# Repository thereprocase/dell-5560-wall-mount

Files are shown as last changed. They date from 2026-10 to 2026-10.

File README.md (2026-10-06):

# Laptop wall mount — Minimalist M1 and ducted Rev H

**9 September 2026 — Rev H D4 socket hotpatch:** [download and repair guide](https://thereprocase.github.io/dell-5560-wall-mount/revh-duct-d4.html). Corrects plastic crossing the four fan-cover pin sockets. Includes two Orca duct projects and the current editable CAD. Physical pin seating and removal still need confirmation. [Source and evidence](revh_duct_r4/README.md).

Two independent prototypes: **Minimalist M1** uses lighter open arms and fan
cradles with an optional indexed airflow dam; **Rev H** preserves the ducted
prototype and its already-printed arms. Future ducted revisions can change the
arms, size range and airflow adjustment too.

[Explore both designs](https://thereprocase.github.io/dell-5560-wall-mount/) ·
[Print and assembly guide](https://thereprocase.github.io/dell-5560-wall-mount/minimalist-guide.html)

## Rev H airflow videos - recorded continuation

**Moving particles and trails · about 1/200th speed · 60 fps:**
[Startup](https://thereprocase.github.io/dell-5560-wall-mount/simulation/revh-transient/sequence/latest-tracers.mp4) ·
[Already flowing](https://thereprocase.github.io/dell-5560-wall-mount/simulation/revh-transient/sequence/flowing/latest-tracers.mp4).

The startup continuation has stopped. Its native checkpoint and previous-step history are preserved for a later resume.
The startup video covers **96.2647 ms** of simulated flow.
The separate flowing-air video remains at 68.0934 ms.

| Simulation | Particle-flow video | Duration / download | Record |
|:--|:--|:--|:--|
| Startup | [MP4](https://thereprocase.github.io/dell-5560-wall-mount/simulation/revh-transient/sequence/latest-tracers.mp4) | 19.92 s / 4.31 MB | [Startup page](https://thereprocase.github.io/dell-5560-wall-mount/simulation/revh-transient/sequence/) |
| Already flowing | [MP4](https://thereprocase.github.io/dell-5560-wall-mount/simulation/revh-transient/sequence/flowing/latest-tracers.mp4) | 15.15 s / 3.46 MB | [Flowing page](https://thereprocase.github.io/dell-5560-wall-mount/simulation/revh-transient/sequence/flowing/) |

The videos use H.264 with fast-start metadata and one-second keyframes for
quick loading and seeking. The rounded speed label describes slow motion relative
to physical time; exact timing is recorded in each provenance file.

These stable links serve the latest published cumulative videos. The slower downloads have been retired. All recorded
samples and original videos remain preserved locally. Particle views interpolate saved
in-plane velocity at 60 fps; they show projected 2D motion with fading trails.
The visual continuation begins at the old 38.3188 ms video endpoint and uses
fixed 80.93 microsecond steps, one step per 60 fps video frame, with 12 workers.
CFD and video rendering are stopped. The run used idle priority and a shared
28 GiB RAM cap. Full native fields were saved at the final stop. Earlier native
branches and checkpoint provenance remain preserved. Timestep accuracy is deferred for this visual run;
the separate flowing-air sequence starts from an unconverged steady field.

## MakerWorld preparation package

[Agent handoff](MAKERWORLD_HANDOFF.md) · [Dated package, gallery, and downloads](makerworld/2026-09-08/)

Three listing drafts and sixty native Bambu Studio projects are archived while
physical prints and lab photographs are completed. The new profiles use 20%
gyroid infill and have virtual review only. All remain physically untested.

## Minimalist M1.1

[5560 native + print package](docs/downloads/Minimalist_M1_5560.zip) ·
[Fit coupon package](docs/downloads/Minimalist_M1_Fit_Coupons.zip) ·
[Editable nominal FreeCAD](minimalist/Laptop_Wall_Mount_Minimalist.FCStd) ·
[Six native size presets](minimalist/presets/) ·
[Construction and validation](minimalist/README.md)

The nominal complete set is **400.55 g / 15 h 42 m 30 s** in OrcaSlicer 2.4.2,
using P1S / ASA / 0.4 mm / 0.20 mm / 6 walls / 100% fill / 8 mm brim. That is
66.2% less estimated filament than the full Rev H set under the same process.
Times include each layout's plate overhead. These are slicer estimates, not
measured printing or cooling results.

Print one each of **01–08 plus 21_all_hardware**: nine plates. The twelve
individual files 09–20 are alternatives for replacement hardware, already
included on plate 21. STEP, STL and geometry-only 3MF are alternative formats.
The assembled STEP is for inspection. Keep the supplied print orientations.

All six dimensioned width/depth/thickness examples were recomputed at all nine
dam indices. Native geometry, intended 0.30 mm gaps, saved/reopened models,
STEP roundtrips, closed meshes and bed/brim/cutter clearance passed. Nominal
Orca paths have no disconnected floating components. The expanded screen
finds up to 8.99 mm of overhang-wall path without prior-layer support; the
bridge-tagged maximum is 3.02 mm. The coupon includes the fan-hanger and dam
slot interfaces in their full-part build directions. Physical fit, printed
retention, long-term ASA creep, anchors and cooling remain to be qualified.

### M1.1: carry the wall pad into the arm

Printing an arm on its side puts much of its load path within the layers, but
its wall pads extend beyond the arm’s 12 mm thickness. The original transition
left a small section just above that layer. The reinforcement grows each pad
from 24 to 32 mm tall and adds a pair of 6 mm webs, tapering 16 mm forward from
the pad face. Their roots run through the full arm thickness, including the
nearby window, so they begin at the bed instead of bridging onto a late layer.

| Original junction | Reinforced junction |
|---|---|
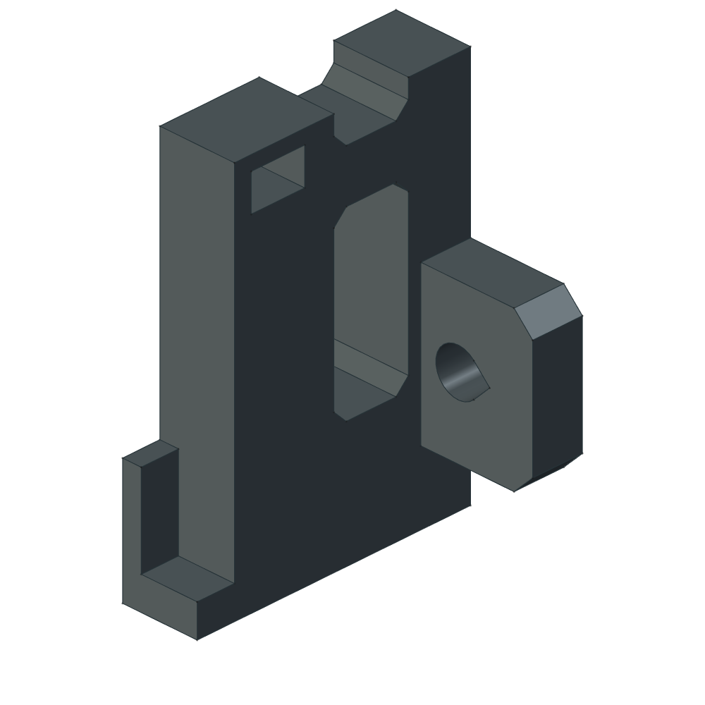
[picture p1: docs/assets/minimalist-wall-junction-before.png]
Original Minimalist wall pad and arm junction
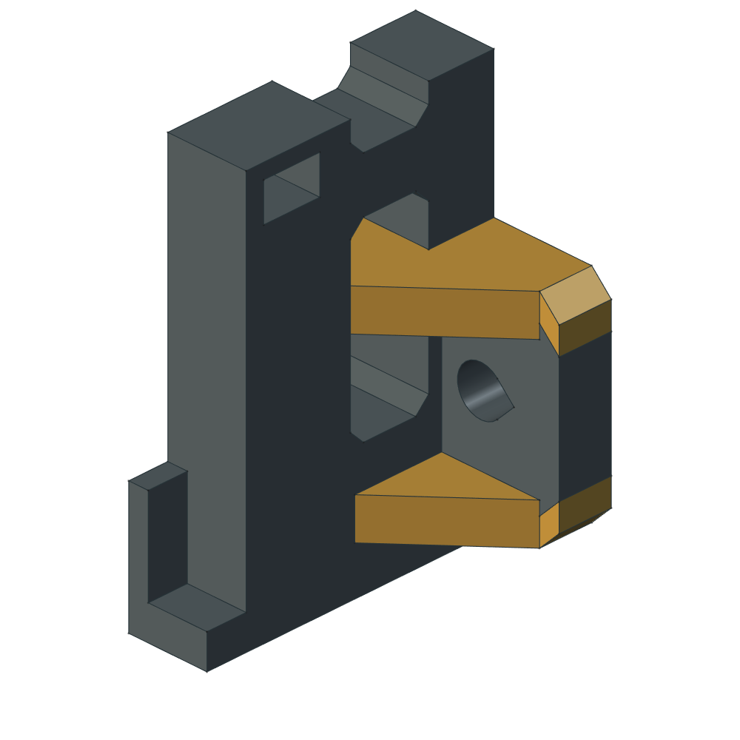
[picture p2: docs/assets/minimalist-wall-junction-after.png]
Reinforced junction with added material highlighted in gold
|  |  |

Gold shows added material in the native CAD comparison; the arm prints as one
fused part. Bolt centers and bores stay at their existing locations. The upper
dam has a matching tapered clearance notch so it can still traverse all nine
ladder positions. **Upgrade arms 01 and 02, plus dams 07 and 08 if using the dam**; the other sixteen
parts retain their geometry.

At a section just beyond the original 12 mm arm thickness, the material area
in each wall junction increases from **192 to approximately 416 mm²**. The
nominal arm pair adds **13.54 g of solid CAD** at 1.05 g/cm³. This is an area
comparison, not a claim of doubled tested strength: warm ASA, layer bonding,
fasteners and wall anchors still need physical qualification.

The revised complete set adds **12.50 g and 17 m 36 s** in Orca compared with
M1.0; the dam relief offsets a little of the extra arm material.

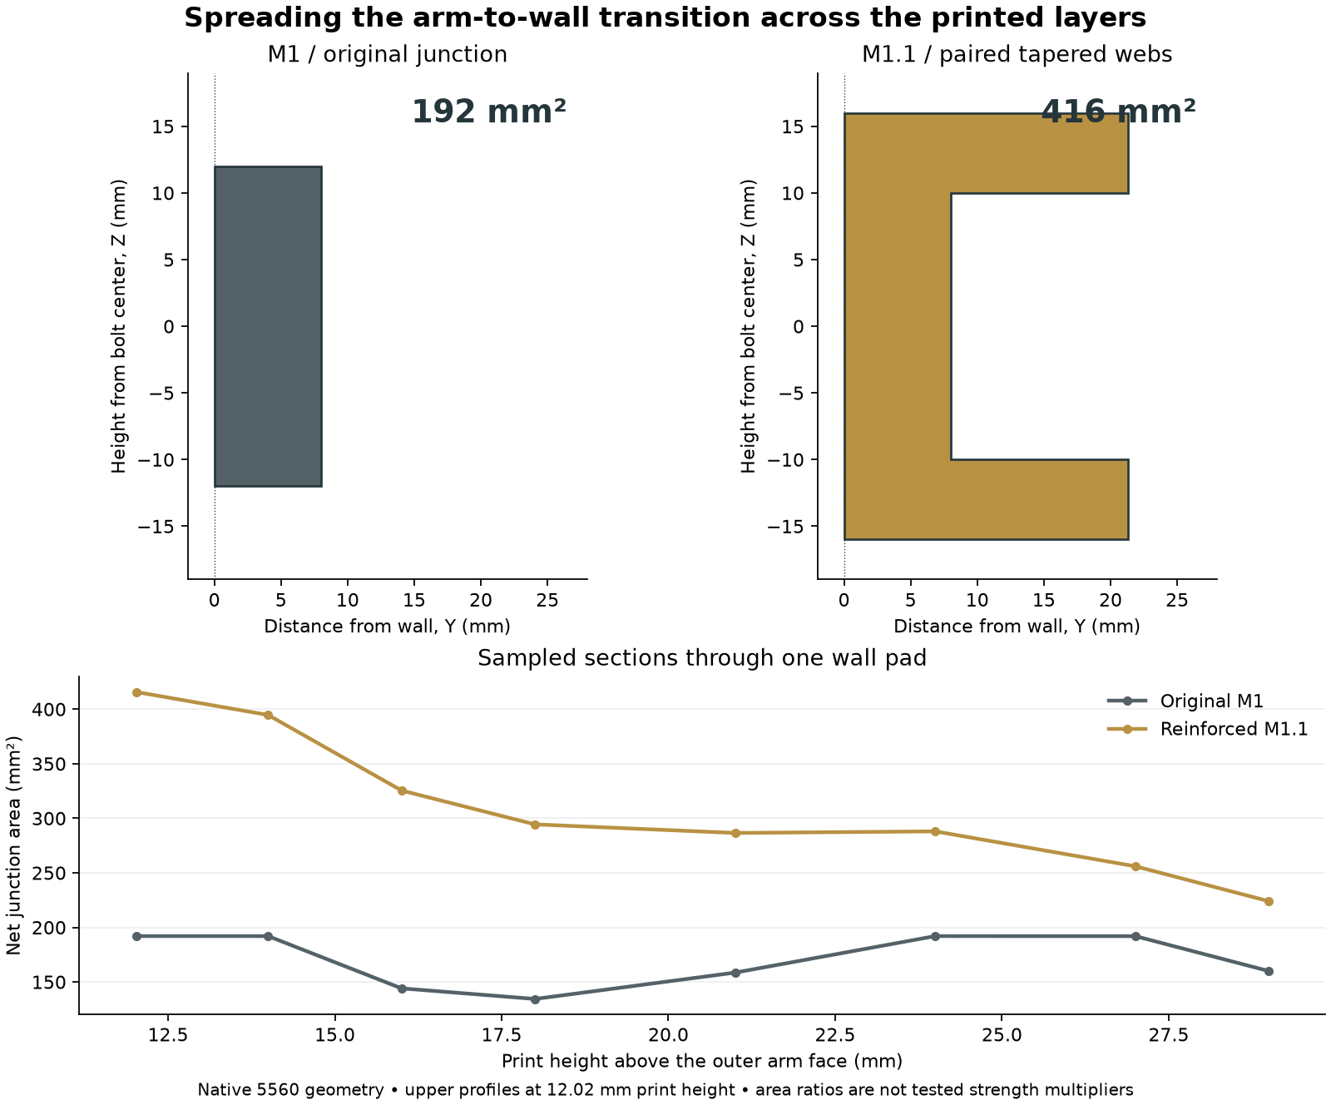
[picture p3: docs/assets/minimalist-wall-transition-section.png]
Actual print-layer sections before and after reinforcement


[Section data and assumptions](minimalist/reports/wall-transition-review.json) ·
[Native section calculation](minimalist/wall_transition_review.py)

## Ducted Rev H prototype

[All 14 print-oriented STEP files + corrected Orca previews](docs/downloads/Precision_5560_RevH_Prototype_STEP.zip) ·
[Orca bridge instructions](print_release_step/ORCA_BRIDGE_REVIEW.txt) ·
[STL/3MF print set](print_release/) ·
[Native FreeCAD](freecad/Precision_5560_Native.FCStd) ·
[Assembled STEP](freecad/Precision_5560_Native.step)

For ducts 03 and 04, keep the baked inlet-down orientation and set both
**Bridge direction and Internal bridge direction to 180°**, with Relative
bridge angle and Align infill direction to model off. Automatic direction
runs lengthwise along the slots. The corrected paths cross them, with a
maximum unsupported span of 5.19 mm and no disconnected floating components.
This is a toolpath screen, not an ASA bridge test. Re-slice for your spool.

The original `print_ready/`, root STEP, CadQuery source and Fusion/Onshape
ports remain **Revision F history/baselines**. Rev H's arm geometry is preserved
as prototype history; it is not a permanent constraint on later designs.

### H-R1: removable retention for your printed arms

[Interactive model and installation guide](https://thereprocase.github.io/dell-5560-wall-mount/revh-retainers.html) ·
[Four-part add-on and fit coupon](docs/downloads/Precision_5560_RevH_Removable_Retainers_R1.zip) ·
[Editable native model and engineering notes](revh_retention/)

Two external side bars and two keyed keepers retain the ducts and upper rails
without changing any of the fourteen Rev H parts. They engage existing arm
windows, so the already printed arms need no drilling or reprinting. Removing
one side bar releases both its duct and rail; support both while servicing.

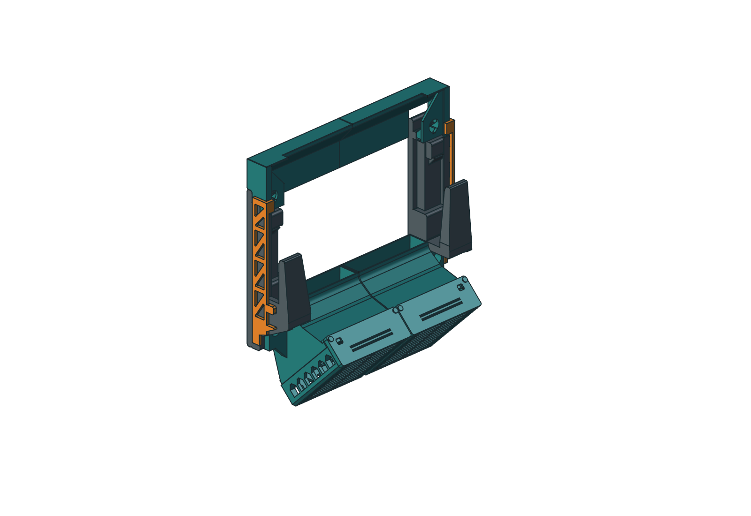
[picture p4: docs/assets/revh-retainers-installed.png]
Rev H with orange removable side bars and green keepers


Start with the short right-arm fit coupon. This is a CAD-checked prototype;
physical retention, bar stiffness and warm ASA creep still need testing.

### H-C1: edge-open fan cable grooves and zip-tie anchors

[Interactive cable-routing and print guide](https://thereprocase.github.io/dell-5560-wall-mount/revh-cables.html) ·
[Four replacement prints and corner coupon](docs/downloads/Precision_5560_RevH_Cable_Management_C1.zip) ·
[Editable native model and checks](revh_cables/)

Lay the wire into a rounded groove at the cover's mating edge, then fit the
cover. The tray closes the passage, so the connector stays outside. Two
external tie anchors on each tray route the wire along the outside rail and
remain in place when the cover is removed.

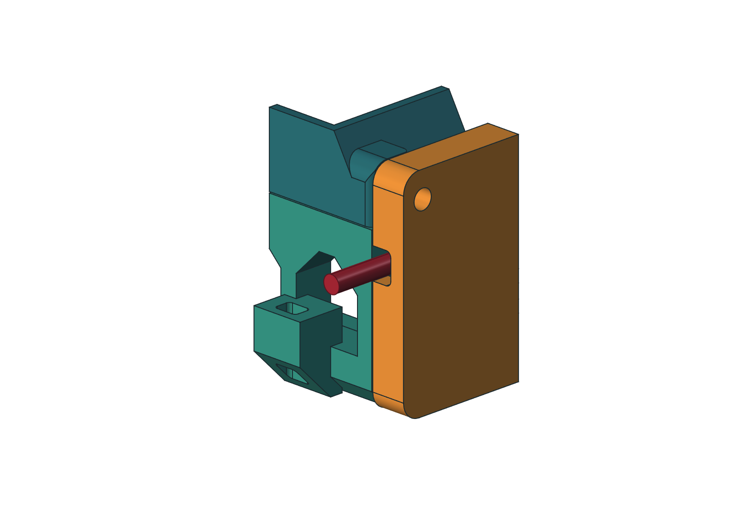
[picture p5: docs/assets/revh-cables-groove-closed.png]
Native cutaway of the new cover and tray enclosing a reference cable


Replace covers **05/06** and trays **09/10**. The printed arms, ducts, rails,
pins and optional H-R1 retainers are unchanged. Start with the corner coupon;
the 4 mm wire envelope and tie-tail access pass geometric checks, while actual
cable fit, abrasion and tie-lug strength remain untested. M1.1 is unchanged.

## How the shape was developed

The design story and its working images belong here alongside the finished
files. These stages describe the **original Revision F ducted prototype**:
its dimensions, fixed joints and historical simulation results are recorded
as they were developed. Minimalist M1 uses its own arms, shorter front tines
and removable ladder keys; use the current guide above for printing it.

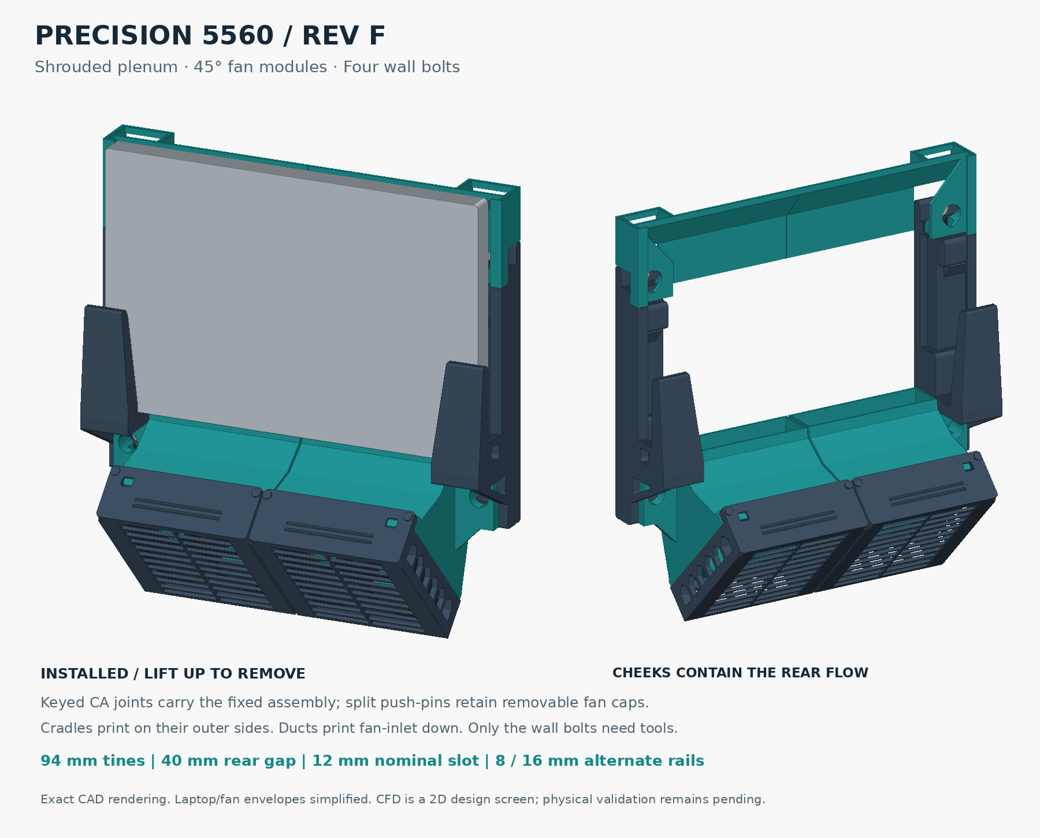
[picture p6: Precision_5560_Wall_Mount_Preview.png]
Original Revision F installed and empty assembly, rendered from CAD


### 1. Define fit and access

> “The hinge will go up so that the hot air escapes up and the fans can go on the bottom…”

The laptop sits vertically, underside toward the wall, with a 40 mm rear gap. A 344.4 × 230.3 × 20 mm envelope controls fit. The 26 mm bare slot allows for contact pads.

> “…make the tines on the front a little bit taller…”

The front tines are 94 mm tall. Four Ø7 mm wall holes face the room through clear Ø16 mm tool paths. We checked bolt access and laptop removal with the assembly in place. The laptop needs a 105 mm lift before moving forward; allow 110 mm overhead.

### 2. Support the laptop's intake

> “…doesn't have to seal, just has to be high pressure at vent high velocity beyond.”

The airflow goal became a plenum with a controlled outlet. Side cheeks limit leakage. A separate upper rail contracts the gap above the intake band, keeping the laptop vertical and the outlet width interchangeable.

Restricting the outlet can raise upstream pressure while reducing flow. The useful question was how much pressure each slot retained at the intake, and what exit velocity remained.

### 3. Locate the active vents

> “…download and scale images and cross sections of the machine to estimate its profile geometry?”

We scaled Dell side views and an inside-base-cover image against the published width and depth. The inside view revealed a covered center behind the broad exterior grille, leaving two estimated 70 × 40 mm intake regions near X = ±111 mm.

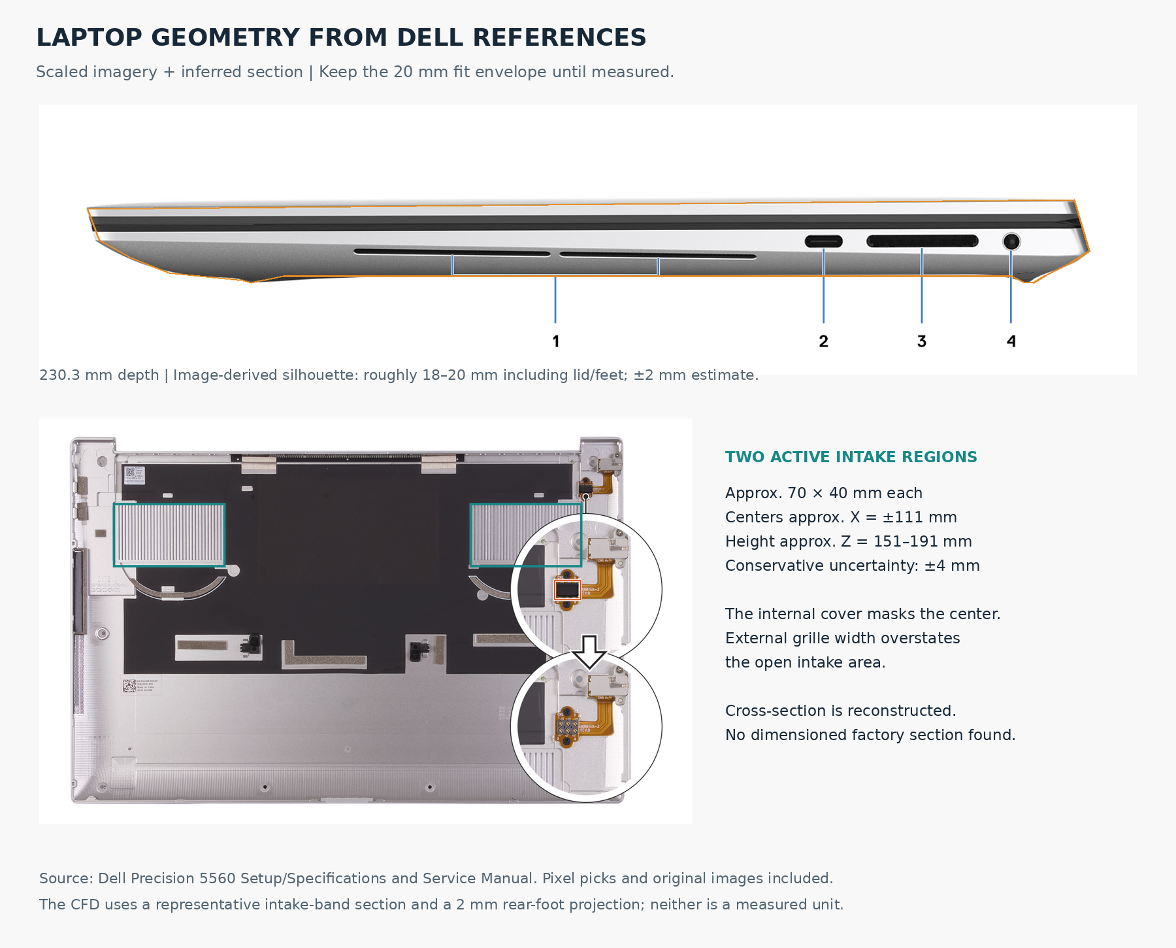
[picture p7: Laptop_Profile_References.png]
Scaled Dell references and estimated profile


The estimated intake band ends near Z = 191 mm, with ±4 mm location uncertainty. The contraction starts at 198 mm, reaches its throat at 226 mm and exits at 232 mm, near the hinge. No dimensioned factory section was found; the reconstructed profile has an estimated ±2 mm uncertainty. Check the actual machine before assembly.

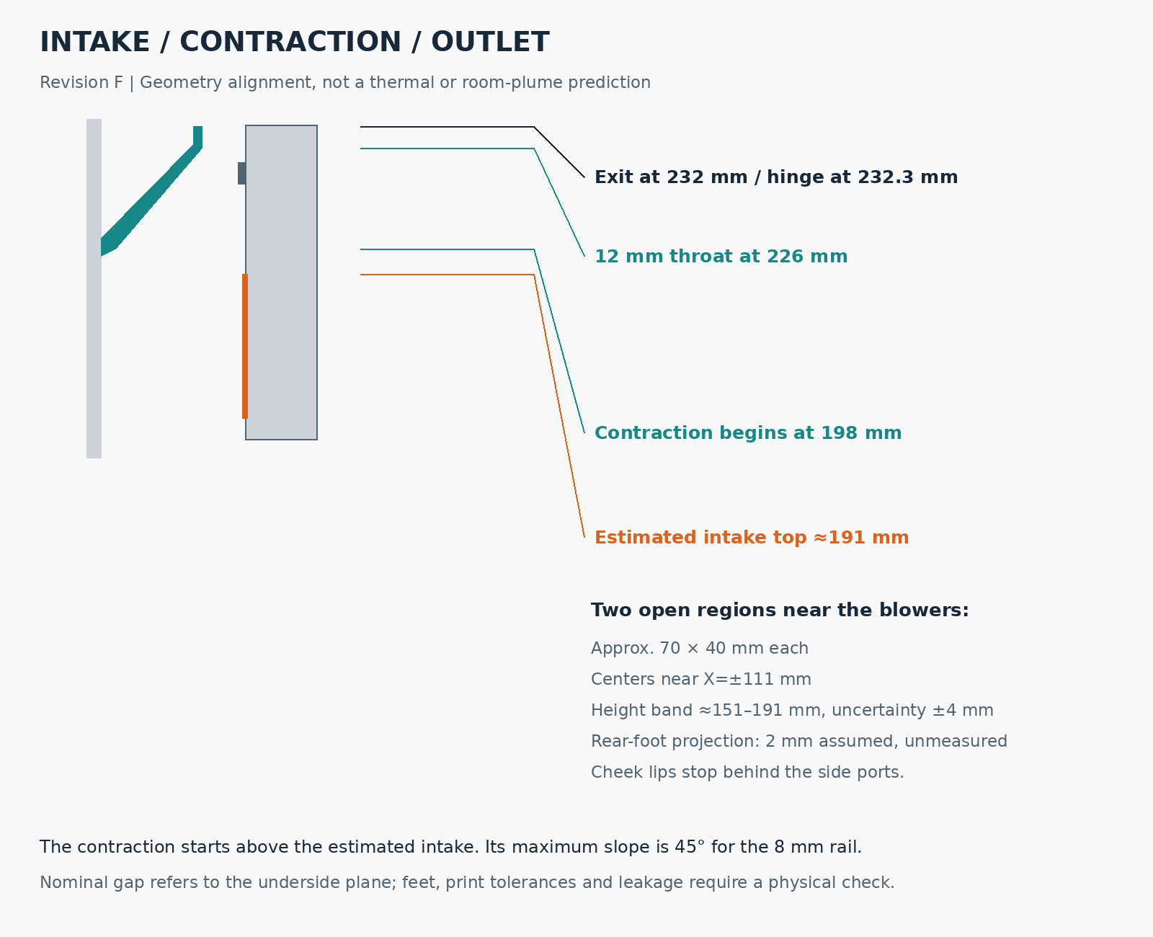
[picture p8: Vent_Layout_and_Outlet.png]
Image-derived intake band and original contraction/outlet stations


The [profile reconstruction data](profile_reconstruction.json) retain the pixel picks, scale factors, source hashes and uncertainty. The [estimated-profile STEP](REFERENCE_Estimated_Laptop_Profile.step) is the resulting reference shape, not manufacturer CAD.

### 4. Design for the print orientation

> “I would like to print the brackets on their side for strength, and not on their back.”

> “Also bridges are just fine, they're usually printable. Unsupported overhangs are bad.”

The brackets print on their outer sides. Ducts print inlet down; outlet rails print lip down. Sloped roofs support the next layer, while short bridges close box sections and dovetail grooves.

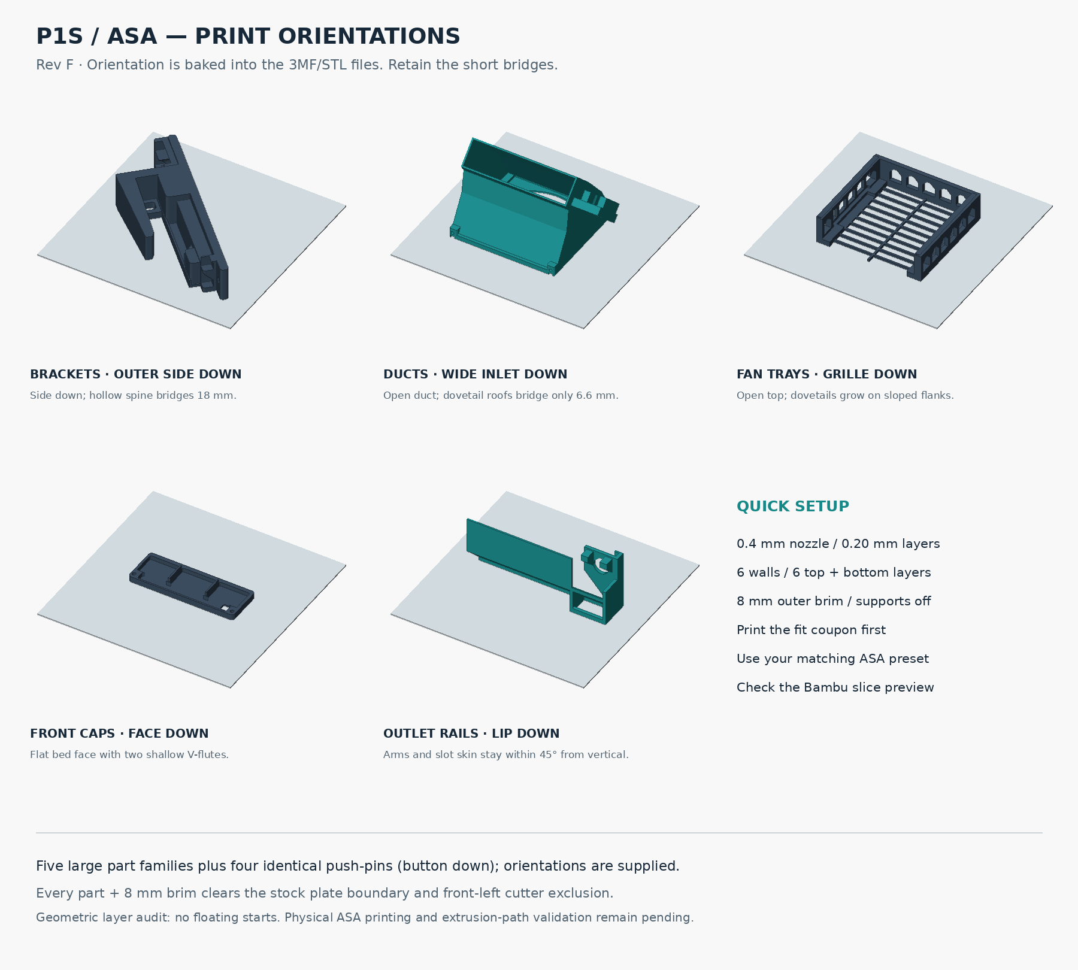
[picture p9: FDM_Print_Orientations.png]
Supplied print orientations


At the Revision F checkpoint, the 0.20 mm geometric layer audit found no floating starts and an 18 mm longest intentional bridge. Each part and its 8 mm brim fit the P1S bed and avoided the cutter exclusion. That was a geometry screen, before an actual slicer review. The later Rev H Orca review above caught a lengthwise bridge across a long slot and corrected its direction; physical ASA bridge quality still needs a print check.

### 5. Reduce material along the load path

> “I feel like we could get really creative and save a ton of plastic here.”

We hollowed the brackets, thinned the duct skins and pocketed the trays and caps. Material remains at bearing shoulders, bracket roots and wall holes. This used explicit geometry and section calculations; no topology or generative solver was run.

We extracted net section properties every 0.5 mm, including voids and unsymmetric bending. The structural screen uses a 2.5 kg laptop, 6 kg installation, 3g acceleration and a 50 N outward hinge pull. The minimum ratio of assumed stress limit to calculated stress is 1.19. This is a screening result; bonds, anchors and warm ASA creep remain unqualified.

Revision F uses **1,177.3 cm³ of solid CAD, 35.0% less than Revision D** at equal fill policy. The latest containment and assembly changes add 13.1 cm³ to the lightweight Revision E.

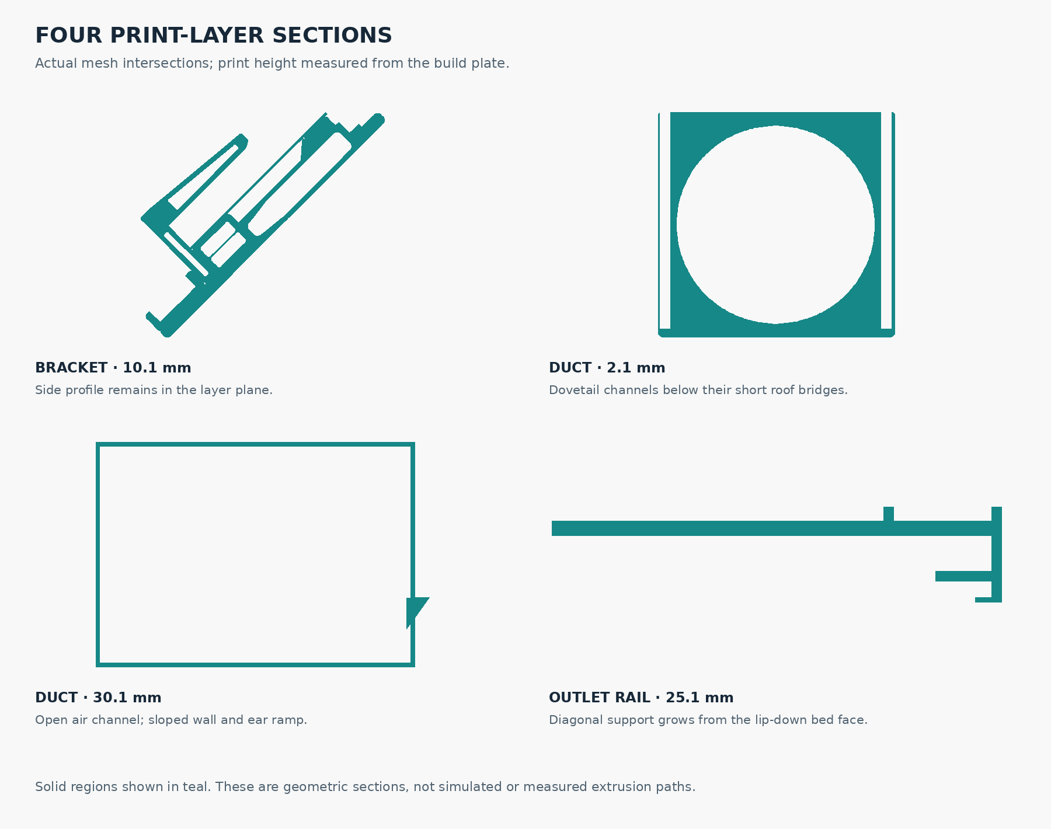
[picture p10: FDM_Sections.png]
Sections through the actual Revision F print geometry


### 6. Keep service parts removable

> “Can we also make it tool free / ca glue assembly, except for the four wall bolts?”

Keyed lap joints connect the fixed ducts and outlet rails. Their shoulders carry vertical load; CA resists withdrawal. Fan trays slide in dry, and two split pins retain each cap.

> “…have the fans angle down so they're blowing at a 45 to the gap instead of straight in?”

The fan intakes face down and outward. Air flows upward and wallward at 45°. Cheeks contain the rear flow while leaving side ports accessible.

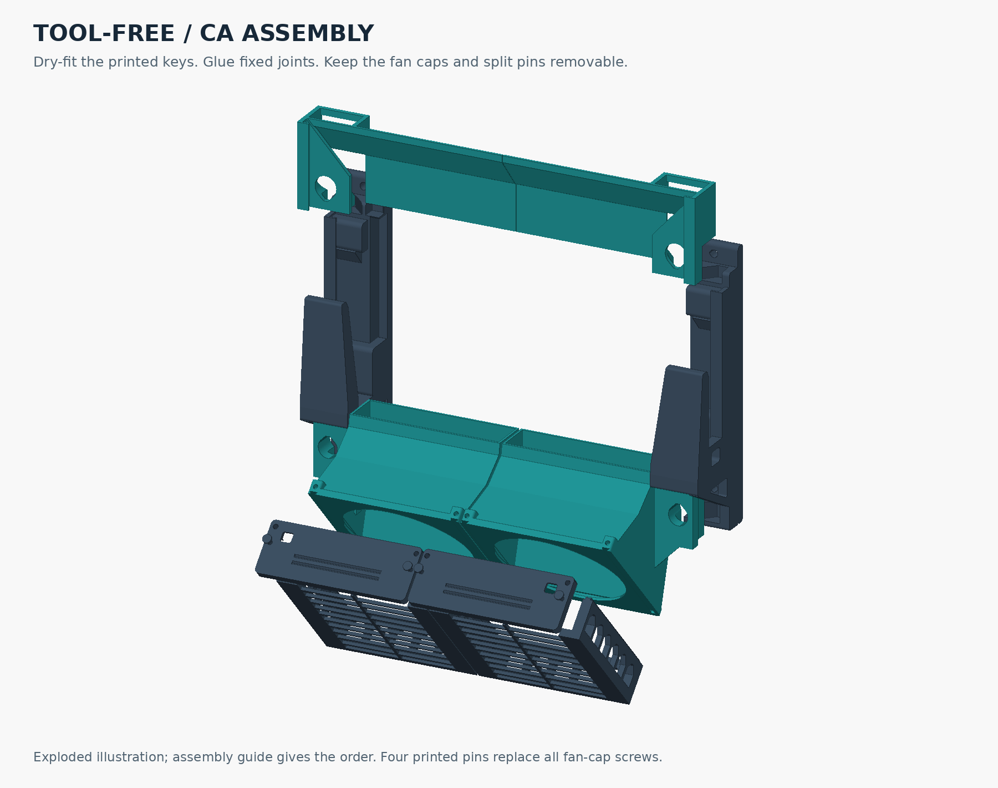
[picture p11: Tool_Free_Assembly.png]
Fixed joints and removable fan assemblies


The screened loads require 47.8 N of outward retention per duct and 7.4 N per pin. Adhesive and pin tests must establish that retention before service.

### 7. Compare the outlet slots

> “And do some cfd to design the plenum and slot?”

Eight OpenFOAM v1912 cases compare slot width, lower-turn geometry, mesh size, supply pressure and intake demand. The model uses steady incompressible RANS with k–omega SST in a sealed 2D section.

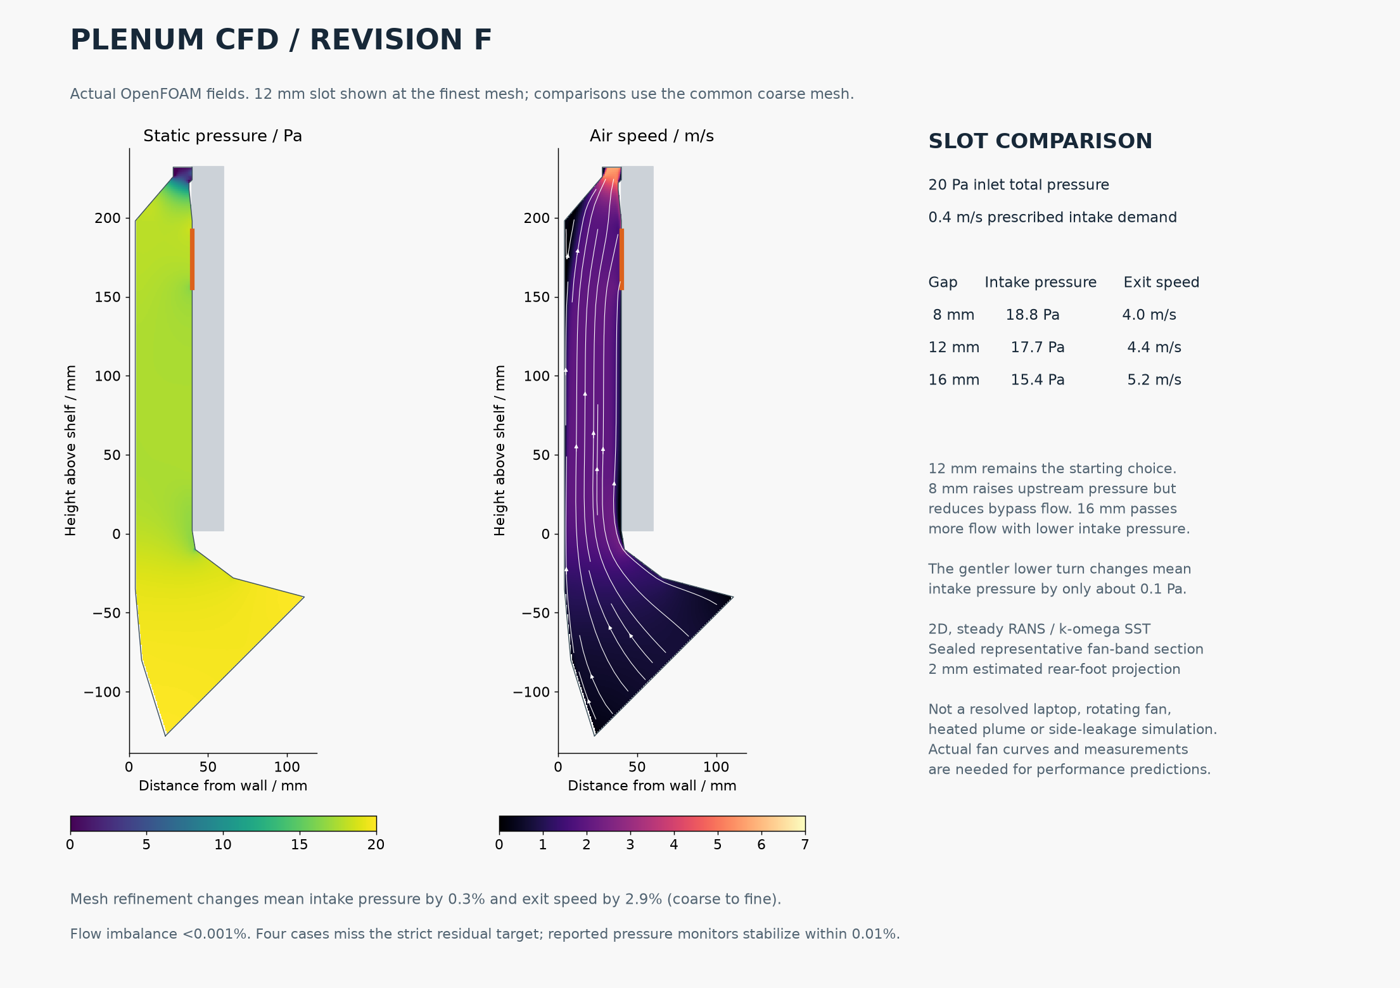
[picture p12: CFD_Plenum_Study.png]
Calculated pressure and velocity fields


At an assumed 20 Pa inlet total pressure and prescribed 0.4 m/s intake demand:

| Outlet | Mean intake pressure | Mean exit speed |
|---|---:|---:|
| 8 mm | 18.80 Pa | 4.01 m/s |
| **12 mm** | **17.67 Pa** | **4.42 m/s** |
| 16 mm | 15.43 Pa | 5.16 m/s |

The narrow slot retained more pressure; the wide slot produced a faster exit. We kept **12 mm** as the starting compromise. The curved lower turn improved intake pressure by only 0.11 Pa on the common mesh, giving little reason to refine the bend further before testing.

All meshes passed `checkMesh`. Flow imbalance stayed below 0.001%; mesh refinement changed mean intake pressure by about 0.3% and exit speed by 2.9%. Four cases missed the strict residual target despite stable mean-pressure monitors.

The model prescribes laptop intake flow and assumes fan pressure. It omits real fan curves, internal laptop resistance, side leakage, heat transfer and the room plume. The results compare slot behavior; actual cooling, total CFM and exhaust carry distance require measurements.

### 8. Specify the fits

> “what tolerances did you assume for slide to fit parts?”

The dovetail has 0.30 mm horizontal allowance per side, 0.30 mm crown clearance and 0.20 mm root clearance. Clearance normal to the sloping flank is smaller. Fixed-key pockets use 0.30 mm nominal offsets plus roof relief. Pins use a Ø4.0 mm shaft, Ø4.1 mm socket and Ø4.2 mm split crown.

No global ASA shrink correction is applied. Print the coupons, inspect elephant foot and adjust individual interfaces as needed. Full-length tray engagement also needs a warping check. See [TOLERANCES.md](TOLERANCES.md).

### 9. Reproduce and test

The workflow followed the interfaces: establish fit, reconstruct the vents, build the solids, check loads and service motions, audit print support, then compare airflow variants. [DIALOGUE.md](DIALOGUE.md) preserves the available prompts in order.

| Software | Use |
|---|---|
| Python 3.12; CadQuery 2.8.0 / Open CASCADE | Parametric solids, sections, STEP export and interference checks |
| NumPy; trimesh 5.1.0; Shapely 2.1.2; rtree; NetworkX | Mesh, layer support and connectivity checks |
| Pillow | CAD renders and reference-image annotations |
| Matplotlib; SciPy; VTK | CFD postprocessing and field plots |
| OpenFOAM v1912 | Meshing, mesh checks, flow solution and field export |
| Bambu Studio 2.8.2.61 profile sources | Historical Revision F starting settings; current preparation uses OrcaSlicer |
| Git / GitHub | Source, design files and analysis records |

[PROCESS.md](PROCESS.md) gives the commands; [requirements.txt](requirements.txt) records the Python dependencies. The [engineering report](ENGINEERING_REPORT.md) covers dimensions, assumptions, loads and verification.

Next: measure the laptop, print the coupons, test joint retention and warm structural behavior, then measure intake pressure and workload temperatures with the selected fans and outlet rails. Use those results to decide whether a coupled 3D or thermal model would change the design.

**Printing:** follow the [P1S ASA guide](P1S_ASA_Print_Guide.md), retain the supplied orientations and inspect the slice. Files are standard 3MF/STL models. Print the individual parts; reference STEP assemblies are for fit inspection.

## Rev H engineering history

Revision H adds three R12 internal tangent blends per duct and two R14 exterior
support blends. Inlet/outlet profiles, printed arms, and 0.30 mm interfaces
remain unchanged. The other twelve parts retain the prior release geometry.
See [flow validation](freecad/flow_validation.json) for sampled wall thickness
and inlet-down overhang checks. Cooling performance has not been measured.

- Closed rail roofs and end windows while retaining the exhaust slot and open back.
- Contoured the rail shoulder with 0.30 mm clearance to the frozen printed arm.
- Rounded exposed tips, matched cover outlines, and used print-aware corner bevels.
- Set the cap/duct/tray interfaces to measured 0.30 mm gaps on both sides.
- Corrected dovetail clearance normal to the sloping flank.
- Added separate editable native loft-skin patches to close the unintended duct-wall notches.
- Preserved pin retention, fixed mounting shoulders, screw access and service motions.

Final CAD checks: **14 valid solids, 176 fully constrained sketches**, zero
additional wall loss, unchanged frozen arms, and passing sampled service paths.
All 14 print meshes are closed and their oriented bounds plus brims fit the P1S.
Physical fit, retention and ASA bridging remain to be checked. Both duct
toolpaths have now been screened with the corrected Orca bridge direction.

[Fit-and-finish review](freecad/ADJACENT_FIT_REVIEW.md) ·
[Native model guide](freecad/README.md) ·
[Final acceptance JSON](freecad/complete_fit_review.json) ·
[Print manifest](print_release/manifest.json)

## Airflow research and technical drawings

Two 120 mm fans feed the rear plenum; the upper contraction directs bypass flow
past the hinge exhaust. The project includes the original 2D slot study and a
later exploratory 3D installed-flow case with traced laptop intake assumptions.

[Seven-sheet A3 technical review](docs/simulation/installed-airflow-2026-09-07/Precision_5560_CFD_Technical_Review.pdf) ·
[Drawing package](docs/simulation/installed-airflow-2026-09-07/) ·
[3D CFD run notes](fusion/cfd/TRACED_RUN_NOTES.md) ·
[2D CFD report](CFD_Design_Report.md)

The gallery is Revision F exploratory evidence. The [Revision H transient commissioning report](https://thereprocase.github.io/dell-5560-wall-mount/simulation/revh-transient/) includes an 18.2 million-cell mesh with 0.25 mm edge targets, raw samples, plots and a four-frame startup animation. Expanded mesh checks fail; the diagnostic restart completed only 0.0203084 ms of the planned 2 ms. Shedding, Bernoulli suction and validation are not established. The 3D
case uses uncalibrated constant-force fan assumptions, no thermal solution,
and did not meet its strict convergence target. It is not a measured hardware
performance claim.

## Project history

- [Minimalist workflow and reproduction](minimalist/README.md)
- [Original design narrative](docs/REVISION_F_DESIGN_STORY.md)
- [FreeCAD workflow notebook](freecad/RESEARCH_NOTES.md)
- [Fusion native port and CFD work](fusion/README.md)
- [Onshape pilot and API research](onshape/README.md)
- [Engineering report](ENGINEERING_REPORT.md) and [source attribution](SOURCES.md)

MIT licensed project. Dell reference images are attributed separately in
[SOURCES.md](SOURCES.md). Third-party viewer code retains its own MIT notice.
This project is independent of Dell, Bambu Lab and Autodesk.

## Final CFD results

[Final arrow maps, full probe histories and lip-flow data](https://thereprocase.github.io/dell-5560-wall-mount/simulation/revh-transient/sequence/final/) use preserved output through 96.26 ms startup and 69.44 ms flowing initialization. No further simulation was run. [Watch the final particle videos](https://thereprocase.github.io/dell-5560-wall-mount/simulation/revh-transient/sequence/).

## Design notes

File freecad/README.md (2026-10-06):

# Native FreeCAD wall mount

Open `Precision_5560_Native.FCStd` in FreeCAD 1.1.3. The source recipes and Revision F STEP files in the repository remain unchanged.

## Editing

- Double-click **Design parameters (mm)** to open the shared spreadsheet. Sections cover layout, structure, wall mounting, fan module, duct, outlet, fits, push pin and service.
- Edit blue input values in column B. Gray values derive from other inputs; overriding a formula deliberately breaks that relationship. Column D describes the actual dependency; column E records tests, not guaranteed continuous design ranges.
- **Installed assembly** contains fourteen links, grounded cradles, fixed joints and tray sliders. Part families have their own native construction groups. Expand the feature dependencies to edit constrained sketches, extrusions, lofts, rounded profiles, cuts and mirrors.
- SourceLocation on generated features identifies the preserved source recipe. PartKey and InstanceKey are stable identifiers; display labels are not identifiers.
- Geometry is in millimeters: X across laptop, Y outward from wall, Z up. Mirroring uses X=0. The native push pin uses Part Design; larger parts use standard Sketcher and Part features to preserve fillet-before-boolean construction.

## Evidence

- `final_native_validation.json`: original migration acceptance before the later user-requested finishing revisions.
- `FINISH_AUDIT.md`: current print freeze, six refined components, edit points, and validation evidence.
- `rail_refinement_validation.json`, `fan_finish_build.json`, `finish_cut_validation.json`: current finishing acceptance.
- `parameter_scenarios.json`: layout and fit cases pass; its fan-width failure predates the interface correction.
- `interface_scenarios.json`: corrected combined fan case passes regeneration and the four checked cradle interfaces.
- `fan_scenarios.json`: diagnostic isolation of the original fan-width binding failure.
- `parametric_validation.json`: historical individual sweep before rounded-profile repairs; not current acceptance. A successful nominal rebuild does not establish arbitrary parameter ranges.
- `clearance_validation.json`: independent exported STEP checks, including the original service-path samples.
- `reopen_validation.json`: independent FCStd reopen/recompute evidence, when present.
- `assembly_preview.png`, `parameter_sheet.png`: visual checks.
- `RESEARCH_NOTES.md`: working methods, failures, corrections and future-skill notes.

Earlier `native_validation.json` and `assembly_native_validation.json` are build-stage measurements. Queue receipts and recovery models retain the session's failures; they are not final acceptance evidence.

## Automation

`live_runner.FCMacro` runs a local queue on the GUI thread. A `.ready` file in `queue/` contains an absolute project-local Python path; completion produces a `.json` receipt and `.done` or `.failed`. No server or remote listener is installed. The runner and report-log timer can be stopped from the Python console with `App._mount_runner.stop()` and `App._mount_log_timer.stop()`.

Use `build_pin.py`, `build_families.py`, and `build_assembly.py` for construction. `native_ops.py` creates persistent stock FreeCAD features, and `design_bindings.py` adds dimensional dependencies to selected source recipes. The FCStd does not require these project modules to recompute its native geometry. Stock Assembly workbench Python modules are required for assembly joints, and ship with this FreeCAD installation.

Preserve a checkpoint before destructive rebuilds. Do not rerun the recovery scripts on a document with manual edits. All automated recovery in this session targets only this build's generated objects.

Do not send global keystrokes to control the GUI. Launch FreeCAD with the macro path or use its in-process GUI API. Do not read the live FCStd from another process while it is saving; use a completed snapshot for independent validation.

## Engineering boundary

This is a reconstruction and parametric CAD handoff. Existing structural, print and CFD evidence applies to the checked nominal Revision F geometry and assumptions. Edits require revalidation. Discrete geometric clearance checks do not prove uninterrupted collision-free motion, physical pin retention, adhesive strength, thermal performance or load capacity.

## Current checkpoint (2026-09-07)

The saved native document contains 40 shared aliases, 158 fully constrained sketches and 14 valid installed solids (11 modeled sources). Thirty fragile edge fillets were replaced with equivalent constrained rounded profiles and native extrusions. The assembly contains two grounded components, ten fixed joints and two tray sliders.

The tested layout case changes laptop dimensions to 346.4 x 231.3 x 20.5 mm, wall gap to 40.5 mm, tine height to 95 mm and wall-hole dimensions/positions. The fit case increases key/tray clearances and changes pin socket, cap passage and split width. Both regenerate without invalid features and preserve the four checked keyed interfaces. Exact inputs are in the reports.

The corrected fan case changes frame width to 120.5 mm, thickness to 25.5 mm, angle to 46 degrees, pivot to Y=67.5/Z=-83.5 mm, duct skin to 2.2 mm and grille bars to 2.6 mm. Fan width now changes the inlet while downstream sections retain the fixed cradle-interface width. The original binding widened all sections and caused about 180.819 mm3 interference per side. `fix_duct_interface.py` records the correction; `design_bindings.py` constructs it correctly for future builds.

Changed-case acceptance covers regeneration and the reported interfaces only. Full nominal clearance and sampled service checks are separate. These examples do not establish continuous safe parameter ranges or full clearance for every altered configuration.

The recovered Build_Recovery document is an older checkpoint. Continue editing `Precision_5560_Native.FCStd`. Automation must resolve the document by its absolute filename because the active document can change when the user selects another tab.

## Personal workspace and latest finish

The live GUI uses `fusion_ribbon.py`: Solid/Surface/Mesh/Sketch/Tools tabs, with Fusion-style Create, Modify, Assemble, Construct, Inspect, Insert and Select group order. Every mapped core command was checked against this installation. FreeCAD operation distinctions remain explicit in the menus: Part extrusion, Part Design Pad and Pocket are separate tools. Sheet Metal is disabled because its add-on is absent. This is a mapped native-command ribbon, not an exact reproduction of all Fusion workspaces or its timeline.

Navigation is Revit: middle-drag pans, Shift+middle-drag orbits, wheel zooms. `workspace_ui.py` supplies the coordinated UI styling and dock layout. `FUSION_GUIDE.html` is available in the ribbon. A small personal bootstrap is installed at `%APPDATA%/FreeCAD/v1-1/Mod/StudioWorkspace/InitGui.py`; rename that file to disable startup customization. Settings/layout backups are retained alongside the model. Latest solid background: #9EA6AD.

The local runner now holds an OS file lock so two FreeCAD processes cannot claim this project's queue. The user closed the duplicate session; the remaining session was verified to hold the latest saved rail refinement. The arms remain frozen. Revised component STEP/STL exports are in `print_refinements/`; these use installed assembly coordinates, so orient them for printing according to the source and finish-audit notes.

Latest adjacent-part review: [ADJACENT_FIT_REVIEW.md](ADJACENT_FIT_REVIEW.md). Revised, oriented P1S STLs: [print_refinements_oriented](print_refinements_oriented/). Original print_ready files are older geometry. Arms remain frozen.

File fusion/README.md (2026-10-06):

# Fusion native mount and CFD preparation

**Manufacturing release:** the selected Revision G print model is the FreeCAD
release in [print_release](../print_release/). This Fusion port and its CFD
helpers retain the Revision F baseline geometry.

## Revision F native port

The complete manufacturing port is in one Fusion document:
**Precision 5560 | Rev F | Native Engineering**. It contains 14 printed
occurrences, 13 native rigid assembly joints, 113 fully constrained manufacturing
sketches and 45 manufacturing parameters. The timeline is grouped by component
and construction stage, with component-family colors and associative mirrors.
The live checks reported no unhealthy features.

The six authored part families and all 14 placed parts passed source-geometry
comparisons. Every directional Boolean difference was empty; the assembly
introduced no new part intersections. Live parameter edit/restore checks passed,
including checks through the assembled mirrors. Evidence is under
`output/native/geometry_validation.json`, `assembly_geometry_validation.json`,
`parameter_checks.json`, and `assembly_parameter_checks.json`.

- Manufacturing archive: `output/native/Precision_5560_RevF_native.f3d`.
- Manufacturing-only exchange geometry: `output/native/assembly.step`.
- Extended archive: `output/native/Precision_5560_RevF_native_with_CFD_helpers.f3d`.
- Current traced-profile archive: `output/native/Precision_5560_RevF_traced_CFD_helpers.f3d`.
- Native helper recipe and roles: `native/cfd_helpers.py` and
  `output/native/cfd_helpers.json`.

The CFD helper component adds a vented laptop surrogate, wall, two Dell blower
actuator markers, and an intake porous-interface marker. Its sketches are fully
constrained and features healthy. These are editable analysis assumptions, not
measured Dell internal geometry. Hidden markers are omitted from the current
helper STEP export; their explicit recipe and role metadata remain authoritative.
Do not treat actuator/porous markers as solid flow obstructions.

Local archive export is verified; reopening those archives is not yet verified.
No cloud-save success is claimed. `native/finalize.py` predates the helper
component: do not rerun it blindly and overwrite the manufacturing-only exchange
export with analysis bodies included.

The latest helper replaces the generic envelope with the 14-point Dell side
trace from `profile_reconstruction.json`. Two traced active intake openings
replace the former full-width opening. Two assumed internal duct passages connect
these intakes to hinge discharge slots, each with a separate blower actuator
zone. `native/cfd_helpers_traced.py` builds this in the existing production
document; its sketches are fully constrained and features healthy. The traced
helper STEP includes all six bodies, including the two fan and two porous marker
bodies. See `output/native/cfd_helpers_traced.json` for roles and provenance.

The side-profile estimate retains its +/-2 mm uncertainty and the intake trace
its +/-4 mm uncertainty. Internal duct shape, fan curves and grille resistance
remain assumptions. The simulation records numerical fan forcing separately
from the visible native actuator markers.

## CFD software and trust evidence

See [vendor audit index](cfd/vendor/README.md) for download provenance, SHA256
manifests, installation status and repeatable integrity checks. BARAM 26.3.0's
per-user MSI installation completed; Microsoft MPI subsequently installed after
renewed approval. Both BARAM GUIs open and its bundled Windows solver passed a
400-cell cavity smoke test. `cfd/Launch-BARAM.ps1` supplies missing child-process
profile/MPI environment variables when launching from this automation host.
OpenCFD v2412 is installed in WSL Ubuntu and
passed an isolated official cavity smoke test. Fusion's Simulation workspace
showed an upgrade requirement; no upgraded subscription or simulation study was
created.

See [CFD preparation](cfd/README.md) for benchmark scope and current geometry
checks. No mount/laptop flow or thermal result has been established. Dell blower
curves, vent measurements, internal resistance and heat loads remain unknown.

## Historical pilot evidence

The following records the initial pin experiment, before the full native port.
Its remaining-work statements describe that earlier checkpoint.

User authorized launching Fusion, creating a new model, and experimenting within it on 2026-09-07. No additional Onshape requests are authorized by this work.

`FusionPinPilot/` contains a one-shot Python add-in. It creates a NEW document with a native pin component, sketch constraints and dimensions, revolve and split cut; exercises the head radius; restores nominal dimensions; then creates four positioned occurrences. It exports local STEP, PNG and F3D artifacts to `output/` and records either `result.json` or `error.json`.

## Verified result

The add-in ran automatically after the user launched Fusion. Fusion version `2704.1.36`; `output/result.json` reports success. Created a new model with four positioned pin occurrences and eight timeline entries (component/feature/occurrence history). Both solid features report healthy state 0.

- Axial profile fully constrained; split sketch NOT fully constrained. Split anchor/centering parameter behavior still needs refinement.
- Native nominal volume 204.56030211132358 mm3, bounds (-4,-4,0) to (4,4,14) mm.
- Head radius 4 -> 4.5 mm changed X/Y bounds to +/-4.5 mm and volume to 230.6983529891896 mm3. Radius restored to 4 mm; nominal volume recovered.
- Exported `output/Fusion_native_pin_assembly.f3d`, `output/Fusion_native_pin.step`, and `output/Fusion_native_pin.png`. PNG visually inspected.
- Existing FreeCAD/OCCT imported Fusion STEP as one valid solid. Volume 204.5603021147502 mm3 vs source 204.56030211045663 mm3; both directional Boolean differences empty after transforming original pin into local coordinates. See `output/geometry_comparison.json`.
- No Onshape calls. No existing Fusion model modified. Positioned occurrences are not assembly joints. The full mount and a human-edit preservation test remain future work.

The pilot is live verified, not just syntactically valid. Native archive is a local saved artifact; no cloud-save success is claimed.

Installed add-in location: `%APPDATA%/Autodesk/Autodesk Fusion 360/API/AddIns/FusionPinPilot`.

Installed Fusion executable found at `C:/Users/USER/AppData/Local/Autodesk/webdeploy/production/9c5312dfff2e4569cd1d269973ddf11cb999f782/Fusion360.exe`. Initial direct launch did not remain running; user offered to launch Fusion interactively. Do not repeatedly restart Fusion or disturb other documents.

If automatic loading does not occur, run **Utilities -> Add-Ins -> Scripts and Add-Ins**, find `FusionPinPilot` under Add-Ins and Run. `started.json` confirms add-in entry, not successful CAD construction. A custom event executes the work on the Fusion main thread after a short startup delay.

The script uses the installed Autodesk `adsk` Python API; it cannot run in ordinary system Python. `python -m py_compile` checks syntax only. Native Fusion regeneration, dimensions, exports and rendering must be verified inside Fusion.

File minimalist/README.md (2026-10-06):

# Minimalist M1.1 native fork

M1 is an independent open-frame prototype derived through a FreeCAD Save As of
the preserved Rev H document. Its arms, fan cradles, caps, dam and hardware are
new. No prototype arm freeze applies to this fork or to future ducted designs.

[Illustrated print and assembly guide](https://thereprocase.github.io/dell-5560-wall-mount/minimalist-guide.html) ·
[Interactive dimensioned examples](https://thereprocase.github.io/dell-5560-wall-mount/#m1-model) ·
[Nominal package](../docs/downloads/Minimalist_M1_5560.zip) ·
[Fit coupon package](../docs/downloads/Minimalist_M1_Fit_Coupons.zip)

## Reinforced wall transition (M1.1)

Each wall pad is now 32 mm tall with two 6 mm webs tapering 16 mm forward.
The webs reach the flat print face through the arm’s full thickness, filling
the adjacent window roots. Existing arm material, bolt centers, bores and
print orientation are preserved. The dam has a matching tapered clearance
notch; all six sizes pass all nine indexed positions.

When upgrading, replace arms 01/02 and optional dams 07/08 together. The other
sixteen parts are geometrically unchanged. The nominal full set is 400.55 g /
15 h 42 m 30 s in Orca, adding 12.50 g / 17 m 36 s compared with M1.0.
See the [illustrated comparison](../README.md#m11-carry-the-wall-pad-into-the-arm)
and `reports/wall-transition-review.json` for native layer sections and limits.
The 192 to 416 mm² section increase is not a tested strength multiplier.
To reproduce that comparison, extract `minimalist/presets/` from commit
`64fc1aa` to a separate directory, then run `wall_transition_review.py` with
`--baseline-dir` pointing to its six original preset directories. The current
native files stay untouched. `plot_wall_transition.py` renders the report.

## Open and edit

Open `Laptop_Wall_Mount_Minimalist.FCStd` in FreeCAD 1.1. The model contains
55 fully constrained sketches, stock Part construction features, a shared
Spreadsheet and 20 installed App::Links. It has no custom feature proxy that
must be installed to reopen or recompute it. Construction history is grouped by
part family; the installed assembly is separate from the hidden source features.

Open **M1 / Design parameters**, edit the blue measured case inputs, recompute,
and Save As a new file. Gray cells are derived. The parameter sheet documents
the 0.30 mm printed fit clearance and intentional split-crown interference.
The reference uses a 344.4 × 230.3 × 20 mm closed case, a 40 mm wall gap and
separate 2 mm compliant pads. The two cradles accept the modeled 120 × 120 ×
27 mm fan envelope and point it 45° up the rear gap.

The six checked examples in `presets/` span 304–400 mm case width, 210–275 mm
depth and 16–28 mm thickness. They are specific dimensioned examples, not a
continuous certified compatibility range. Screen diagonals are labels only.
Each preset has nine checked dam positions, indexed 0–8 on a 12 mm ladder.
All six delivered files also passed a live GUI open check with the installed
assembly visible and the source construction hidden.
The key engages two rungs 24 mm apart; both sides must use the same index.

## Files and plates

- `presets/<name>/M1.FCStd`: saved/reopened native preset.
- `presets/<name>/print/01–20`: individual oriented STEP, STL and standard 3MF.
- `21_all_hardware`: one plate containing all twelve parts numbered 09–20.
- `22_hardware_without_dam`: eight hardware parts; use with 01–06 for seven
  plates when omitting the optional dam.
- `M1_assembled.step`: installed assembly for inspection, not a print plate.
- `coupons/00_fit_coupon_plate`: compact samples of the actual key, keeper,
  arm/carriage, fan-hanger and cap-pin interfaces in their full-part build directions.
- `reports/release.json`: settings, slice estimates, source hashes and checks.
- `reports/toolpaths/`: deposited-path measurements and source G-code hashes.
- `section-review.json`: explicit load assumptions and nominal stress demand.

Print one each of 01–08 plus 21, for nine plates. Files 09–20 are replacement
alternatives; do not also print them. STEP, STL and geometry-only 3MF represent
the same part. The standard 3MFs have no slicer settings or G-code.

Each delivery ZIP includes an offline illustrated guide, native model, print
files, separately labeled Orca previews, settings and verified SHA256SUMS.
Nothing has been sent to a printer. Start with the coupon and your actual
ASA spool profile in OrcaSlicer; see the guide for orientation and assembly.

## Reproduce the checks

FreeCAD-side scripts use the application's bundled Python/modules. On Windows,
for example, use `"C:\Program Files\FreeCAD 1.1\bin\python.exe"` in place of
`FREECAD_PYTHON` below. Run from the repository root. Python paths are examples;
use the installation path on your machine.

```text
FREECAD_PYTHON minimalist/validate.py
FREECAD_PYTHON minimalist/presets.py
FREECAD_PYTHON minimalist/coupons.py
FREECAD_PYTHON minimalist/section_review.py
FREECAD_PYTHON minimalist/export_scene.py
```

Headless preset saves preserve the original GUI payload order through
`preserve_gui.py`, leaving geometry and parameter streams intact. Run
`gui_presets.py` from FreeCAD’s GUI Python environment to repeat the display
check before packaging regenerated files.

The construction builder is incremental and preserves existing part families.
For a clean reconstruction that leaves the delivered model untouched:

```text
FREECAD_PYTHON minimalist/build.py all --target minimalist/scratch/Rebuilt_M1.FCStd
FREECAD_PYTHON minimalist/validate.py --source minimalist/scratch/Rebuilt_M1.FCStd --output minimalist/rebuild-validation.json
FREECAD_PYTHON minimalist/compare_rebuild.py
```

`slice_models.py` uses the official Orca CLI and flattens its bundled P1S,
0.20 mm and ASA profiles. It preserves orientation/placement and never sends
a print. Example for the nominal set, with paths to your Orca installation:

```sh
python3 minimalist/slice_models.py --orca /path/to/OrcaSlicer \
  --profiles /path/to/resources/profiles/BBL \
  --output minimalist/slices/5560 \
  minimalist/presets/5560/print/0[1-8]*.stl \
  minimalist/presets/5560/print/21_all_hardware.stl
```

Repeat for each preset and the coupon. `audit_plates.py` requires Shapely and
Matplotlib. It analyzes all deposited path types, and reuses a result only when
the parsed path geometry, feature types, layer heights and widths are identical.
The package builder requires all six sets and the Rev H comparison slices:

```text
python3 minimalist/audit_plates.py
python3 minimalist/package_release.py --revh-slices /path/to/revh/comparison/slices
```

`browser_review.cjs` uses Playwright from `freecad/showcase/tooling` and Windows
Edge to check both interactive models, all presets, dam movement, mobile layout
and downloads. Install that folder's lockfile dependencies if needed, serve
`docs/` locally, then run it with the preview URL and `--full`.

## Evidence limits

Native validation checks valid one-solid parts, constrained sketches, unintended
part overlap, minimum intended interface gaps, rectangular case/fan envelopes,
wall intrusion and sampled removal motions. All nine dam indices are checked;
case and fan removal samples are run at the two end indices. A clean CAD result
does not prove a continuous insertion path with cables or real protrusions.

Orca's Bridge label excludes some slot roofs generated as Overhang wall. The
expanded toolpath report therefore includes every deposited feature type and
retains bridge-tagged and all-feature maxima separately. Prior-layer support is
estimated from reported line width with at least 0.05 mm overlap. Same-layer
anchoring order, adhesion and physical sag are not proven. Use the fit coupon
to check the key-slot roofs and the fan hanger before the full print.

The section review assumes a 3 kg case, twice gravity and equal arm loading.
It calculates net upright areas and section moments from native solid slices.
The peak nominal axial-plus-bending demand is about 1.11–1.24 MPa across the
examples. This excludes local stress concentration, shelf/fastener FEA, ASA
allowables, creep, temperature and layer adhesion; it is not a load rating.

Physical fit, printed retention, wall anchors, long-term deformation and cooling
performance remain unqualified. M1 has no CFD or cooling benchmark. Rev F's
exploratory CFD must not be presented as a result for M1 or Rev H.

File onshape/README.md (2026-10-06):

# Native Onshape rebuild

**Status: native push-pin pilot built and tested; full mount rebuild remains unfinished.**

The 2026-09-07 exploration used 34 of 40 authorized request attempts. The document now has a constrained native pin, 38 shared variables and four positioned pin instances in its Assembly tab. See [EFFICIENT_NATIVE_WORKFLOW.md](EFFICIENT_NATIVE_WORKFLOW.md) for tested batching methods, validation limits and the next execution plan, and [RESEARCH_NOTES.md](RESEARCH_NOTES.md) for the running evidence notebook.

Current user direction: each distinct part gets its own Part Studio tab, with reusable instances in an Assembly. The grouped family descriptions below remain construction guidance; handed parts should occupy separate tabs.

Target: [Dell Precision 5560 Wall Mount - Native Rebuild](https://cad.onshape.com/documents/c452b7f3224726ea2f11cdda/w/3231ffbfcf00782c1dba2494).
Created on 2026-09-07 with one API request (HTTP 200); IDs saved in local ignored `.env`.
See [MCP_WORKFLOW.md](MCP_WORKFLOW.md) for connection status, quota constraints and the modeling workflow.

The current Revision F source is CadQuery. STEP carries its boundary geometry, but the native Onshape deliverable must reconstruct the design history and relationships. This directory records that reconstruction so it can proceed in a session with authenticated Onshape access.

## Deliverable structure

| Tab | Contents |
|---|---|
| Design variables | Shared dimensions and fit allowances from `design_parameters.json` |
| Layout | Wall plane, symmetry plane, laptop envelope, vent band, fan planes, bolt centers and service directions |
| Cradles | Right cradle plus a native mirror for the left |
| Fan ducts | Right duct plus mirror |
| Fan trays | Right tray plus mirror |
| Fan caps | Right cap plus mirror |
| Outlet rails | Right rail plus mirror; 8 / 12 / 16 mm configurations |
| Push pin | One reusable pin part |
| Installed assembly | Ten handed parts and four instances of the pin: 14 printed instances |

The working geometry should use ordinary constrained sketches, extrudes, removes, lofts, patterns, mirrors and fillets. Keep those features named and individually editable. Use shared variables and layout references for mating interfaces. The supplied STEP is the baseline for comparison, not the source feature of the native design.

A custom FeatureScript can automate repetitive work if needed. A single custom feature containing the entire mount would not provide the ordinary feature-tree editing specified here.

## Feature structure

### Layout and variables

Coordinates remain X across the laptop, Y outward from the wall and Z upward. Set the wall at Y = 0 and the symmetry plane at X = 0. Establish mating references from this skeleton before adding pockets or fillets.

The current Python geometry contains hard-coded coordinates alongside named dimensions. Native variables therefore require dependency refactoring; changing one existing Python constant is not sufficient to move every mating face coherently. Rebuild the relationships explicitly, starting from the current nominal dimensions.

### Cradles

Source: `base_geometry.py: right_cradle()` and `build_mount.py: right_cradle()`.

1. Constrain the side profiles for the wall back, shelf, lower pad, front tine and upper support.
2. Extrude the structural sections to their specified widths; retain the tapered tine and diagonal gussets.
3. Add the duct saddle receiver, outlet receiver, side cheek and inward lip.
4. Cut the two wall holes and the lower tool clearance with their printable roofs.
5. Cut the spine, shelf and tine cavities and the web windows. Preserve the side-print skin thicknesses.
6. Cut the duct and rail key pockets using the shared key definitions and clearances.
7. Apply the original outline and cavity fillets at the appropriate construction stage. Some fillets precede booleans in the source; moving all fillets to the end may change the shape or fail.
8. Mirror the finished right cradle across the layout symmetry plane.

### Fan ducts

Source: `build_mount.py: loft_channel()` and `right_duct()`.

1. Define the four outer section profiles in the layout. Construct the inner profiles from their specified insets.
2. Reproduce the ruled outer and inner lofts and subtract the inner volume. A smooth global loft would change the existing plenum.
3. Build the fan deck, inlet aperture, side bosses, dovetail grooves and pin sockets in the fan coordinate system.
4. Position the deck from the shared fan plane.
5. Add the keyed saddle and sloped buttress, then cut the wall-bolt tool corridor.
6. Mirror the completed duct.

If the Onshape loft interface cannot reproduce the same ruled transitions in one feature, loft adjacent profile pairs with straight transitions and join them. Compare the resulting surfaces with the STEP baseline.

### Fan trays

Source: `base_geometry.py: right_tray()` and `tongue()`; placement in `build_mount.py: tilt()`.

1. Build the tray frame, fan ledges and end stop in the fan coordinate system.
2. Add the grille bars and central support with native patterns.
3. Add the two male dovetails using the same master section as the duct grooves.
4. Cut the side and end windows and ledge pockets.
5. Position the tray from the shared fan plane and mirror it.

### Fan caps

Source: `base_geometry.py: right_cap()` and `build_mount.py: right_cap()`.

1. Extrude the cap outline and locating toe.
2. Cut the face flutes, cable notch and pin passages.
3. Pocket the rear while preserving the face, perimeter and ribs.
4. Apply the source corner radii, position from the fan plane and mirror.

### Outlet rails

Source: `build_mount.py: right_rail()` and `tenons()`.

1. Sketch the lower panel, contraction and outlet lip in the YZ plane.
2. Drive the throat from `outletGap`, with configuration choices 8, 12 and 16 mm.
3. Add the support arm, cheek, inward lip, top link and end rib.
4. Add the keyed attachment from the shared rail-key geometry.
5. Remove the wall-bolt corridor and cradle overlap relief.
6. Mirror the rail. Couple both halves to the same outlet configuration.

Keep the contraction start, throat and outlet heights explicit. Any changes must be checked against the vent band and the intended lip-down print orientation.

### Push pin

Source: `build_mount.py: pin()`.

1. Extrude the button and chamfer its upper edge.
2. Extrude the shaft.
3. Loft the retaining crown to its smaller tip.
4. Cut the axial split.
5. Use four instances in the assembly.

## Assembly and service states

Use explicit mate connectors tied to layout planes and interface centers. Avoid transient fillet edges as mating references.

- Locate both cradles from the wall layout and fix them in the installed assembly.
- Fasten each duct and rail to its cradle at the seated keyed joint.
- Give each tray a slider along its dovetail direction for service inspection. At 45°, the outward removal direction is `(0, +1/sqrt(2), +1/sqrt(2))`.
- Fasten the caps and pin instances in the installed state; use an exploded/service view to show removal.
- Keep the laptop and fan envelopes as reference components excluded from the printed-part count.
- Check the laptop with a 105 mm vertical lift followed by outward movement. This is a two-stage removal path, not a single unrestricted slider.

The fixed joints represent CA assembly. Assembly mates do not establish adhesive strength, pin retention or physical clearances.

## Native acceptance checks

`revision_f_baseline.json` preserves the current part volumes, bounding boxes and fit results, linked to source and STEP hashes.

1. Regenerate all native features without errors at the Revision F defaults.
2. Confirm 11 distinct modeled parts: five mirrored pairs and one pin; confirm 14 printed instances in the assembly.
3. Export the assembly to STEP. Compare each part's volume, bounds and symmetric geometric difference against Revision F. Matching volume alone is insufficient.
4. Investigate any differences above CAD numerical noise. Do not label a changed loft or omitted fillet an exact conversion.
5. Repeat the wall-driver, laptop, fan, tray and joint insertion checks from `validate_assembly.py` against the native export.
6. Check both outlet alternatives and several small changes to the exposed dimensions. Verify that mating parts update together and do not introduce interference or unsupported print geometry.
7. Confirm the default native export still supports the supplied print orientations. Re-run the layer and strength checks after geometric changes.
8. Save a named Onshape version of the validated nominal design and document which parameter changes were exercised.

The existing structural and CFD results apply to the checked Revision F geometry and assumptions. Native parameter edits need appropriate revalidation.

## Access required to continue

An authenticated Onshape API integration with document read/write access is needed to create the Part Studios, assembly and configurations, and to verify regeneration and exports. A document URL identifies the destination but does not authenticate this session.

Official references: [Onshape feature API](https://onshape-public.github.io/docs/api-adv/featureaccess/), [FeatureScript](https://cad.onshape.com/FsDoc/), [standard library](https://cad.onshape.com/FsDoc/library.html).

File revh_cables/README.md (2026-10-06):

# Rev H-C1 fan cable routing

Four replacement prints for the preserved Rev H mount: covers 05/06 and trays
09/10. The covers have an open groove in the rear/outboard mating edge. A cable
can be laid into that groove before the cover is fitted; the tray closes the
passage. The former closed front-face cable hole is filled. The connector stays
outside and does not pass through a hole.

Each tray gains two external zip-tie anchors, one near the cable exit and one
farther back along the outboard rail. Ties remain on the tray when the cover is
removed. The cable must be unplugged and freed from any off-tray attachment
before withdrawing the tray itself. Avoid tightening ties against the cable's
insulation or using these anchors to restrain the fan or another load.

[Illustrated guide and interactive model](../docs/revh-cables.html) ·
[Native FreeCAD](Precision_5560_RevH_Cable_Management_C1.FCStd) ·
[Print geometry](print/) · [Native validation](validation.json)

The native file is a Save As of the complete H-R1 assembly. Fourteen of its
eighteen installed parts are unchanged: both printed arms, ducts, rails, four
original cover pins, two H-R1 bars and two H-R1 keepers. The C1 replacement
covers and trays also work without the optional H-R1 retainers. Original Rev H
and H-R1 source files and downloads remain preserved. Minimalist M1.1 is a
separate design and is not changed by this release.

Print `00_cable_fit_coupon.3mf` first. It contains actual cropped cover/tray/duct
corners and one original pin. These reproduce the mating seam, open cable
groove, nearby tie anchor and original latch. Cover, tray and pin use their
full-part print directions. The short duct coupon prints front mating face down
to avoid a roof overhang created by cropping; it checks fit, not the original
duct's print orientation. The installed duct is unchanged.
After fitting the coupon, print `20_both_cable_covers.3mf` once and one each of
`09_left_fan_tray.3mf` and `10_right_fan_tray.3mf`: four replacements on three
plates. Individual covers 05/06 are alternatives to plate 20, not additional
parts. STEP, STL and geometry-only 3MF represent the same shapes.

Use OrcaSlicer, P1S, ASA, 0.4 mm nozzle, 0.20 mm layers, six walls, six top and
bottom layers, 100% rectilinear infill, Arachne walls, 8 mm outer brim and
supports off. Keep the supplied orientation and 100% scale. The coupon includes
the original duct interface: use 180 degrees for both bridge directions, with
Relative bridge angle and Align infill direction to model off. The full C1
cover/tray review uses automatic bridge direction. Use your actual spool's
temperature and drying instructions, then inspect the slice.

The checked wire is a 4 mm round envelope with 0.5 mm minimum installed gap to
the cover and tray. The outer wall groove is nominally 7 mm high and 5 mm deep
to its mating surface, with 1.2 mm corner radii. The opening is clearance for a
cable, not a clamp or a fluid seal. Check actual wire shape, jacket condition,
first-layer expansion and burrs. Larger bundles require a revised feature and
renewed clearance/print checks.

Each tie anchor projects 8 mm beyond the previous tray side, begins at the
grille-down print base and grows outward on a 45-degree underside. The local
fan-frame Y positions are 119 and 51 mm. A rounded 4 × 5.5 mm vertical slot
accepts the checked 1.5 × 3.6 mm tie-tail envelope with access to both ends.
Slot corner radius is 0.8 mm. This is a geometric fit, not a qualified tie-lug
force rating. Route wire outside the fan envelope and leave service slack.

`build.py` constructs the new features from constrained sketches, stock Part
extrusions, fillets, booleans and mirrors; the saved model needs no custom
feature proxy. The original native feature history remains present and hidden.
`validate_export.py` independently reopens and recomputes the saved model,
compares the preserved parts, checks cable capture and side-entry access,
samples cover/tray removal, checks fan/laptop envelopes, and exports/reimports
STEP and mesh files with P1S bed/brim checks. `render.py` captures actual native
geometry, with a separately labeled red cable reference.
`validate_service_animation.py` separately checks removed pins parked above
the cover path and cover travel through 35 mm; the viewer uses that sequence.

This is a fixed-size upgrade for the preserved Rev H snapshot. Editing the old
parameter sheet does not automatically adapt the cable features. Recheck
changes to groove, mating surfaces, anchor dimensions or fan envelope.

Physical cable fit, repeated service, cable abrasion, tie-lug strength and warm
ASA behavior remain untested. The original mount's retention, wall anchors,
load capacity and cooling still need physical qualification. The original
Rev H ducts and CFD records are unchanged; C1 adds no airflow or cooling result.

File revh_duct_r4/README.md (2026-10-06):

# Rev H D4 socket hotpatch

D4 clears the four blind sockets for the fan-cover push pins. The earlier duct
construction cut the bosses, then fused in a sloping shell that crossed the
holes. D4 repeats the original parametric cuts after the completed union.

[Print and repair guide](../docs/revh-duct-d4.html) ·
[Download the hotpatch](../docs/downloads/Precision_5560_RevH_D4_Socket_Hotpatch.zip) ·
[Editable current FreeCAD model](Precision_5560_RevH_D4_Current.FCStd)

## What to use

Open the two projects under `slices/` as **OrcaSlicer projects**. They contain the
reviewed orientation, settings, support enforcer and G-code for a Bambu Lab P1S,
0.4 mm nozzle and Polymaker PolyLite ASA. Review them for the actual printer and
spool before printing. `print/` contains equivalent STL, STEP and geometry-only
3MF alternatives; those do not contain the complete process setup.

This download supplies **two replacement ducts**. The current native assembly
also includes the previously developed D3 duct reinforcement, T3 tray fit,
R2 retainers/keepers and two optional B1 rear baffles. Those surrounding fit
revisions are newer than the earlier public C1 native snapshot. The D4 change
itself is measured against the exact prepatch assembly in `baseline/`.
Existing duct-to-tray grooves and arm interfaces are preserved by the D4 cut.

For already printed ducts, read [REPAIR.md](REPAIR.md): a 4.1 mm hand bit with
maximum **6.0 mm tip depth from the duct socket face** can clear the modelled
obstruction while retaining the blind bottom. Physical cleanup success, pin
seating, retention and removal remain unconfirmed.

## Evidence and limits

- [Native comparison](build-report.json): 20 valid installed solids. Only the
  two ducts change, removing approximately 42.08 mm³ each inside the original
  bores. The other 18 installed solids match the bundled prepatch baseline.
- [Final native validation](final-validation.json): reopened and recomputed;
  both local bores are clear and all four pins pass nine sampled withdrawal
  positions. Only the actual split crown is allowed to overlap.
- [Parameter edits](parameter-validation.json): socket diameter and side-root
  radius change and restore successfully. Socket diameter intentionally sizes
  the matching pins too. Near-coincident root fillets exposed an OCC reverse-Cut
  inconsistency; the bounded Common-volume check and diagnostic records explain
  how that case was measured. Default restoration uses both directional Cuts.
- [Left](reports/03_left_fan_duct.json) and [right](reports/04_right_fan_duct.json)
  toolpath audits: exported/prepared/sliced meshes match; no floating model or
  support islands; maximum unsupported deposition span approximately 6.44 mm.
  The socket test detects the old obstruction and finds no model/support paths
  in the same four-layer passage samples in D4.
- [Printed-part repair envelope](printed-repair-validation.json): 90°, 118° and
  135° drill points pass nominal checks at the 6.0 mm tip limit.

The nominal bores remain 4.1 mm diameter and 7.7 mm blind depth. **7.7 mm is not
a drill-tip depth instruction.** These are geometry and toolpath checks, not
physical qualification of printed dimensions, strength or pin forces.

## Reproducing the correction

The construction uses stock FreeCAD features, so the saved model reopens
without project Python code. The original 897 object names are retained; D4
adds a group, compound of the original cutters and final Cut.

`build.py` runs in a FreeCAD Python environment. It reads the checked baseline,
refuses to replace an existing D4 candidate, then validates and exports. Preserve
or move the supplied candidate before rebuilding. `socket_fix.py` contains the
actual correction and checks. `validate_parameters.py` never saves its trial edits.

Headless `saveAs` omits GUI data in this FreeCAD build. `preserve_gui.py` restores
the original view providers, colors and camera, adds three hidden D4 providers,
and checks every geometry archive member is byte-identical. See
[gui-preservation.json](gui-preservation.json). The final model was also opened
and visually inspected in the real FreeCAD GUI.

`prepare.py` replaces only the mesh in the historical Orca templates. To slice:

```text
python revh_duct_r4/slice.py --orca /path/to/OrcaSlicer --orca-profiles /path/to/resources/profiles
```

The slicer wrapper uses the repository's `minimalist/slice_models.py`. Run
`python revh_duct_r4/audit.py` with NumPy, SciPy, Shapely and Matplotlib to audit
the checked projects directly. G-code is extracted to temporary files. The
`baseline/` projects are deliberately defective regression fixtures, not prints
to use. `package.py` builds the public ZIP and guide without local account paths.

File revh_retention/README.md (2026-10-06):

# Rev H-R1 removable retainers

Four add-on parts for the preserved Precision 5560 Rev H geometry: two handed
side bars and two handed keepers. The existing fourteen Rev H parts, including
the already printed arms, are unchanged. The intended change is removable
withdrawal retention at the duct-to-arm and upper-rail-to-arm joints.

[Illustrated installation guide and interactive model](../docs/revh-retainers.html) ·
[Native FreeCAD model](Precision_5560_RevH_Removable_Retainers.FCStd) ·
[Print files](print/) · [CAD verification](validation.json)

Print `01_right_arm_fit_test.3mf` first. It contains a shortened right bar with
both window keys and the lower keeper. Test it directly on the printed right
arm. The coupon is not a substitute for the complete installed bar.

After the coupon passes, print `00_four_retainer_parts.3mf` once. It contains
15/16 left/right bars and 17/18 left/right keepers. The individual STEP, STL
and standard 3MF files are alternatives for replacements; do not also print
them. Keep the supplied orientations and 100% scale. Standard 3MF files contain
geometry, without slicer settings. Separate Orca review archives contain the
reviewed settings and G-code; re-slice for the actual ASA spool.

Orca starting process: P1S, 0.4 mm nozzle, 0.20 mm layer height, 6 walls,
6 top/bottom layers, 100% rectilinear infill of the deliberately open CAD,
Arachne walls, 8 mm outer brim, supports off. The bars print with their flat
outboard faces down. Keepers print with their catch feet down and split tips up.

## How the retention works

- The lower rounded key fits the existing triangular gusset opening. Its tab
  overlaps the front of the duct saddle with a nominal 0.30 mm gap.
- The second key enters the existing rounded guide opening above it. This
  limits rotation of the bar in its plane.
- The external heel extends below the lower key. It bears against the existing
  arm if the top of the bar tilts outward. The widened upper stop overlaps the
  upper rail's front lip.
- The square keeper stem keeps its eccentric catch foot oriented toward the
  arm. The foot overlaps the inner gusset face, preventing sideways loss. The
  split crown prevents ordinary downward withdrawal of the keeper.
- Removing one bar releases both the duct and rail on that side. Support both
  during service and remove the laptop before releasing retainers.

The stem is 3.0 mm square in a 3.6 mm socket. The 3.8 mm split crown needs
nominal 0.10 mm deflection per finger to pass. There is 0.60 mm total keeper
endplay and 0.50 mm catch-foot clearance to the inner arm. These are nominal
CAD dimensions; printer shrinkage, burrs and first-layer expansion need a test.

The existing shoulders and keys still carry the intended assembly loads.
These bars provide withdrawal retention, with running clearance; they are not
a clamping preload. They require no drilling of the arms, extra metal parts or
adhesive at the two retained joints. Original fan caps, trays and pins retain
their Rev H arrangement.

## Native construction and reproduction

`build.py` makes a Save As copy of `freecad/Precision_5560_Native.FCStd` and
adds constrained Sketcher profiles with stock Part extrusions, fillets,
booleans and mirrors. Native source features for the original fourteen parts
are preserved. The copy replaces the older assembly's fourteen invalid saved
joint references with fixed installed App::Links in an App::Part. The original
Rev H document is untouched. The completed file needs no custom geometry proxy.

This is a fixed-size add-on for the preserved Rev H snapshot. Editing the old
Rev H spreadsheet does not automatically resize or reposition the retainers.
Recheck any geometry edit, including the matching socket and keeper dimensions.

Run the builder in FreeCAD's GUI, then run `validate_export.py` with FreeCAD's
bundled Python against the saved file. The validator opens a separate snapshot,
forces native recomputation, compares all fourteen originals and frozen arms,
checks the new solids, sampled service/stop motions and combined outward-tilt
poses, and exports print-oriented STEP/STL/3MF. `render.py` captures actual native
views in a separate unsaved presentation document.

Slice the two combined 3MF plates with `minimalist/slice_models.py` and screen
both resulting G-codes with `minimalist/gcode_audit.py`. Then run `package.py` to
build the offline guide and download. The release report binds the native file,
exports, sliced input and audited G-code by SHA-256.

## Remaining physical checks

The coupon must seat by hand, latch fully, resist sideways removal while
latched, and release repeatedly without damage. Test the full retained assembly
while supported before loading it. Check bar movement, keeper seating and
warm ASA deformation. CAD does not establish a load rating, actual bar stiffness,
retention force, fatigue life, layer adhesion or creep resistance.

The new parts sit outside the existing arms. The original duct airways, fan
parts and laptop geometry are unchanged. This add-on has no new airflow result;
the existing CFD commissioning limitations remain in effect.

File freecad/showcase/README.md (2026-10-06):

# Public project showcase

URL: https://thereprocase.github.io/dell-5560-wall-mount/

Local server: Python serve.py, listening only on 127.0.0.1:8876.
Tailscale Serve adds /mount-showcase on the existing HTTPS service.
The pre-existing root route and TCP routes are retained. No Funnel enabled.
Only ../../docs/ is served; dependencies, source scripts and server logs stay outside it.
Three.js assets are local, with its MIT license in ../../docs/vendor/THREE-LICENSE.txt.

Features: real STL before/after geometry for all 14 parts, matched camera,
exploded view, family focus, arm ghosting, technical edges, annotated original
screenshots, measured-fit reports and six updated oriented STL downloads.
Before meshes come from the original Revision F parts/. After meshes come from
FinishValidation.FCStd. Public downloads are print_refinements_oriented STLs.

Run serve.py with Python to restart the local server after a reboot.
The Tailscale --bg route persists separately from the Python process.
Run node check.cjs URL for a desktop/mobile browser check using installed Edge.
Do not use tailscale serve reset or disable the whole 443 listener: other services
are present. Manage this route specifically using --set-path=/mount-showcase.

The page summarizes CAD evidence. It does not claim physical printer/retention
validation or that the current ribbon fully matches the extracted Fusion content.

Canonical public files now live in ../../docs, served by both GitHub Pages and serve.py. Regenerate web meshes with export_scene.py after validating the native model. CFD gallery is a baseline study, not Revision G validation.

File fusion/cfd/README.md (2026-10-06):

# Airflow setup: sealed mount benchmark

**Benchmark prepared, not meshed or solved.** OpenCFD v2412 is installed and passed an isolated 400-cell official cavity mesh/solver smoke test. Benchmark dictionaries parse, but its surface reports two self-intersections; benchmark meshing is withheld pending repair. See [verification evidence](verification/README.md). These scripts install nothing. This is an isothermal benchmark of prescribed delivered flow through both ducts and a rear plenum with **artificially sealed sides** and a nominal 12 mm outlet gap. It excludes ambient leakage, upstream fan/guard losses, true fan operating-point prediction, laptop internals and CPU temperature.

The confirmed fan assumption is the standard original-generation **Noctua NF-A12x25 PWM**. Its official endpoints are 2000 RPM, 102.1 m3/h (60.09 CFM) free flow and 2.34 mm H2O maximum static pressure. Those endpoints do not occur simultaneously. The actual installed RPM and numerical pressure-flow curve remain unknown. `fan_curve_template.csv` intentionally contains only headers; no interpolated manufacturer curve is fabricated. See [Noctua specifications](https://www.noctua.at/en/products/nf-a12x25-pwm/specifications) and its [official P/Q discussion](https://www.noctua.at/en/expertise/tech/nf-a12x25-performance-comparison-to-nf-f12-and-nf-s12a).

## Files and provenance

- `prepare_geometry.py` and `geometry/geometry_manifest.json` document geometry generation and simplifications. The seven named patch STLs are in **metres** and jointly form the closed fluid boundary; do not scale them by 0.001 again. The individual patches are intentionally open surfaces.
- `inputs.json` records scope, fan identification, assumed air/turbulence properties, the 20/35/50 CFM **per-fan** sweep, and coarse/medium/fine mesh settings.
- `generate_case.py` combines named STL regions and writes a standalone OpenCFD v2412 case, including field boundary conditions, mesh/numerical dictionaries, monitors, an explicit `Allrun`, and `case_manifest.json` containing hashes and geometry checks.
- `cases/OpenCFD_v2412/` contains the current generated cases. The earlier `cases/q*_coarse` artifacts are retained historical v2312 preparation, with their original version guards/manifests; do not use them with the new environment. Generation alone is not OpenFOAM validation.

The generator refuses missing/empty patches, inconsistent triangle-edge closure/winding, reversed overall orientation, geometry outside the background box, and existing output directories. It checks the region seed against the bounding box; the geometry-prep manifest and later mesher must establish actual interior placement. OpenFOAM surface/intersection and mesh checks remain required.

The `q20_coarse`, `q35_coarse`, and `q50_coarse` v2412 cases were generated locally from the 6104-triangle, seven-patch surface. Python syntax, closed-edge/winding checks, unit conversions and installed OpenFOAM dictionary parsing passed. There are no benchmark `polyMesh` or solver logs. **Surface self-intersections remain unresolved; benchmark mesh generation and convergence are unverified.**

## Generate cases without running CFD

From the repository root, with ordinary Python 3.10+:

```powershell
python fusion/cfd/generate_case.py --cfm 20 --level coarse
python fusion/cfd/generate_case.py --cfm 35 --level coarse
python fusion/cfd/generate_case.py --cfm 50 --level coarse
```

The first case uses `0.009438948864 m3/s` at **each** fan. The others use `0.016518160512` and `0.023597372160 m3/s` per fan. These are conditional flow demands, not measured/predicted delivered flows. For mesh sensitivity, generate the same flow with `--level medium` and `--level fine`. `--geometry`, `--inputs`, and `--output` permit explicit alternate inputs and a **new** output directory. Existing cases are never erased or overwritten.

Coarse targets roughly 1 mm surface cells, medium 0.75 mm, and fine 0.5 mm with 0.25 mm outlet-region refinement. Cell limits are approximately 1.5/3/6 million; these are configuration limits, not measured cell counts or memory predictions. The coarse mesh is principally a setup check. Narrow passages, 2 mm details, boundary layers and achieved wall resolution need actual inspection and refinement evidence.

## OpenFOAM automation reference

The generated case is pinned to **OpenCFD OpenFOAM v2412**, package `2412.260127-1`, `simpleFoam`, incompressible steady RANS and `kOmegaSST`. It is not an OpenFOAM Foundation case and not a BARAM project. The [OpenCFD simpleFoam documentation](https://doc.openfoam.com/2312/tools/processing/solvers/rtm/incompressible/simpleFoam/) specifies kinematic pressure and velocity/turbulence fields; the generator uses `constant/turbulenceProperties`. The [v2412 boundary-condition API](https://api.openfoam.com/2412/pageBoundaryConditions.html) confirms the pressure/velocity combinations below. Installed v2412 dictionary parsing and comparison against its motorBike SST tutorial are complete; this still does not establish successful benchmark meshing or solving.

Boundary conditions:

| Patch | U | p | Other fields |
| --- | --- | --- | --- |
| `fan_left`, `fan_right` | `flowRateInletVelocity`, positive incoming volume flow | `zeroGradient` | Prescribed k/omega from assumed 5% intensity and 8 mm length scale |
| `outlet` | `pressureInletOutletVelocity` | Zero-gauge `fixedValue` | Backflow-safe `inletOutlet` k/omega with documented assumed values |
| Four wall groups | `noSlip` | `zeroGradient` | `kqRWallFunction`, `omegaWallFunction`, `nutkWallFunction` |

OpenCFD documents [flow-rate inlet syntax](https://doc.openfoam.com/2306/tools/processing/boundary-conditions/rtm/derived/inlet/flowRateInletVelocity/); the referenced page is v2306, while the solver/model and wall-function example were checked against v2312. The [v2312 rotating-fan tutorial](https://doc.openfoam.com/2312/examples/tutorials/incompressible/pimpleFoam/ami-rotating-fan/) confirms these wall-function families and a pressure/backflow outlet. The [SST documentation](https://doc.openfoam.com/2312/tools/processing/models/turbulence/ras/linear-evm/rtm/kOmegaSST/) supplies the k/omega initialization formulas. No rotating fan is modeled in this benchmark.

Only after choosing to run and sourcing the OpenCFD v2412 environment, the explicit future command from a generated case is:

```sh
sh Allrun
```

**This command has not been executed.** `Allrun` refuses another environment/executable version and refuses to reuse an existing mesh/run. It checks the combined surface, generates a background mesh, runs `snappyHexMesh`, checks mesh quality and the seven nonempty named boundaries, confirms one connected region, then invokes `simpleFoam`. It creates logs without cleanup scripts. A stopped or failed case should be preserved; generate a new case to retry.

Six [surfaceFieldValue monitors](https://doc.openfoam.com/2312/tools/post-processing/function-objects/field/surfaceFieldValue/) record per-patch volume flux and mean kinematic static pressure at the two fans and outlet; `yPlus` reports wall resolution. Multiply a kinematic-pressure difference by the assumed density (1.2 kg/m3) for Pa. These static-pressure monitors alone are not a total-pressure-loss calculation when section velocities differ. Check signed flux balance, solver residuals, stable monitors, separation/backflow and mesh sensitivity before drawing conclusions. A converged fixed-flow solution does not establish that the fan can deliver that flow.

## BARAM standalone GUI path

BARAM is a separate GUI workflow recommended for interactive setup. Current [BARAM documentation](https://baramcfd.org/en/manual-en/manual-baramflow-en/introduction-en/) identifies BARAM v26's solver stack as NextFOAM v25, derived from OpenFOAM v2412. The selected OpenCFD release shares that upstream release family, but **OpenCFD v2412 is not the NextFOAM binary or a native BARAM project**. Carry over geometry, patch roles and numerical input values, then create a native BARAM project; dictionary/project compatibility is unverified. No installation is performed by these scripts.

1. In BaramMesh, import the seven `geometry/*.stl` patches, or the generated `constant/triSurface/fluid_boundary.stl` containing named SOLID regions. Check that all seven names and metre dimensions survive import. [BaramMesh geometry documentation](https://baramcfd.org/en/manual-en/manual-barammesh-en/geometry-barammesh-en/) explains the separate display of STL SOLID regions.
2. Define one fluid region using seed `(0, 0.02, 0.10)` m and verify that it lies inside the intended connected plenum. Follow BaramMesh's background-grid, castellation, snapping and boundary-layer steps, using `inputs.json` refinement settings as starting assumptions. [Region selection](https://baramcfd.org/en/manual-en/manual-barammesh-en/region-barammesh-en/) uses an interior point to choose the enclosed volume.
3. Export the mesh as a BaramFlow project or load its OpenFOAM mesh into a new BaramFlow case. The [BaramMesh workflow](https://baramcfd.org/en/manual-en/manual-barammesh-en/introduction-barammesh-en/) provides mesh export; [BaramFlow mesh import](https://baramcfd.org/en/manual-en/manual-baramflow-en/installation-en/) accepts a `constant` or `polyMesh` directory. This is mesh transfer, not an assertion that the generated OpenCFD solver dictionaries import correctly.
4. Recreate the steady incompressible, energy-disabled flow study in BaramFlow. Assign the same per-fan volume flows, zero-gauge pressure outlet and no-slip wall groups, keeping `assumed_side_seals` visibly labeled as artificial. Set room-air and turbulence assumptions explicitly. If the GUI requests mass flow instead, convert using the chosen density and record the conversion.
5. Save the BARAM project before any mesh/solver run. No fan-curve or thermal inputs should be inferred from the fan's endpoint ratings. Use BARAM's own supported solver settings and the same conservation/mesh-sensitivity checks.

For physical interpretation and the later ambient/thermal path, see [CFD preparation research](../CFD_PREP_RESEARCH.md). The production Fusion laptop and wall helper bodies supply visual/geometry references; the sealed fluid benchmark remains a separate simplified analysis model.

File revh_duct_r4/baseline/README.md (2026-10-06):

Historical D3/T3/R2/B1 source and regression fixtures.

These fixtures reproduce the blocked socket defect. Do not print the old D3
projects here. Use the D4 projects one directory above. The baseline native
assembly is the exact model against which the D4-only geometry change was
checked; it includes fit revisions newer than the earlier public C1 snapshot.

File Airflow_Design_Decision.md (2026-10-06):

# Revision F airflow decision

Use a shrouded 40 mm rear gap, 45° upward/wallward fans, a gradual lower turn,
and a 12 mm nominal top slot. Start the contraction above the estimated intake
at Z=198 mm, reach the throat at 226 mm and continue to 232 mm. Alternative
8/16 mm rails preserve the same mounting interfaces and printable wall slopes.

Dell's inside-cover image reveals two approximately 70 × 40 mm intake windows
near X=±111 mm and Z≈151–191 mm. The exterior grille spans a larger width but
its covered center is not fully open. The reconstruction has ±4 mm location
uncertainty. The conservative intake upper edge remains below the contraction.

CFD_Design_Report.md records an actual 2D OpenFOAM RANS comparison. A smaller
slot raises modeled intake static pressure but reduces bypass flow. The study
does not establish actual flow through the machine, outlet entrainment distance
or cooling performance. It omits side leakage and does not resolve the laptop's
internal resistance/blowers. Use pressure and temperature measurements with
the selected fans to calibrate the next study.

The cheek lips remain noncontact and stop behind the laptop's side ports. They
reduce the gross open sides, but the mount is not an airtight duct. Actual
clearance, wall flatness and joint leakage remain physical checks.

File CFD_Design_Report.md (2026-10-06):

# Plenum and outlet CFD — Revision F

**Keep a 12 mm nominal slot as the starting configuration.** The 8 mm slot
retains more intake pressure, while 16 mm passes more bypass flow. At fixed
inlet total pressure, narrowing the slot does not automatically create the
fastest outlet jet. These are comparative model results, not predictions for
the user's uncharacterized fans or laptop.

The gentler lower turn improves mean intake pressure by only
0.11 Pa
on the common mesh. That small difference does not justify calling it an
optimized shape. Retain its printable transition and use the larger slot-width
tradeoff to guide the first prototype. The contraction starts at Z=198 mm,
after the estimated intake band, reaches its throat at Z=226 mm, and guides
the outlet upward to Z=232 mm. All three variants keep the skin within 45° for
lip-down printing.

## Model and boundary conditions

OpenFOAM v1912 (Ubuntu package 1912.200626-2build3), simpleFoam, incompressible
steady RANS, k-omega SST. Density 1.2 kg/m³; kinematic viscosity 1.5e-5 m²/s.
Two-dimensional block mesh with a 1 mm empty span. No-slip smooth walls,
20 Pa inlet total pressure (10 Pa sensitivity), zero-gauge static pressure at
the slot exit, prescribed 0.4 m/s suction through the intake band (0.8 m/s
sensitivity). Inlet k=0.015 m²/s² and omega=50 s⁻¹. Wall functions use the
solver's standard SST setup. This is not a transition-resolving calculation.

The inlet line slopes 45° and has wallward/upward normal. The mesh idealizes
the center section of a fan band with sealed cheeks; it omits the grille,
fan hub/swirl, structural ribs, three-dimensional spreading and leakage at
noncontact joints. The CAD skins sit around a similar ruled flow path;
2 mm wall thickness and small transitions are simplified in the CFD geometry.
The CFD intake patch is Z=156–192 mm, a simplified band within the image-derived
layout. The rear foot projects 2 mm at Z≈218–222 mm; its true height is unmeasured.

Laptop intake flow is a prescribed demand, not a pressure-coupled internal
resistance or laptop-blower model. The supplied fan pressure is an assumption,
not a measured operating point or an adopted fan curve. Do not multiply a
representative slice across the entire laptop to claim total CFM.

## Results

Pressure is gauge pressure relative to the slot outlet. Mean and minimum
values sample the intake patch; velocity is area-mean at the slot exit.

| Case | Mean intake Pa | Minimum intake Pa | Exit m/s | Flow imbalance % | Strict residual target met |
|---|---:|---:|---:|---:|---|
| curved_12 | 17.67 | 15.80 | 4.42 | 0.00000 | no |
| curved_12_fine | 17.72 | 15.62 | 4.29 | 0.00000 | no |
| curved_12_high_draw | 16.44 | 11.51 | 4.63 | 0.00000 | yes |
| curved_12_low_pressure | 8.53 | 7.01 | 3.16 | 0.00000 | no |
| curved_12_medium | 17.68 | 15.65 | 4.34 | 0.00004 | no |
| curved_16 | 15.43 | 12.87 | 5.16 | 0.00000 | yes |
| curved_8 | 18.80 | 17.42 | 4.01 | 0.00000 | yes |
| straight_12 | 17.56 | 15.75 | 4.39 | 0.00000 | yes |

## Numerical checks

All eight block meshes pass checkMesh; positive volumes and acceptable
nonorthogonality/skewness. Pressure-velocity coupling uses SIMPLE with one
nonorthogonal correction and under-relaxation. Momentum uses bounded
linear-upwind convection; turbulence uses upwind convection.

The nominal cell-size sequence is 2.0, 1.3, 0.85 mm. Coarse-to-fine mean intake
pressure changes by0.31%;
exit velocity changes by2.95%.
Medium-to-fine pressure changes by0.24%.
Mass imbalance remains below 0.001%. Four cases do not satisfy the strict
1e-6 residual stop before 1600 iterations. Their final monitored mean pressures
change by less than 0.01% between saved states. Treat them as stabilized
screening results, with unresolved residual/flow unsteadiness, not fully
converged high-accuracy solutions. Raw logs preserve this limitation.

## What this does not establish

No conjugate heat transfer, laptop temperature, exhaust entrainment distance,
room recirculation, noise, buoyancy or fan-off cooling prediction. Side leakage
can lower real plenum pressure. The unheated domain ends at the hinge height;
it does not model how far the hot plume travels. No topology or generative
optimization solve is represented by this study.

A useful next calibration is the exact 120 mm fan model and RPM/PWM setting,
plus intake static pressure and laptop temperature at a repeatable workload.
Those allow a fan-curve/internal-resistance model and a meaningful 3D study.

## Reproduce and inspect

Run unpack_cfd_evidence.py to inspect the recorded fields and logs. To generate new results, run run_cfd_sweep.py with OpenFOAM available, then analyze_cfd.py and render_cfd.py.
Each cfd/ case contains its mesh dictionaries, initial conditions, parameters,
checkMesh and solver logs, and the final field state. VTK output for the
comparison cases opens in ParaView. The included foam_environment.md explains
the runtime setup and the -noFunctionObjects option used to avoid an old
function-object hashing incompatibility; postprocessing reads written fields.

Sources: [OpenFOAM SST model](https://doc.openfoam.com/2306/tools/processing/models/turbulence/ras/linear-evm/rtm/kOmegaSST/),
[OpenFOAM boundary conditions](https://www.openfoam.com/documentation/user-guide/a-reference/a.4-standard-boundary-conditions),
[Dell service manual](https://dl.dell.com/content/manual44781765-precision-5560-service-manual.pdf?language=en-us).

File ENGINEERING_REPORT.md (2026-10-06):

# Precision 5560 server wall mount — engineering report

Revision F · 7 September 2026 · prototype design

**The mount aims to support the laptop's own cooling system.** Two inclined fans feed a shrouded rear gap; an upper restriction retains modeled intake pressure and directs bypass air toward the hinge exhaust. The laptop lifts out for access. Geometry checks, structural screening and comparative CFD are complete. Printing, joint retention and cooling performance need physical validation.

Installed and empty assembly, rendered from the CAD

## 1. Design basis

The mount holds a closed Dell Precision 5560 used as a web server. The hinge faces up, placing the exhaust at the upper edge. The underside faces the fan-fed wall gap. The laptop lifts out for keyboard access.

| Parameter | Revision F |
|---|---|
| Laptop reference envelope | 344.4 × 230.3 × 20 mm |
| Bare retention slot / front tine height | 26 / 94 mm |
| Nominal underside-to-wall gap | 40 mm |
| Fans | Two 120 mm frames, 25–27 mm thick |
| Fan airflow direction | Wallward and upward at 45° |
| Wall attachment | Four Ø7 mm holes; axes normal to wall |
| Hole centers | X = ±162 mm; Z = −36 and +174 mm |
| Tool clearance | Ø16 mm room-side corridors |
| Default outlet / alternatives | 12 mm / 8 and 16 mm |
| Printed assembly | 14 pieces, including four identical split pins |
| Laptop removal | 105 mm lift, then forward; allow 110 mm overhead |

Coordinates are X across the laptop, Y outward from the wall and Z upward in the exported assembly. Inspect the installed-reference STEP when positioning the mount. Physical measurements should resolve the stated profile uncertainty before permanent assembly.

## 2. Reference geometry and vent alignment

Scaled Dell images and estimated profile

Dell's published width and depth set the image scales. Selected points from the side view define the estimated silhouette. The inside-base-cover image reveals a covered center behind the broad exterior grille, leaving two inferred intake regions.

We observed the following:

- The scaled inside-cover image places two approximately 70 × 40 mm intake regions near X = ±111 mm and Z ≈151–191 mm.
- The image-derived intake location carries an estimated ±4 mm uncertainty.
- The reconstructed side profile carries an estimated ±2 mm uncertainty. The assembly retains a 20 mm thickness envelope.
- The model assumes a 2 mm rear-foot projection. No dimensioned factory cross-section or physical measurement establishes that value.

The contraction begins at Z = 198 mm, above the estimated intake band. It reaches its throat at Z = 226 mm and exits at Z = 232 mm, close to the hinge edge at Z = 232.3 mm. These locations retain a nominal gap between the intake and contraction; they require verification on the actual machine.

Intake band, contraction and outlet alignment

The [profile JSON](profile_reconstruction.json) preserves pixel picks, scale factors, source hashes and uncertainty. The [reference STEP](REFERENCE_Estimated_Laptop_Profile.step) is an inferred silhouette, not manufacturer geometry. Source links appear in [SOURCES.md](SOURCES.md).

## 3. Airflow design and numerical evidence

The lower fans feed the rear plenum. Cheeks limit side leakage, and the upper restriction sits downstream of the intake band. The aim is to retain static pressure at the laptop intake while directing bypass air upward. The laptop remains vertical, with noncontact clearances for removal.

Restricting the outlet can increase upstream pressure while reducing total flow. At limited supply pressure, a narrower opening need not produce a faster jet. The laptop's blowers and internal resistance also govern intake flow.

OpenFOAM field results and common-mesh comparison

Eight OpenFOAM v1912 `simpleFoam` runs use steady incompressible RANS with k–omega SST. The domain is a representative sealed 2D fan-band section with a 1 mm empty extrusion. Nominal inlet total pressure is 20 Pa; the outlet uses zero-gauge static pressure. The intake patch has a prescribed 0.4 m/s demand. Sensitivity cases use 10 Pa supply and 0.8 m/s intake demand.

| Common-mesh case | Mean intake pressure, Pa | Mean slot exit speed, m/s |
|---|---:|---:|
| Curved lower turn, 8 mm slot | 18.80 | 4.01 |
| Curved lower turn, 12 mm slot | 17.67 | 4.42 |
| Curved lower turn, 16 mm slot | 15.43 | 5.16 |
| Straight lower turn, 12 mm slot | 17.56 | 4.39 |

The 12 mm slot remains the first prototype configuration. The 8 mm variant retains more modeled intake pressure but passes less bypass flow and leaves less clearance. The 16 mm variant passes more flow at lower intake pressure. The gentler turn changes mean intake pressure by only about 0.11 Pa on the common mesh; that result does not establish a meaningfully optimized bend.

All eight meshes passed `checkMesh`, and reported flow imbalance stays below 0.001%. Coarse-to-fine refinement changes mean intake pressure by about 0.3% and exit speed by about 2.9%. Four cases miss the strict residual target at 1,600 iterations even though the final mean-pressure monitors change by less than 0.01% between saved states. The [CFD report](CFD_Design_Report.md) identifies every case and preserves the boundary conditions and convergence limits.

**Model limits:** intake flow and fan supply pressure are prescribed. The study omits real fan curves, 3D leakage, fan hubs and swirl, detailed grilles and ribs, internal laptop resistance, heat transfer and the room plume. It compares the proposed slot geometries. Actual CFM, cooling improvement and exhaust carry distance require measurements.

## 4. Material reduction and structure

Hollow box sections, thin duct skins, framed trays and pocketed caps reduce material. Saddle roots, bearing shoulders and wall holes retain the load-carrying sections. Section calculations guided these edits; no generative or topology solver was run.

| Checkpoint | Solid CAD volume, cm³ | Interpretation |
|---|---:|---|
| Revision D | 1,810.4 | Earlier reference |
| Revision E | 1,164.2 | Lightweight baseline |
| Revision F | 1,177.3 | Shrouded, inclined, CA/pin assembly |

Revision F reduces solid volume by 35.0% relative to D. The latest containment and assembly changes add 13.1 cm³ relative to E, approximately 14 g at the assumed ASA density of 1.07 g/cm³. These comparisons use equal fill policy and exclude brims and process allowances; they are not slicer filament estimates.

The structural screen uses a 2.5 kg laptop, a 6 kg complete installation, a 1 kg allowance per fan module, 3g acceleration and a 50 N outward hinge pull. It adopts 5 MPa normal/bearing and 2 MPa shear limits, a 1,000 MPa effective modulus, a 1.5 local stress multiplier and a 10% section-property allowance. These are chosen screening values, not measured warm printed ASA properties.

Net section properties come from the actual cradle geometry at 0.5 mm stations and include voids and unsymmetric bending. The rear-section calculation ignores the additional cheek stiffness. The minimum ratio of assumed stress limit to calculated stress is **1.19**, governed by the combined rear-rail case. It does not establish a tested assembly safety factor. The full [strength report](Strength_and_Installation_Check.md) lists each calculation and load demand.

The calculations do not resolve adhesive peel and pullout, pin retention, anchor capacity in the actual wall, torsion, local buckling, fatigue, impact or long-term thermal creep. In particular, each duct has a calculated 47.8 N outward joint demand and each pin a 7.4 N retention demand that still require physical qualification.

## 5. FDM design and assembly

Print orientations by part family

The cradles print on their outer sides to place the main bracket load path within the layer planes. The ducts print from their inclined fan-inlet faces, and the outlet rails print lip down. Sloped joint roofs and skins avoid broad unsupported ceilings. Deliberate short bridges close hollow sections without filling them with support.

All individual parts, including an 8 mm brim, fit the P1S's 256 mm bed while avoiding the stock front-left cutter exclusion. The 0.20 mm geometric layer audit finds no floating starts. The largest intentional bridge spans 18 mm in the rear spine; its maximum sampled unsupported reach is 8.8 mm. Dovetail roofs span 6.6 mm. These checks evaluate geometric support, not extrusion quality.

The Bambu Studio runtime could not execute in the design environment. The files have therefore not passed an actual Bambu toolpath preview or print trial. The [ASA guide](P1S_ASA_Print_Guide.md) provides starting process settings and highlights the required preview.

Sections through the actual printable geometry

Fixed ducts and rails use keyed lap joints. Their shoulders carry vertical load; CA resists withdrawal. The fan trays slide into dovetails, and two split pins retain each fan cap. The assembly needs no M3/M4 screws, nuts or heat-set inserts. All four wall bolts remain perpendicular to the wall with clear tool access.

The nominal sliding allowance is 0.30 mm horizontally per side, with 0.30 mm crown and 0.20 mm root clearance. The keyed CA pockets use 0.30 mm nominal offsets plus roof relief. Split pins use a 4.0 mm shaft, 4.1 mm socket and 4.2 mm retaining crown. [TOLERANCES.md](TOLERANCES.md) distinguishes diametral, radial and coordinate allowances; no global shrink compensation is assumed.

Exploded fixed and removable joints

## 6. Verification record and next decisions

| Evidence completed | Practical limit |
|---|---|
| 14 valid solids; STEP reimport | Solid validity does not establish manufacturability |
| Fit, service motion and driver-path checks | Laptop envelope and image-derived profile need physical confirmation |
| No unintended part overlap | Four pin crowns intentionally interfere by 0.05 mm radially |
| Watertight oriented meshes and bed/brim check | Slicer-generated extras and extrusion paths remain to be inspected |
| Geometric layer support audit | Bridges and surface quality need printing |
| Net-section strength screen | Bonds, anchors, retention and warm creep remain unqualified |
| Eight CFD cases with raw logs and fields | Comparative 2D study with prescribed laptop demand |

The next prototype should proceed in this order:

1. Measure the actual closed laptop, feet and intake boundaries. Confirm noncontact cheek and outlet clearance before choosing the rail pair.
2. Print the joint and pin coupons in the intended ASA process. Check sliding fit, CA retention and repeated pin use. Check long tray engagement for warping.
3. Preview the full parts in Bambu Studio, including bridge direction, extrusion continuity and brim placement. Print and inspect the structural brackets before loading the laptop.
4. Qualify the assembled joints and wall attachment against the stated demands, then assess deformation and creep at the measured operating temperature.
5. Fit the selected fans, measure plenum pressure near both intake regions, and compare repeatable workload temperatures and noise with fans off/on and alternative outlet rails. Record ambient temperature, fan speed and laptop workload.
6. Use the measured fan curve, pressure, leakage and laptop response to decide whether a coupled 3D or thermal CFD model would change the design. Revisit material reduction only after the physical joint and creep behavior are established.

## 7. Reproducibility

[PROCESS.md](PROCESS.md) records the decisions and regeneration commands. The `cfd/` directory contains case definitions and archived fields and logs. Scripts use repository-relative paths. [SOURCES.md](SOURCES.md) links the manufacturer references, and [DIALOGUE.md](DIALOGUE.md) records the available project prompts.

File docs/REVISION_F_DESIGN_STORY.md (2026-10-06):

# A wall mount optimized for airflow synergy

A Dell Precision 5560 server mount designed to work with the laptop's cooling system. Two 120 mm fans feed a shrouded gap behind the underside. An upper restriction aims to retain pressure at the intake vents and direct bypass air upward, past the hinge exhaust. The laptop lifts out for keyboard access.

The assembly uses side-printed ASA brackets, 45° fan modules, keyed CA joints and removable fan trays. Four wall bolts are the only metal mounting fasteners.

Revision F installed and empty, rendered from CAD

**Revision F — prototype design.** CAD checks, structural screening and eight CFD cases are complete. Printing, joint strength and cooling performance still need physical validation.

[STEP assembly](../Precision_5560_Wall_Mount.step) · [Print files](../print_ready/) · [Assembly guide](../P1S_ASA_Print_Guide.md) · [Engineering report](../ENGINEERING_REPORT.md) · [Reproduction steps](../PROCESS.md)

## 1. Define fit and access

> “The hinge will go up so that the hot air escapes up and the fans can go on the bottom…”

The laptop sits vertically, underside toward the wall, with a 40 mm rear gap. A 344.4 × 230.3 × 20 mm envelope controls fit. The 26 mm bare slot allows for contact pads.

> “…make the tines on the front a little bit taller…”

The front tines are 94 mm tall. Four Ø7 mm wall holes face the room through clear Ø16 mm tool paths. We checked bolt access and laptop removal with the assembly in place. The laptop needs a 105 mm lift before moving forward; allow 110 mm overhead.

## 2. Support the laptop's intake

> “…doesn't have to seal, just has to be high pressure at vent high velocity beyond.”

The airflow goal became a plenum with a controlled outlet. Side cheeks limit leakage. A separate upper rail contracts the gap above the intake band, keeping the laptop vertical and the outlet width interchangeable.

Restricting the outlet can raise upstream pressure while reducing flow. The useful question was how much pressure each slot retained at the intake, and what exit velocity remained.

## 3. Locate the active vents

> “…download and scale images and cross sections of the machine to estimate its profile geometry?”

We scaled Dell side views and an inside-base-cover image against the published width and depth. The inside view revealed a covered center behind the broad exterior grille, leaving two estimated 70 × 40 mm intake regions near X = ±111 mm.

Scaled Dell references and estimated profile

The estimated intake band ends near Z = 191 mm, with ±4 mm location uncertainty. The contraction starts at 198 mm, reaches its throat at 226 mm and exits at 232 mm, near the hinge. No dimensioned factory section was found; the reconstructed profile has an estimated ±2 mm uncertainty. Check the actual machine before assembly.

## 4. Design for the print orientation

> “I would like to print the brackets on their side for strength, and not on their back.”

> “Also bridges are just fine, they're usually printable. Unsupported overhangs are bad.”

The brackets print on their outer sides. Ducts print inlet down; outlet rails print lip down. Sloped roofs support the next layer, while short bridges close box sections and dovetail grooves.

Supplied print orientations

The 0.20 mm layer audit found no floating starts. The longest intentional bridge spans 18 mm. Each part and its 8 mm brim fits the P1S bed and avoids the cutter exclusion. Bambu Studio could not run in the environment, so toolpaths and ASA bridge quality remain to be checked.

## 5. Reduce material along the load path

> “I feel like we could get really creative and save a ton of plastic here.”

We hollowed the brackets, thinned the duct skins and pocketed the trays and caps. Material remains at bearing shoulders, bracket roots and wall holes. This used explicit geometry and section calculations; no topology or generative solver was run.

We extracted net section properties every 0.5 mm, including voids and unsymmetric bending. The structural screen uses a 2.5 kg laptop, 6 kg installation, 3g acceleration and a 50 N outward hinge pull. The minimum ratio of assumed stress limit to calculated stress is 1.19. This is a screening result; bonds, anchors and warm ASA creep remain unqualified.

Revision F uses **1,177.3 cm³ of solid CAD, 35.0% less than Revision D** at equal fill policy. The latest containment and assembly changes add 13.1 cm³ to the lightweight Revision E.

## 6. Keep service parts removable

> “Can we also make it tool free / ca glue assembly, except for the four wall bolts?”

Keyed lap joints connect the fixed ducts and outlet rails. Their shoulders carry vertical load; CA resists withdrawal. Fan trays slide in dry, and two split pins retain each cap.

> “…have the fans angle down so they're blowing at a 45 to the gap instead of straight in?”

The fan intakes face down and outward. Air flows upward and wallward at 45°. Cheeks contain the rear flow while leaving side ports accessible.

Fixed joints and removable fan assemblies

The screened loads require 47.8 N of outward retention per duct and 7.4 N per pin. Adhesive and pin tests must establish that retention before service.

## 7. Compare the outlet slots

> “And do some cfd to design the plenum and slot?”

Eight OpenFOAM v1912 cases compare slot width, lower-turn geometry, mesh size, supply pressure and intake demand. The model uses steady incompressible RANS with k–omega SST in a sealed 2D section.

Calculated pressure and velocity fields

At an assumed 20 Pa inlet total pressure and prescribed 0.4 m/s intake demand:

| Outlet | Mean intake pressure | Mean exit speed |
|---|---:|---:|
| 8 mm | 18.80 Pa | 4.01 m/s |
| **12 mm** | **17.67 Pa** | **4.42 m/s** |
| 16 mm | 15.43 Pa | 5.16 m/s |

The narrow slot retained more pressure; the wide slot produced a faster exit. We kept **12 mm** as the starting compromise. The curved lower turn improved intake pressure by only 0.11 Pa on the common mesh, giving little reason to refine the bend further before testing.

All meshes passed `checkMesh`. Flow imbalance stayed below 0.001%; mesh refinement changed mean intake pressure by about 0.3% and exit speed by 2.9%. Four cases missed the strict residual target despite stable mean-pressure monitors.

The model prescribes laptop intake flow and assumes fan pressure. It omits real fan curves, internal laptop resistance, side leakage, heat transfer and the room plume. The results compare slot behavior; actual cooling, total CFM and exhaust carry distance require measurements.

## 8. Specify the fits

> “what tolerances did you assume for slide to fit parts?”

The dovetail has 0.30 mm horizontal allowance per side, 0.30 mm crown clearance and 0.20 mm root clearance. Clearance normal to the sloping flank is smaller. Fixed-key pockets use 0.30 mm nominal offsets plus roof relief. Pins use a Ø4.0 mm shaft, Ø4.1 mm socket and Ø4.2 mm split crown.

No global ASA shrink correction is applied. Print the coupons, inspect elephant foot and adjust individual interfaces as needed. Full-length tray engagement also needs a warping check. See [TOLERANCES.md](../TOLERANCES.md).

## 9. Reproduce and test

The workflow followed the interfaces: establish fit, reconstruct the vents, build the solids, check loads and service motions, audit print support, then compare airflow variants. [DIALOGUE.md](../DIALOGUE.md) preserves the available prompts in order.

| Software | Use |
|---|---|
| Python 3.12; CadQuery 2.8.0 / Open CASCADE | Parametric solids, sections, STEP export and interference checks |
| NumPy; trimesh 5.1.0; Shapely 2.1.2; rtree; NetworkX | Mesh, layer support and connectivity checks |
| Pillow | CAD renders and reference-image annotations |
| Matplotlib; SciPy; VTK | CFD postprocessing and field plots |
| OpenFOAM v1912 | Meshing, mesh checks, flow solution and field export |
| Bambu Studio 2.8.2.61 profile sources | Starting P1S/ASA settings; slicing remains pending |
| Git / GitHub | Source, design files and analysis records |

[PROCESS.md](../PROCESS.md) gives the commands; [requirements.txt](../requirements.txt) records the Python dependencies. The [engineering report](../ENGINEERING_REPORT.md) covers dimensions, assumptions, loads and verification.

Next: measure the laptop, print the coupons, test joint retention and warm structural behavior, then measure intake pressure and workload temperatures with the selected fans and outlet rails. Use those results to decide whether a coupled 3D or thermal model would change the design.

**Printing:** follow the [P1S ASA guide](../P1S_ASA_Print_Guide.md), retain the supplied orientations and inspect the slice. Files are standard 3MF/STL models. Print the individual parts; reference STEP assemblies are for fit inspection.

**License:** [MIT](../LICENSE). Dell reference material is attributed separately in [SOURCES.md](../SOURCES.md). This project is independent of Dell and Bambu Lab.

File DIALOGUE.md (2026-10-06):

# Project dialogue: user prompts and design responses

These are the project prompts available in the working conversation, in order. Quoted text preserves the user's wording. Response notes summarize work and decisions; they are not verbatim assistant messages or a complete chat export. The README groups related decisions by engineering topic rather than pretending that each final feature appeared in the first iteration.

## 1. Initial brief

> Make a wall mount laptop holder to hold a Dell Precision 5560 in the closed position. I use it as a web server. The wall mount holder should have four fastener holes. I'll use plastic toggle bolts so they don't need to be at any particular spacing, but four for strength to hold it to the wall. It should have vent space between the laptop and the wall, and it should have room to mount a couple of 120 millimeter fans below the laptop to direct airflow up and past the laptop's cooling vents, and it should be easy to pull the laptop up and out. The hinge will go down— no, wait. The hinge will go up so that the hot air escapes up and the fans can go on the bottom, and it should be easy to pick the laptop out to use it temporarily if I need direct keyboard access to the server, but otherwise it should just stay out of the way and be nice and cool. And I need this as a ParaSolid or a STEP file.

**Response:** establish a hinge-up, lift-out cradle, wall gap, two lower fans and four wall fasteners. Deliver exact solid geometry as STEP.

## 2. Retention, finish and installation

> That looks amazing! Can you give it some aesthetic polish and make the tines on the front a little bit taller so the laptop is held more securely. Also give it a quick strength check and make sure that all of the fasteners are easy to install and oriented perpendicular to the wall

**Response:** retain taller front tines and polished edge treatment; check load paths and room-side tool access. The final wall fasteners remain perpendicular to the wall.

## 3. Pressure rather than incidental crossflow

> from a fluid mechanics perspective, should we tilt the laptop towards the wall to create a restriction (or make an additional part - a back rail) for the purpose of ensuring high pressure at the laptop's intake vent, and a high velocity exit above, so hot air is carried far away? This ensures that the 120mm fans create airflow THROUGH the laptop instead of accidentally creating a high velocity low pressure region outboard of the laptop's intake.

**Response:** treat the rear gap as a pressure-fed plenum and the upper rail as a downstream restriction. Actual through-laptop flow and hot-plume distance require models or measurements beyond the later 2D screen.

## 4. Sketch and vent alignment

> something like this. doesn't have to seal, just has to be high pressure at vent high velocity beyond. check vent layout dims to align the restriction / outlet properly

**Response:** interpret the attached annotated sketch as a separate rail above the intake band. The final dimensions use scaled Dell imagery, with uncertainty recorded rather than hidden.

## 5. FDM direction

> Lovely. now optimize each part for FDM 3d printing while maintaining the overall fit-up. Consider overhang angles, bridges, etc. Make this easy breezy for a P1S with ASA. I would like to print the brackets on their side for strength, and not on their back. Not that I could print these on their back anyway. Maintain the aesthetic polish as you go.

**Response:** build print orientations into the part geometry. Keep the cradles side-down and revise roofs, duct transitions and part splits around that constraint.

## 6. Choose useful analysis

> Let's talk through a few things real quick. Fluid dynamics? Airflow sim? Topological optimization? Generative structures? What would help and what can you do well, quickly?

**Response:** prioritize interpretable load paths, geometric print checks and flow comparisons. Later work includes actual OpenFOAM runs; no topology or generative solver is claimed.

## 7. Recover the checkpoint and retain bridges

> Also, grab the tail end of yesterday's transcript and the scratch workspace and wrap up this checkpoint?
>
> "Lovely. now optimize each part for FDM 3d printing while maintaining the overall fit-up. Consider overhang angles, bridges, etc. Make this easy breezy for a P1S with ASA. I would like to print the brackets on their side for strength, and not on their back. Not that I could print these on their back anyway. Maintain the aesthetic polish as you go."
>
> Also bridges are just fine, they're usually printable. Unsupported overhangs are bad. I guess in a duct the surface might be rough. Roll in the good ideas from the above and get me the efficient and printable package?

**Response:** preserve short bridges, distinguish them from unsupported ledges, and package oriented models with print and verification notes.

## 8. Reduce material

> I feel like we could get really creative and save a ton of plastic here.

**Response:** explore hollow sections, skins, framed trays and pocketed caps while keeping the original interfaces and side-print direction.

## 9. Proceed

> yes, do it.

**Response:** produce the lightweight Revision E. Its solid CAD volume is 35.7% below D; the later Revision F retains a 35.0% reduction after adding containment and revised assembly features.

## 10. Integrated Revision F

> Can we also make it tool free / ca glue assembly, except for the four wall bolts? And shroud the cheeks to keep air contained? And have the fans angle down so they're blowing at a 45 to the gap instead of straight in? And do some cfd to design the plenum and slot? And download and scale images and cross sections of the machine to estimate its profile geometry?

**Response:** implement keyed CA joints, removable split pins, cheek shrouds and 45° fan modules. Download and scale manufacturer images; reconstruct an explicitly estimated profile. Run eight representative 2D OpenFOAM cases and retain their raw evidence and limitations.

## 11. Public report

> write up a report and push this as public to thereprocase github with good imgaes and a process readme?

**Response:** curate the current files, write an illustrated engineering report and process narrative, and prepare the public repository. Keep previous checkpoints out of the main download and preserve the numerical evidence.

## 12. Fit allowances

> what tolerances did you assume for slide to fit parts?

**Response:** inspect the source geometry. Record 0.30 mm horizontal dovetail allowance per side, 0.30 mm crown and 0.20 mm root clearance; distinguish these from normal flank clearance. Document fixed-key and printed-pin fits separately. No global ASA shrink correction is assumed.

## 13. Repository destination

> https://github.com/thereprocase/dell-5560-wall-mount

**Response:** use the supplied public repository and retain its existing MIT license.

## 14. Explain the engineering process

> Enumerate your workflow and thinking, list my prompts as part of the dialogue, what you did at each stage, and what software and packages you used and how you approached the problem solving. Make the readme a thrilling read for an experienced mechanical engineer (not with thrilling adjectives and fluffy puffy bullshit, just by being well written and concise).

**Response:** structure the README around the decisions, tools and evidence. Include the pressure/flow tradeoff, the intake-window discovery, the small effect of the curved turn, the distinction between CAD clearance and printer capability, and the physical tests that remain.

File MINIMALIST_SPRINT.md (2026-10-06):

# Minimalist release development

## Scope and current boundary

Revision H is the ducted prototype. Its exact native model and prototype print
files remain available. Subsequent ducted releases may redesign the arms too;
the prototype's print freeze is not a permanent product constraint.

The minimalist fork is a complete independent set with no frozen parts. Its
purpose is to hold a laptop on a wall and point fans up its back while reducing
plastic and print time. Most enclosed ducting is removed. Structural webs,
fastener lands and working airflow surfaces retain the material they need.

Deliver an editable native FreeCAD model descended through Save As from the
Revision H model, with constrained sketches, stock features, an organized
parameter sheet, and reproducible builders. Keep construction visible in the
FreeCAD GUI and read its error log. Maintain 0.30 mm nominal clearance at new
printed mating surfaces, documenting intentional retention interference.

The target printer is a P1S with a 0.4 mm nozzle and ASA. OrcaSlicer is the
default for preparation and review. STEP/STL/3MF outputs carry their actual
print orientations; CAD acceptance and sliced paths do not prove physical fit
or warm-load durability.

## Implementation sequence

1. Preserve the Rev H prototype and supply print-oriented STEP files.
2. Create `codex/minimalist-release` in its own worktree and Save As the FCStd.
3. Build perforated structural arms, open fan cradles and removable retainers.
4. Add a positive ladder adjustment: two rungs engaged by a removable key,
   retained by a printed pin. The optional dam moves in discrete vertical steps.
5. Parameterize actual laptop width, base-to-hinge depth, closed thickness,
   rear wall gap, and fan dimensions. Screen-size labels are convenience presets,
   not a fit guarantee. Include 13, 14, 15.6, 16 and 17 inch classes.
6. Validate nominal and changed configurations, assembly and service clearances,
   load-path estimates, native reopen, meshes, and P1S-oriented slices. Compare
   material and print time with the ducted prototype using stated settings.
7. Publish the model, print files, measured comparison and interactive Pages
   presentation. Complete the Rev H gallery's missing corrected-geometry views.

## CFD coordination

The CFD collaborator owns `fusion/cfd/` additions and a self-contained
`docs/simulation/revh-transient/` package in `codex/cfd-revh-transient`.
The main Pages layout and minimalist model are owned here. Integrate the CFD
package when the collaborator provides actual results and provenance. The
836,278-cell Revision F exploration must never be relabeled as Revision H or
minimalist CFD. There are no new CFD results at this sprint's start.

## Checkpoints

- 2026-09-08: recovered the complete interrupted conversation and scope.
- 2026-09-08: all 14 Rev H STEP exports reimported as valid solids, matched
  released STL bounds, and delivered in print orientation for the prototype.
- 2026-09-08: independent minimalist branch/worktree created from `f47a03f`.

- 2026-09-08: native M1 complete: 20 installed parts, 51 constrained sketches,
  six dimensioned presets and all nine indexed dam positions checked.
- 2026-09-08: every preset saved/reopened, with valid STEP roundtrips, closed
  print meshes and P1S bed/brim/cutter clearance. Native clean reconstruction
  from the preserved H source also passes the nominal independent validator.
- 2026-09-08: full nominal Orca estimate 388.05 g / 15 h 24 m 54 s, compared
  with 1183.88 g / 34 h 00 m 15 s for the complete H layout. The expanded
  path review includes Overhang wall and all other extrusion features; bridge
  labels alone omitted 8.99 mm fan-hanger and 6.12 mm dam-slot spans.
- 2026-09-08: eight native-derived fit samples include both attachment build
  directions. Physical fit, retention, creep, anchors and cooling remain open.
- 2026-09-08: interactive site passed six-preset, dam-index, exploded-view,
  Rev F/H comparison, CFD gallery and mobile-layout checks. Archive publication
  and final download verification follow the completed all-feature path audit.
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

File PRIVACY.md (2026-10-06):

# Public snapshot privacy review

The October 2026 publication removes personal workstation usernames and hostnames
from documentation, source-path examples, solver logs, compressed logs and packaged
print assets. Commit authors use the public GitHub noreply identity.

Geometry, mesh topology, print toolpaths and scientific result data are preserved.
SHA-256 references for modified source, logs and packages are refreshed. Historical
engineering qualifications remain unchanged; this review is not physical validation.

The review includes nested ZIP/3MF/FreeCAD assets, gzip evidence, reconstructed
multipart CFD evidence, image metadata, PDF text and metadata, and release assets.
Upstream support contacts and license attributions remain intact.

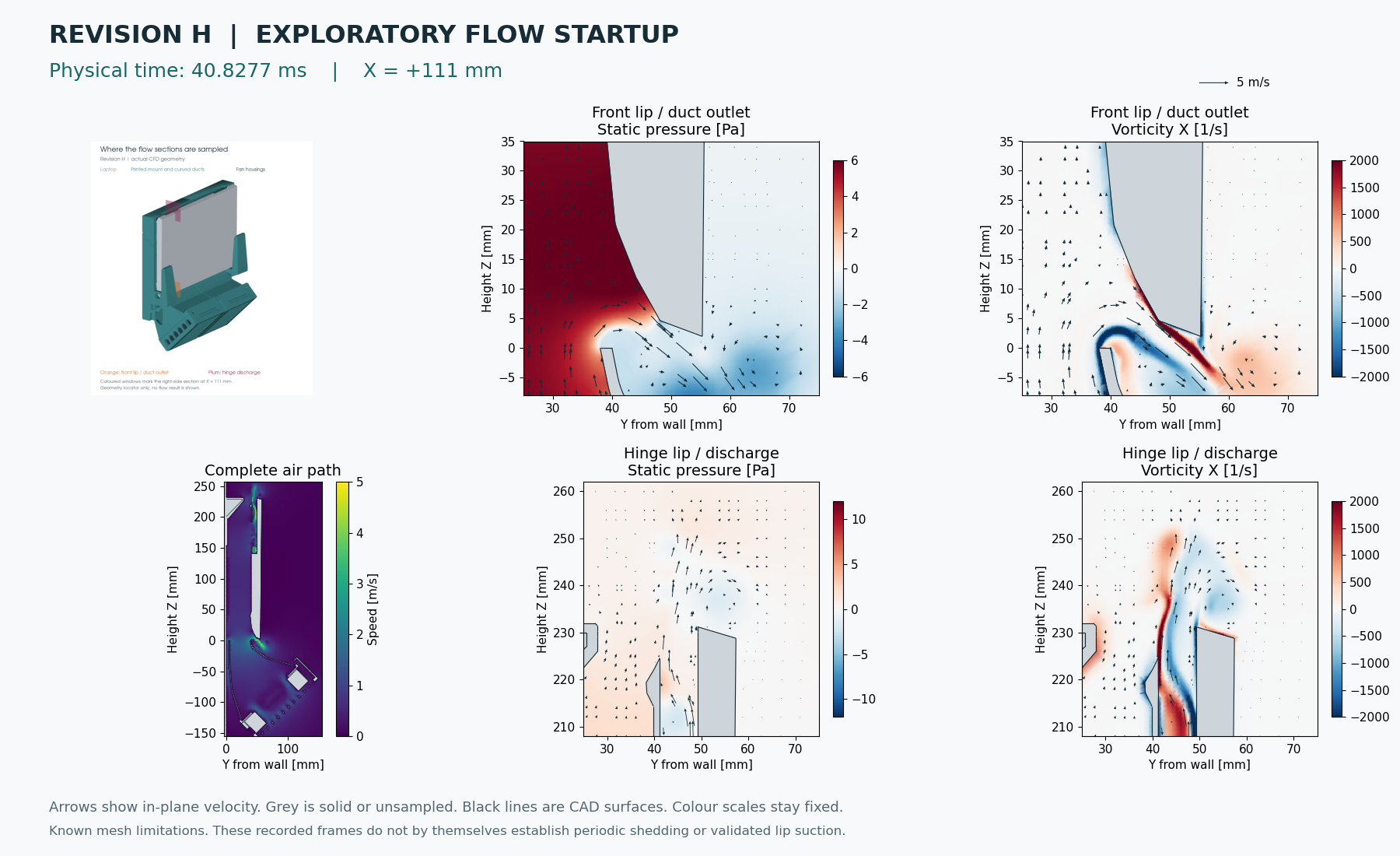
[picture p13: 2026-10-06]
docs/simulation/revh-transient/sequence/checkpoint-04/poster.png

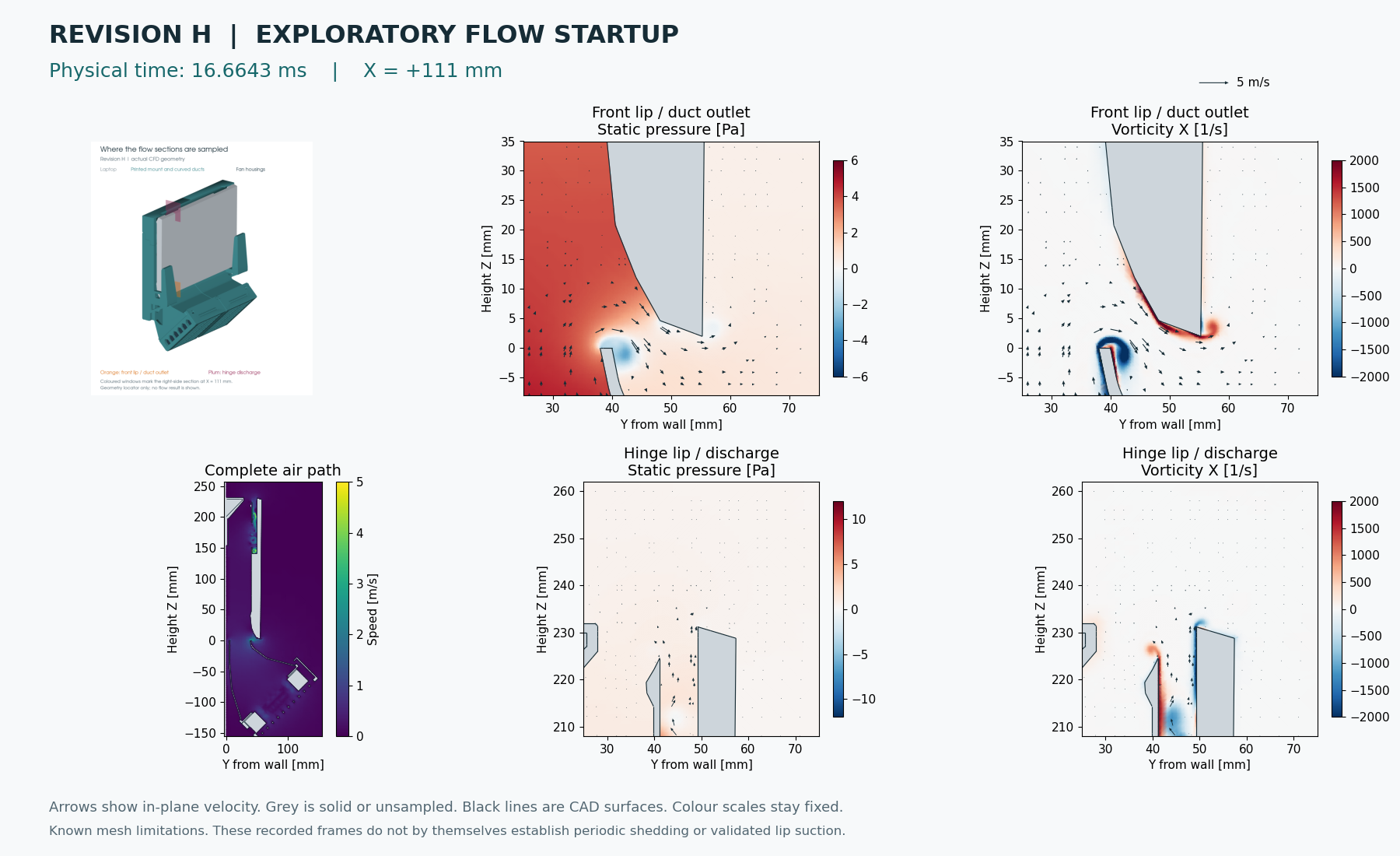
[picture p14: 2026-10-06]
docs/simulation/revh-transient/sequence/hour-5/poster.png

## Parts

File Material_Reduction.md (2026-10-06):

# Revision F material checkpoint

Current solid CAD volume: **1177.3 cm³**, **35.0% below Revision D**.
Revision E used 1164.2 cm³; shrouding, angled modules and printed pins change
the total by +13.1 cm³ (about +14.0 g at 1.07 g/cm³ ASA).
This is a CAD volume comparison at equal infill policy, not sliced consumption.

Hollow bracket boxes, a thin continuous outlet skin, thin duct walls, framed
fan trays and pocketed caps retain the earlier material savings. The laptop
load still travels through the cradle shelves/spines to the four wall bolts.
Fixed fan/rail joints use broad keyed shoulders and CA for withdrawal restraint.
The package contains no solved topology optimization or generative lattice.

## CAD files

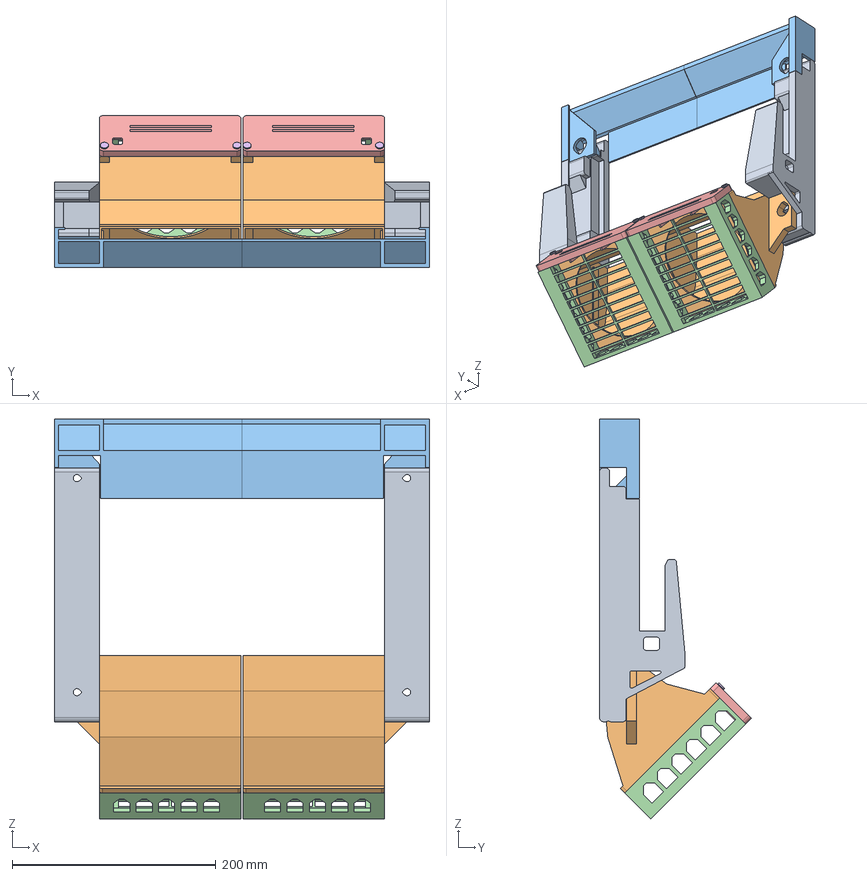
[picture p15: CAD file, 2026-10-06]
fusion/output/native/assembly.step
368.0 x 149.0 x 392.4 mm
5560-F-CRADLE-R
5560-F-DUCT-R
5560-F-RAIL-R
5560-F-TRAY-R
5560-F-CAP-R
5560-F-PIN-R x 4
5560-F-CRADLE-L
5560-F-DUCT-L
5560-F-RAIL-L
5560-F-TRAY-L
5560-F-CAP-L

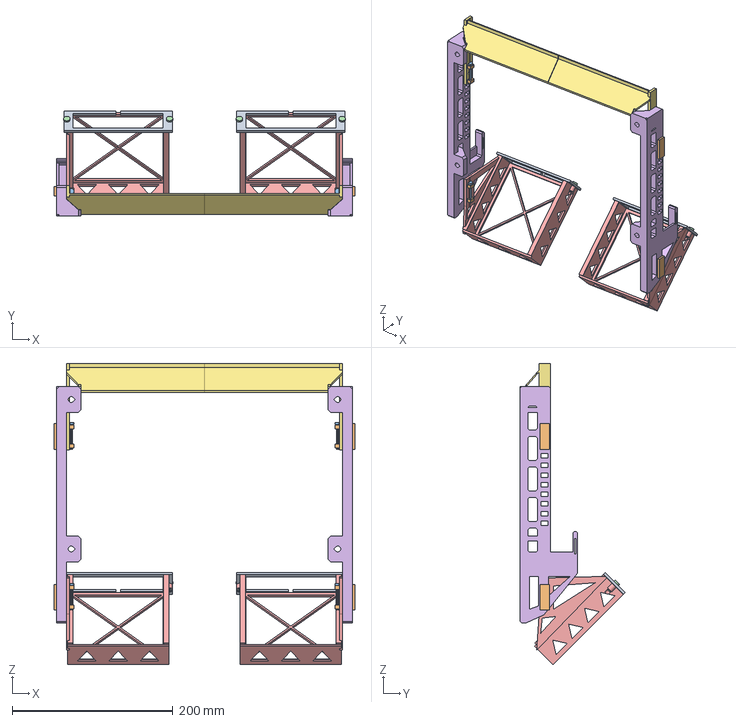
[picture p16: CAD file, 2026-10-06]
minimalist/presets/15-6-inch-example/print/M1_assembled.step
374.6 x 131.2 x 375.0 mm

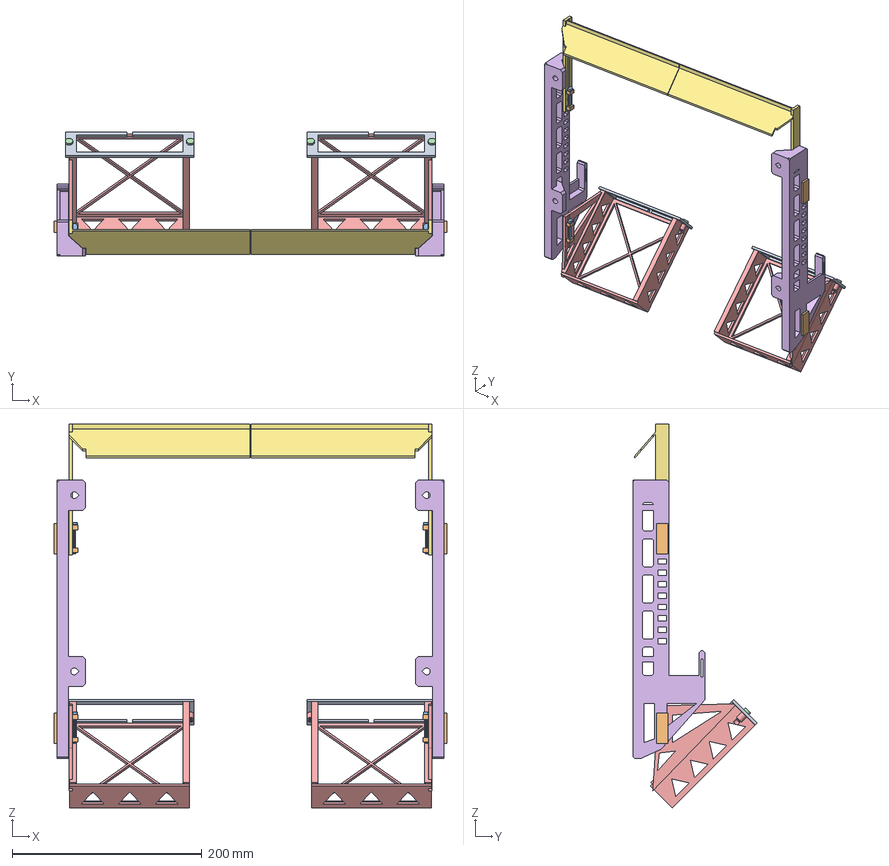
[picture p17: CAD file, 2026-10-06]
minimalist/presets/17-inch-example/print/M1_assembled.step
414.6 x 131.2 x 405.0 mm

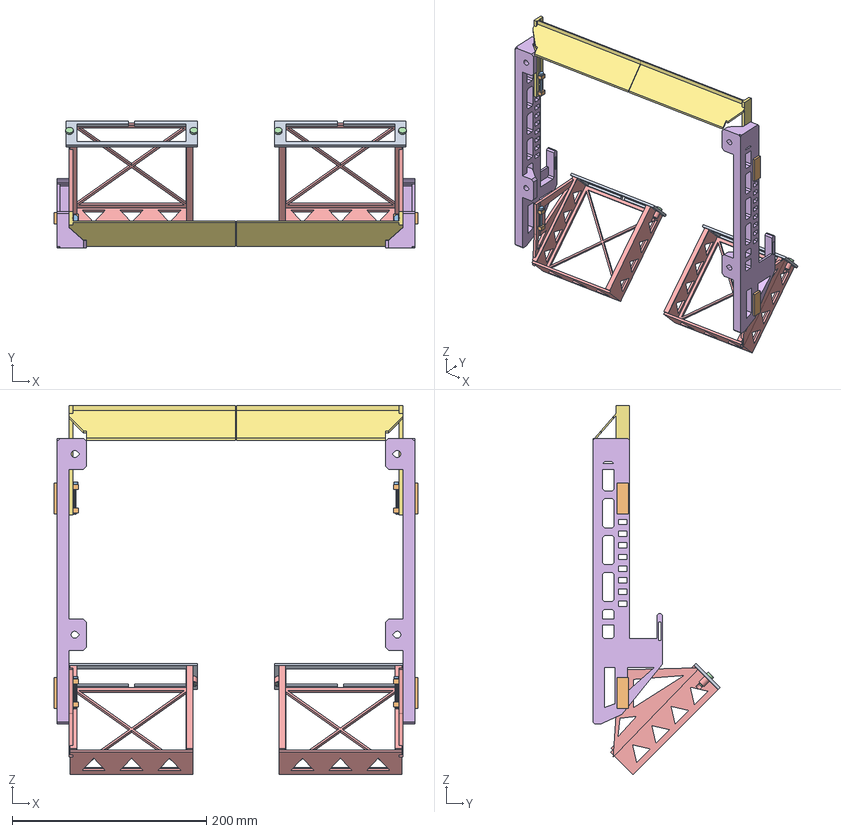
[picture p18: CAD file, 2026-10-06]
minimalist/presets/16-inch-example/print/M1_assembled.step
374.6 x 131.2 x 380.0 mm

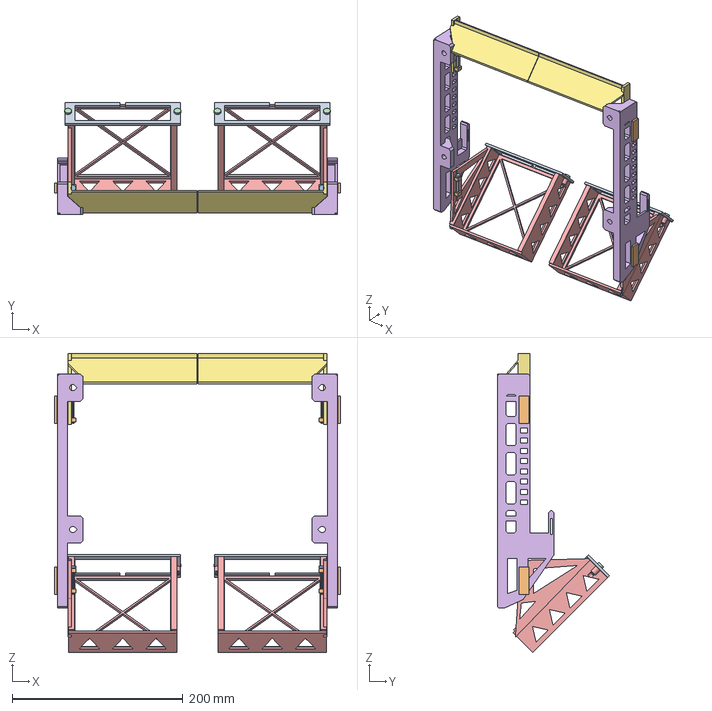
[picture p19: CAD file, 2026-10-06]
minimalist/presets/14-inch-example/print/M1_assembled.step
334.6 x 131.2 x 350.0 mm

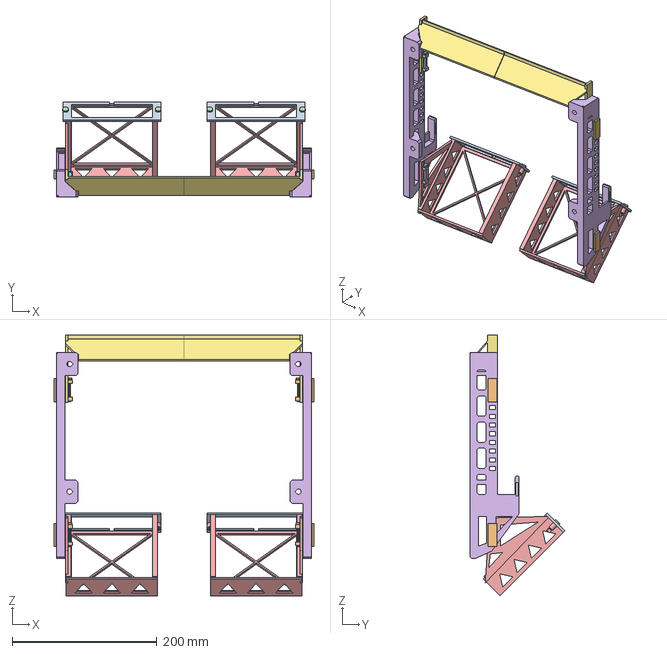
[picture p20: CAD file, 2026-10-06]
minimalist/presets/5560/print/M1_assembled.step
359.0 x 131.2 x 360.3 mm

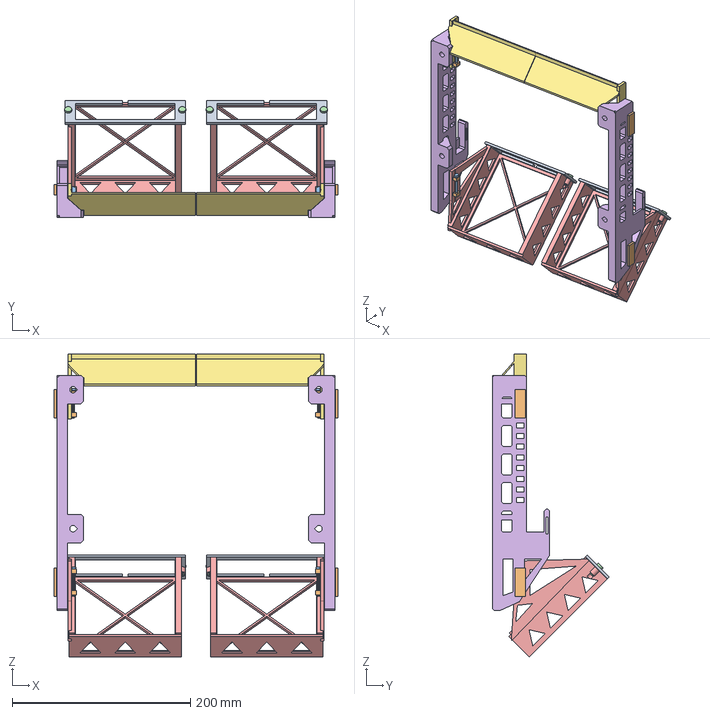
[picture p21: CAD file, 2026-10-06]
minimalist/presets/13-inch-example/print/M1_assembled.step
318.6 x 131.2 x 340.0 mm

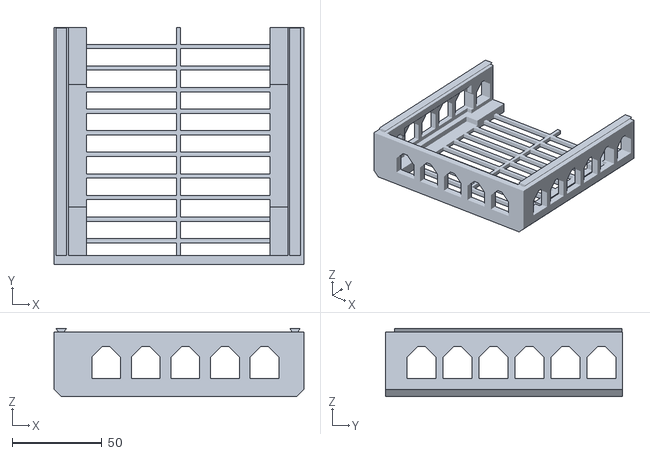
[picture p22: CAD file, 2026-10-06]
docs/downloads/10_right_fan_tray.stl
139.0 x 131.7 x 38.0

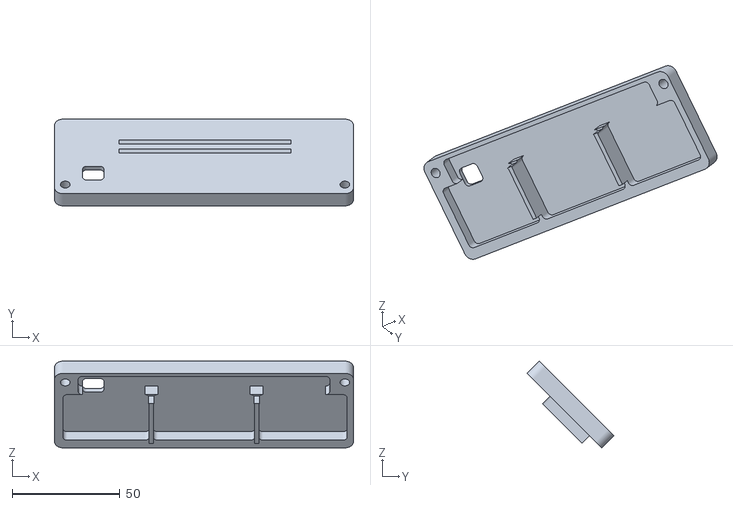
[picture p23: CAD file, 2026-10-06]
docs/models/after/05_left_fan_retainer.stl
139.0 x 40.3 x 40.3

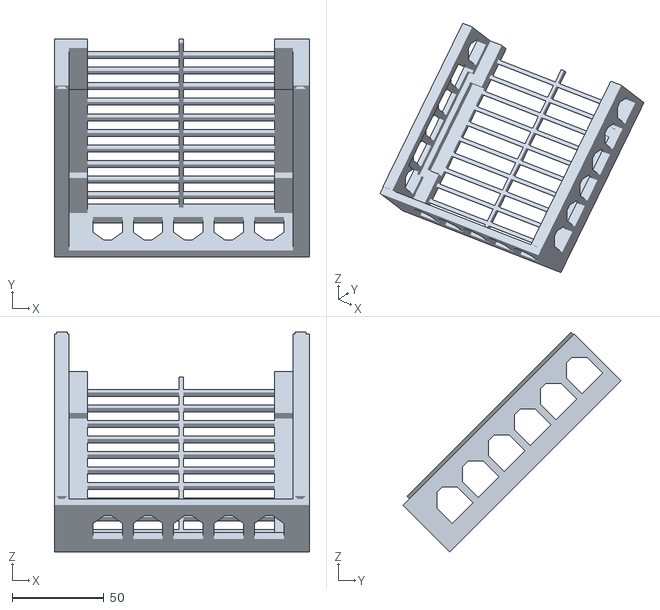
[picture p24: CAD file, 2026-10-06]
docs/models/before/10_right_fan_tray.stl
139.0 x 118.8 x 119.9

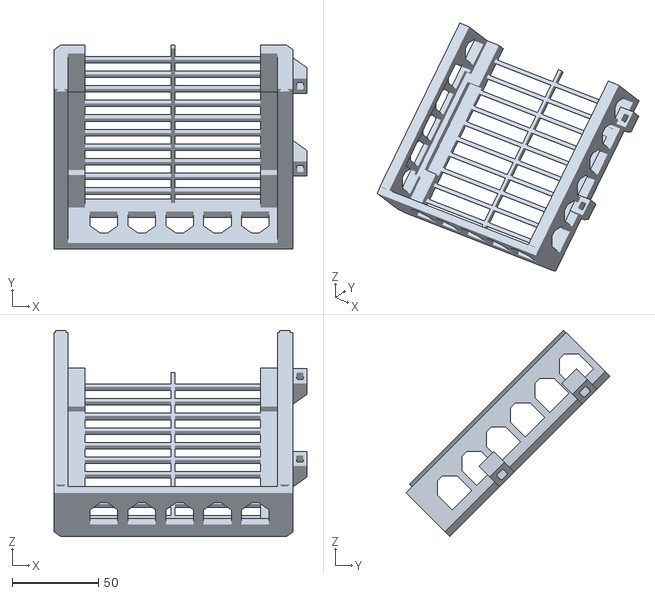
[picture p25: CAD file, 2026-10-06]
docs/models/cables/10_right_fan_tray.stl
147.0 x 118.6 x 119.9

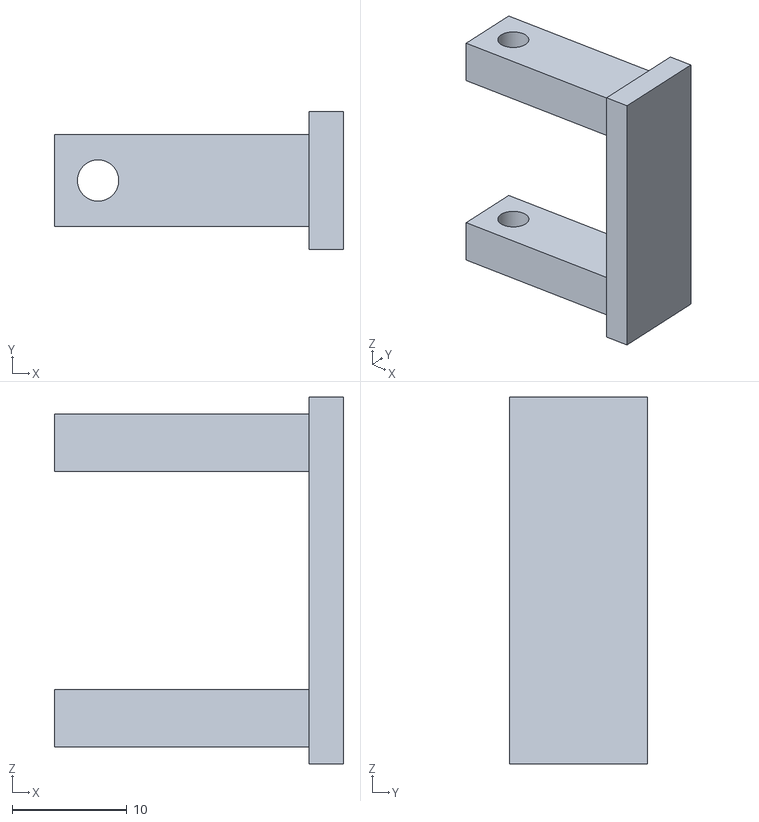
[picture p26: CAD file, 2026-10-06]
docs/models/minimalist/13-inch-example/10_right_fan_key.stl
25.2 x 12.0 x 32.0

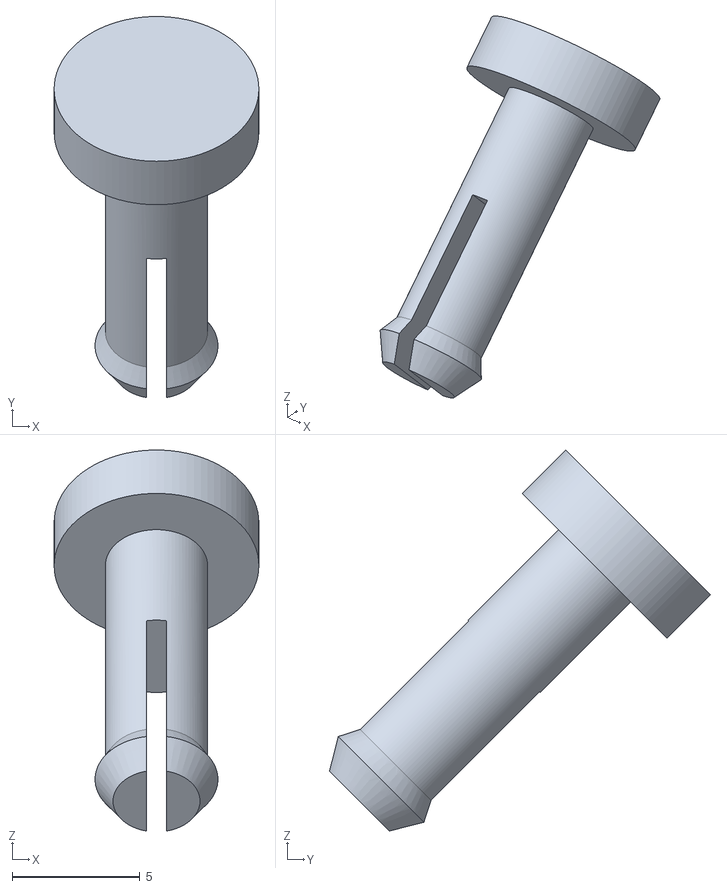
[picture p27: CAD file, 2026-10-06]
docs/models/minimalist/17-inch-example/20_right_cap_pin_2.stl
8.00 x 14.9 x 14.9

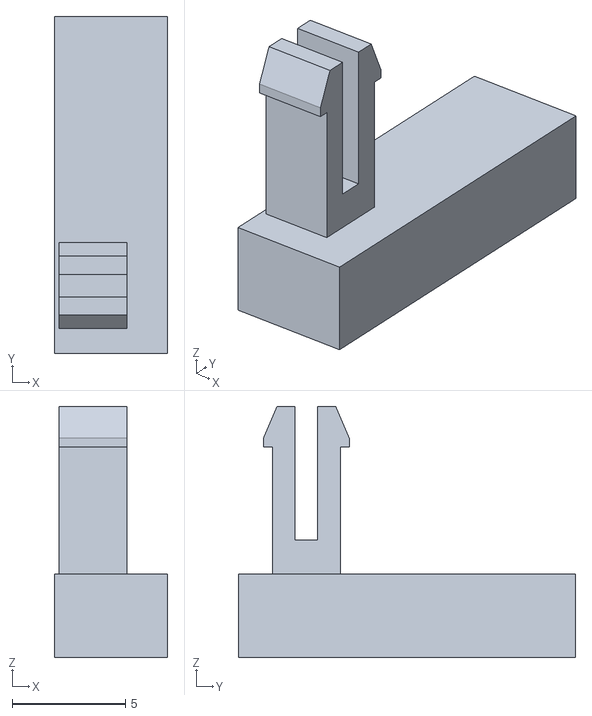
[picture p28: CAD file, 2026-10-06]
docs/models/retainers/17_left_retainer_keeper.stl
5.00 x 14.9 x 11.1

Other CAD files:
docs/models/minimalist/14-inch-example/09_left_fan_key.stl
docs/models/minimalist/15-6-inch-example/10_right_fan_key.stl
docs/models/minimalist/16-inch-example/09_left_fan_key.stl
docs/models/minimalist/5560/19_left_cap_pin_2.stl
Precision_5560_Wall_Mount.step
REFERENCE_Estimated_Laptop_Profile.step
REFERENCE_Installed_Layout.step
docs/downloads/03_left_fan_duct.stl
docs/downloads/03_left_fan_duct_D4.stl
docs/downloads/04_right_fan_duct.stl
docs/downloads/04_right_fan_duct_D4.stl
docs/downloads/07_left_outlet_rail.stl
docs/downloads/08_right_outlet_rail.stl
docs/downloads/09_left_fan_tray.stl
docs/models/after/01_left_cradle.stl
docs/models/after/02_right_cradle.stl
docs/models/after/03_left_fan_duct.stl
docs/models/after/04_right_fan_duct.stl
docs/models/after/06_right_fan_retainer.stl
docs/models/after/07_left_outlet_rail.stl
docs/models/after/08_right_outlet_rail.stl
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

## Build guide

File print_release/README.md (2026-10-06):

# Revision H - preserved ducted prototype print set

Print one each of 01-14. STL and 3MF are alternatives for the same part; do not
print both formats. Standard 3MF models contain millimeter geometry and baked
orientation, not slicer settings or G-code.

This is the preserved Rev H prototype print set. Original root print_ready/ and Fusion/Onshape
ports remain Revision F baseline/history. Six parts are revised: ducts, trays,
and outlet rails. Both cradle/arm files are byte-identical to the already-printed
Revision F files. Caps and four pins are also unchanged.

P1S / ASA: 0.4 mm nozzle, 0.20 mm layers, 6 walls, 6 top/bottom layers, 100% fill
of the explicitly hollow CAD, 8 mm outer brim, supports off. Cradles outer-side
down with the supplied diagonal rotation; ducts inlet down; trays grille down;
caps front down; rails lip down; pins button down. Keep the baked orientations.

Fan-interface and rail-to-arm clearances measure 0.30 mm. Pin retention keeps
its intentional interference; fixed load shoulders retain seating contact.
Separate native loft-skin patches close the unintended duct-wall notches.
Revision H adds three R12 tangent airway blends per duct with two R14 exterior
support blends. Inlet and outlet profiles remain fixed. Sampled new bend walls
are at least 1.60 mm; sampled new curved overhangs stay below 40 degrees in the
inlet-down orientation. Cooling performance is not yet physically validated.

Final checks: valid native solids, constrained sketches, unchanged printed arms,
wall continuity, assembly/service clearances, closed meshes, and bed/brim/cutter
fit. Physical fit, ASA bridge quality, retention and slicer paths remain to be
checked. Use the root P1S_ASA_Print_Guide.md for material and assembly guidance.
Original fit coupons remain under print_ready/; full-length tray fit needs its
own check because the revised flank clearance is normal to the dovetail slope.

See manifest.json for hashes tying this print set to the native FCStd document.

## Orca bridge review, September 8, 2026

Both ducts need Bridge direction and Internal bridge direction set to 180°,
with Relative bridge angle and Align infill direction to model off. Keep the
baked inlet-down orientation. The corrected cross-slot paths have a maximum
unsupported span of 5.19 mm and no disconnected floating components. See
[the detailed instructions and reviewed previews](../print_release_step/ORCA_BRIDGE_REVIEW.txt).
Physical ASA bridge quality and retention still require a print check.

Rev H is a preserved prototype, not a permanent freeze on future ducted arms.
The independent [Minimalist M1 fork](../minimalist/) has new parametric arms.

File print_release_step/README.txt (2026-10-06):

REVISION H PROTOTYPE - PRINT-ORIENTED STEP FILES

14 parts, one of each numbered file. Parts 11-14 are four identical pins.
The arms (01-02) are included for completeness; yours are already printed.
This is the same geometry as the Revision H STL print release, not the
experimental 0.8 mm wall trial or the forthcoming minimalist design.

Open one STEP at a time in OrcaSlicer. Keep the baked orientation, use mm,
and do not auto-orient or scale. Each part sits at Z=0 centered on a 256 mm
P1S plate. Inspect the preview after importing because slicers can arrange
parts automatically. Do not print the whole folder together on one plate.

P1S / ASA starting setup: 0.4 mm nozzle, 0.20 mm layers, 6 walls,
6 top/bottom layers, 100% infill of the intentionally hollow CAD,
8 mm outer brim, supports off. Use the actual spool's ASA temperature and
drying instructions. Review bridges and the first layer before printing.
Both ducts need the corrected bridge direction described in
ORCA_BRIDGE_REVIEW.txt. Automatic bridge direction is unsuitable at the
long slots. The corrected paths pass the geometric screen; physical ASA
bridge quality still requires a print check.

Orientations: arms outer-side-down and diagonal; ducts inlet-down;
trays grille-down; caps broad front face down; rails lip-down; pins button-down.
Fit clearance is nominally 0.30 mm at the revised joints. Pin retention has
intentional interference. The existing fit coupons remain useful.

All 14 STEP files were reimported and checked for one valid solid, source
shape agreement, print-bed/brim clearance and matching Rev H STL bounds.
See manifest.json for per-file checks and hashes. STEP files are editable
exchange solids; the full native feature history remains in the FCStd model.

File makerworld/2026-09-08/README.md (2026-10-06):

# Repro laptop wall mounts

Three model families, with native Bambu Studio projects and CAD renderings.

**Publication status:** archived for later MakerWorld publication. No MakerWorld listing or print profile has been published. The owner will finish physical prints and lab photographs before resuming. See [the agent handoff](../../MAKERWORLD_HANDOFF.md).

**Testing status:** the owner reports physically printing and trying ducted hardware. The retained arms are specifically documented as printed; this does not establish a complete Revision H assembly test. These new profiles have virtual review only. The modular and fanless designs have not yet been physically printed or tested.

## Files

### 15.6-inch Laptop Ducted Cooling Wall Mount

- [Listing description](ducted/Listing.md)
- [Model files](https://github.com/thereprocase/dell-5560-wall-mount/releases/download/makerworld-prep-2026-09-08/Repro_ducted_Model_Files.zip)
- [Bambu Studio projects, physically untested](https://github.com/thereprocase/dell-5560-wall-mount/releases/download/makerworld-prep-2026-09-08/Repro_ducted_Bambu_Studio_Projects_UNTESTED.zip)
- Five gallery images are in the `ducted` folder.

### Modular Laptop Cooling Wall Mount

- [Listing description](modular/Listing.md)
- [Model files](https://github.com/thereprocase/dell-5560-wall-mount/releases/download/makerworld-prep-2026-09-08/Repro_modular_Model_Files.zip)
- [Bambu Studio projects, physically untested](https://github.com/thereprocase/dell-5560-wall-mount/releases/download/makerworld-prep-2026-09-08/Repro_modular_Bambu_Studio_Projects_UNTESTED.zip)
- Five gallery images are in the `modular` folder.

### Minimal Laptop Wall Mount

- [Listing description](fanless/Listing.md)
- [Model files](https://github.com/thereprocase/dell-5560-wall-mount/releases/download/makerworld-prep-2026-09-08/Repro_fanless_Model_Files.zip)
- [Bambu Studio projects, physically untested](https://github.com/thereprocase/dell-5560-wall-mount/releases/download/makerworld-prep-2026-09-08/Repro_fanless_Bambu_Studio_Projects_UNTESTED.zip)
- Five gallery images are in the `fanless` folder.

## Printer and material coverage

All projects use a 0.4 mm nozzle and textured PEI plate. Each archive contains its own printer-specific toolpaths. Do not treat cached G-code as interchangeable between printers.

| Printer | PLA Basic | PETG HF | ASA |
|---|---|---|---|
| P1S | All three designs | All three designs | All three designs |
| X1C | All three designs | All three designs | All three designs |
| P2S | All three designs | All three designs | All three designs |
| H2S | All three designs | All three designs | All three designs |
| H2D | All three designs | All three designs | All three designs |
| H2C | All three designs | All three designs | All three designs |
| A1 | All three designs | All three designs | Not supplied |

A1 mini is excluded. The modular print profiles use the 5560 reference size; six measured size presets are included in its raw model bundle.

## Process settings

The projects use 0.20 mm layers, four walls, six top and bottom layers, and 20% gyroid infill. These are prototype settings, not a calculated load rating. The same shell baseline is retained across materials; temperature, cooling, flow, speed limits, and brim settings come from the selected material setup. More shells do not compensate for PLA's heat and creep limits.

The ducted projects add build-plate tree supports to the two duct objects only. They address long slot-roof edges found in Bambu's toolpaths. The other parts have supports disabled. Removal quality and sliding fit still need a physical test.

## Verification

60 native projects were generated with BambuStudio-02.07.01.62, BambuStudio-02.08.02.61. Archive integrity, saved settings, embedded toolpaths, plate thumbnails, and duct support overrides were checked. Source downloads were verified against Git blob hashes. These checks do not establish physical print quality or strength.

[Project hashes and plate counts](verification.json)

## Publish and revise

Keep one listing per design family. Add printer/material choices through print profiles rather than duplicate model pages. Use MakerWorld's supported-printer grouping where available. Do not mark an untested profile as test-printed.

Add a clear real photo of the printed object to each model gallery. Mark renders as renders. Record the source revision, print profile, material, printer, observed fit, and test conditions when updating the testing status.

MakerWorld model-photo rule: https://wiki.bambulab.com/en/makerworld/tutorials/model-upload-guidelines

Source: thereprocase/dell-5560-wall-mount. Main revision 29c666e9c02812def1e6f23a56b6115a6c3e329d; fanless cloud-topo revision 9fd0e98c43217678ce165d8f76c6a55abbf3c144. Model source license: MIT.

## Gallery and archived files

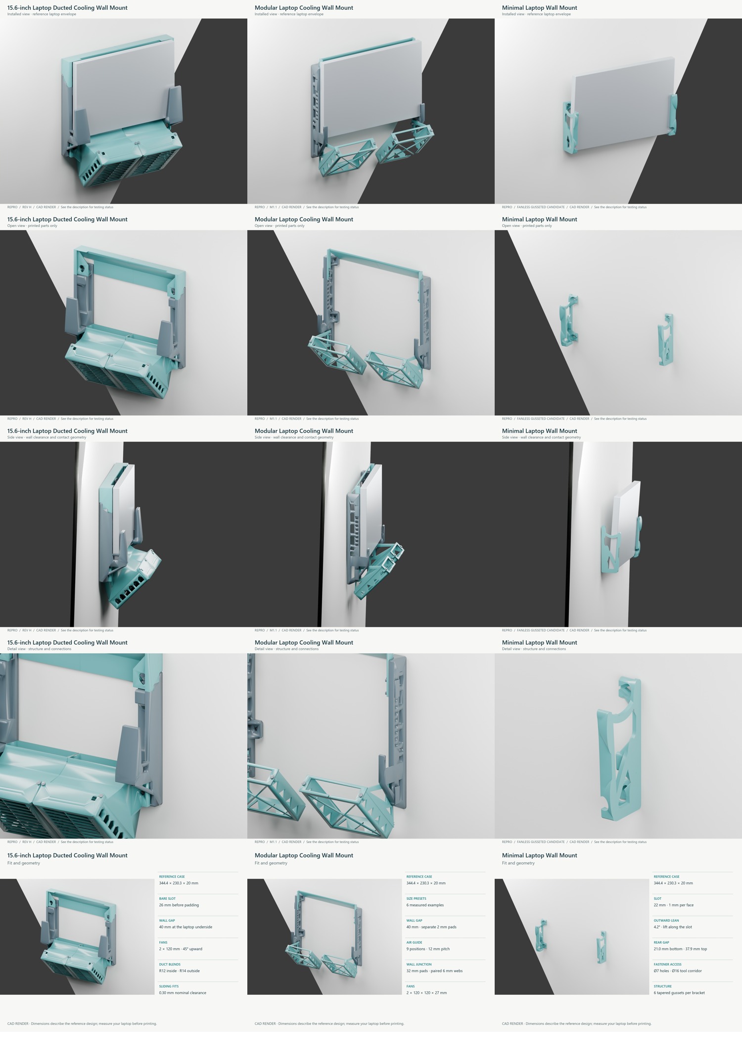
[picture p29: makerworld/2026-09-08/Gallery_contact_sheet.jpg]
CAD gallery contact sheet


[Release downloads](https://github.com/thereprocase/dell-5560-wall-mount/releases/tag/makerworld-prep-2026-09-08) contain the large sliced projects, model bundles, listing/gallery archive, and editable render scenes. [Asset sizes and SHA-256 hashes](https://github.com/thereprocase/dell-5560-wall-mount/blob/main/makerworld/2026-09-08/release-assets.json) identify this snapshot. Keep large archives as release assets.

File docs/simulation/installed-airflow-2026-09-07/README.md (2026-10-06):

# Installed airflow / technical review

Seven A3 landscape sheets document the first full installed-airflow exploration of the Dell Precision 5560 wall mount. The drawings use the reconstructed iteration-1200 CFD fields and CAD-derived geometry.

[**Open the technical review PDF**](Precision_5560_CFD_Technical_Review.pdf) · [**Download the complete package**](https://github.com/thereprocase/dell-5560-wall-mount/raw/refs/heads/onshape-native-rebuild/docs/simulation/installed-airflow-2026-09-07/Precision_5560_CFD_Drawing_Pa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)

The ZIP includes the PDF, seven individual 150 dpi PNG sheets and provenance manifests. Views are not to scale; these are simulation review sheets, not fabrication drawings.

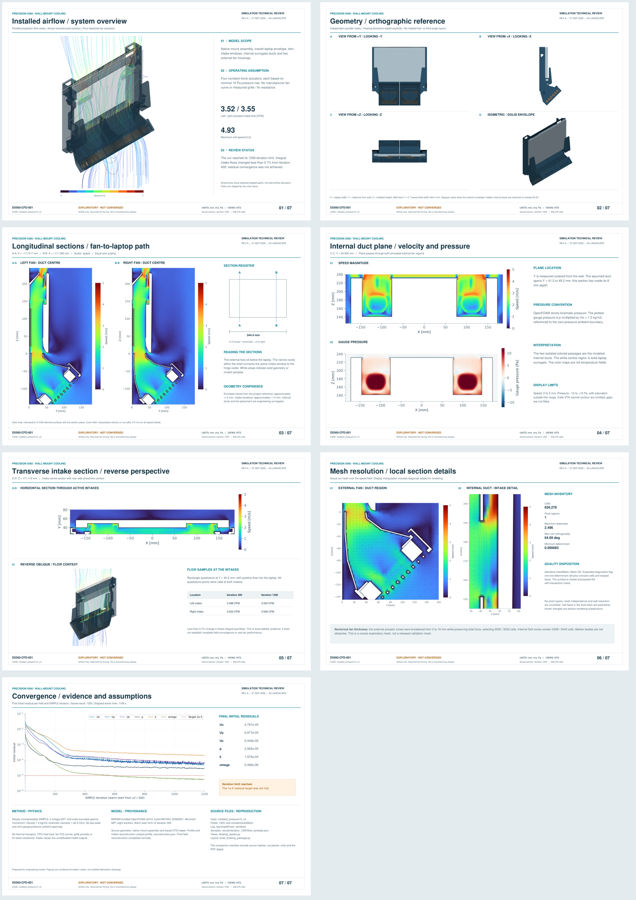
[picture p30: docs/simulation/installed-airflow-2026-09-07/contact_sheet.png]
Overview of all seven simulation drawing sheets


| Sheet | Content |
|---|---|
| 01 | Installed system isometric, streamlines and run summary |
| 02 | Independent orthographic views and solid isometric |
| 03 | Left and right longitudinal fan/duct sections and section locator |
| 04 | Internal duct plane: speed and gauge pressure |
| 05 | Transverse intake section, reverse flow view and intake samples |
| 06 | External and internal mesh details with quality disposition |
| 07 | Residual histories, assumptions and provenance |

## What this run establishes

The case contains 836,278 cells in one connected fluid region. BARAM's bundled OpenFOAM v2412 solver completed 1,200 SIMPLE iterations in 1,166 seconds and reconstructed the final fields. The sampled intake flows were 3.520 CFM on the left and 3.546 CFM on the right, less than 0.7% different from their iteration-400 values.

**The run did not meet its 1e-5 residual target.** Stable intake integrals do not establish full field convergence. All four fans use assumed constant-force actuators based on nominal 10 Pa pressure rise. The internal laptop ducts are surrogates; fan curves, grille/fin resistance and thermal loads are not modeled. These values are uncalibrated simulation outputs, not measured hardware performance.

Standard `checkMesh` reported Mesh OK. Expanded checks retained one low-determinant cell and concave/warped-cell diagnostics. No prism layers or mesh-independence demonstration are included. VTK omits cells it cannot contour; plotted gaps are not filled.

## Evidence and reuse

- [Sampled intake and fan flows](flow_samples.json)
- [Cut coordinates, units and final residuals](plot_provenance.json)
- [PDF and source-file hashes](drawing_package_manifest.json)
- [Laptop profile and intake reconstruction](../../../profile_reconstruction.json)
- [Project reference sources](../../../SOURCES.md)

The manifest preserves original workspace-relative source names. Full solver fields, native CAD build tooling and rendering dependencies are not included in this drawing publication. The documents and sheet images can be used independently; reproducing the CFD solve requires those additional inputs. Earlier local `geometry_manifest.json` readiness flags describe preparation-time state, not the completed run.

Revision A, 7 September 2026. This installed 3D case is separate from the repository's earlier sealed 2D plenum study.

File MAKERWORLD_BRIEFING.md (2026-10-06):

Briefing for the agent preparing the MakerWorld early-adopter release

Prepared September 8, 2026. Package the published laptop wall-mount designs for experienced early adopters who can measure their machine, print fit coupons, and report results. Make the listings welcoming and easy to follow while being explicit about what remains untested. Use the current released geometry and retain the revision names throughout the files, descriptions and images.

Use a checkout of `thereprocase/dell-5560-wall-mount`; file paths below are relative to its root. The geometry snapshot is commit `8a3e1578beca56075d8f48235a3a1bac8fccd034`. Main was synchronized through `ba36330` before publishing this briefing, preserving H-R1 and the newer CFD sequence and video work. The owner previously confirmed `e8d4070` on main and Pages; later simulation publications do not by themselves change the print geometry. Inspect current state before changing anything and preserve the other agent's CFD work. Use an isolated worktree if editing the repository. This briefing supplies engineering and packaging context; continue under the user's existing instructions for your upload task.

The public starting points are the [project and interactive models](https://thereprocase.github.io/dell-5560-wall-mount/), [GitHub source](https://github.com/thereprocase/dell-5560-wall-mount), [M1.1 print and assembly guide](https://thereprocase.github.io/dell-5560-wall-mount/minimalist-guide.html), and [H-R1 installation guide](https://thereprocase.github.io/dell-5560-wall-mount/revh-retainers.html). Keep those links in the listings so adopters can find current instructions and revisions.

There are two independent mount designs and one add-on. Suggested listing structure:

| Suggested title | Scope and files |
|---|---|
| **Minimalist Laptop Wall Mount M1.1 — Early-Adopter Prototype** | Main open-frame design with two removable fan cradles and an optional indexed airflow dam. Six dimensioned examples. Files: `minimalist/presets/<name>/print/`; native files and coupons under `minimalist/`. |
| **Dell Precision 5560 Ducted Wall Mount Rev H — Early-Adopter Prototype** | Separate, heavier ducted design. Fourteen original parts. Files: `print_release/` and `print_release_step/`; native source: `freecad/Precision_5560_Native.FCStd`. |
| **Rev H-R1 Removable Retainers — Rev H Add-On** | Two side bars and two keepers for the preserved Rev H geometry. Requires the Rev H mount; does not fit M1.1. Files: `revh_retention/print/`; native source and engineering notes in `revh_retention/`. |

Cross-link the listings. Make M1.1 the lead option for people starting from scratch, with the material estimate and open-frame construction explaining that choice. Present H-R1 as an accessory, never as a complete four-part mount. The six M1 sizes belong together as clearly named variants where the platform permits. Do not mix M1 and Rev H parts. Root `print_ready/`, root assembly STEP, and the original Fusion/Onshape ports contain Revision F history; they are not the current Rev H release. Leave unrelated development branches out of this release.

**Cable-management update, H-C1:** the [new cable guide](https://thereprocase.github.io/dell-5560-wall-mount/revh-cables.html) supplies replacement Rev H covers **05/06** with edge-open, lay-in cable grooves and trays **09/10** with two external zip-tie anchors each. The tray closes the cable passage when the cover is fitted, so the connector never needs to pass through a hole. Four replacements, not four added parts; they work with or without H-R1 and leave the printed arms, ducts, rails, pins and H-R1 geometry unchanged. Use `revh_cables/print/` and `docs/downloads/Precision_5560_RevH_Cable_Management_C1.zip`. Start with `00_cable_fit_coupon`; then print `20_both_cable_covers` plus trays 09/10, three full-size plates. Preserve the older Rev H files as a named baseline and make the C1 replacement choice explicit within the Rev H listing. Read `revh_cables/release-report.json` for current estimates; do not reuse the old cover/tray totals. The checked 4 mm cable envelope has 0.5 mm minimum gap; cable fit, abrasion and tie-lug strength remain physically untested. This update does not change M1.1 or establish a new CFD/cooling result.

Use an opening disclosure along these lines:

> This is an early-adopter prototype with editable CAD, print files, fit coupons and illustrated assembly instructions. CAD and slicer checks have been completed, but complete physical fit, joint retention, long-term deformation and cooling performance remain unqualified. Start with the fit coupon and a supported trial assembly, and help improve the design by reporting measured fit and printing results.

The owner has reported printing the preserved Rev H arms. That does not establish a successful complete Rev H assembly, an M1 print, or an H-R1 retention test. Recheck whether the owner has newer physical results or genuine photographs before describing anything as printed or tested. Avoid claims of a rated laptop weight, universal compatibility, proven cooling gains, or doubled strength. M1.1's larger wall junction is a measured CAD section change, not a tested strength multiplier.

M1.1's nominal closed-laptop envelope is **344.4 × 230.3 × 20 mm**, with a **40 mm rear gap**, separate **2 mm compliant contact pads**, and two modeled **120 × 120 × 27 mm fan envelopes** aimed 45° up the rear gap. A 25 mm fan requires suitable spacing to prevent rattle. Check the actual fan body, wire exit and connector. Additional required items include the fans and suitable power arrangement, compliant pads, and four wall fasteners with washers and anchors selected for the actual wall. No specific wall anchor has been qualified.

The six M1 examples are:

| File/preset name | Closed case width × depth × thickness |
|---|---|
| `5560` | 344.4 × 230.3 × 20 mm |
| `13-inch-example` | 304 × 210 × 16 mm |
| `14-inch-example` | 320 × 220 × 18 mm |
| `15-6-inch-example` | 360 × 245 × 24 mm |
| `16-inch-example` | 360 × 250 × 24 mm |
| `17-inch-example` | 400 × 275 × 28 mm |

Screen diagonals are labels, not fit specifications or a continuous validated size range. Ask adopters to measure width, depth and maximum closed thickness, including feet and protrusions, then check vents, ports and contact points. Custom sizes should be generated through the native FreeCAD parameters and rechecked; uniform slicer scaling also changes the fan seats, fastener bores and printed fits. M1 needs at least 43 mm upward laptop movement for removal; do not copy the historical Rev F 110 mm overhead instruction into its listing.

Printing instructions must prevent duplicate parts:

1. **M1.1 coupon first:** `minimalist/coupons/00_fit_coupon_plate.3mf`. It exercises the key, keeper, fan-hanger and cap-pin interfaces in their full-part print directions.
2. **M1.1 with dam:** print one each of **01–08 plus `21_all_hardware`**, nine supplied plates and twenty installed parts. The twelve individual files 09–20 are replacement alternatives already included on plate 21.
3. **M1.1 without dam:** print **01–06 plus `22_hardware_without_dam`**, seven plates and fourteen installed parts. Use plate 22 instead of plate 21. The optional dam has nine positions over 96 mm; both sides must use the same index.
4. **Rev H:** print one each of **01–14**. Parts 11–14 are four pins. Owners with the matching arms already printed need only 03–14 for the original assembly. Keep H-R1 as four additional parts if using removable withdrawal retention.
5. **H-R1 coupon first:** print `revh_retention/print/01_right_arm_fit_test.3mf` and test it on the actual right Rev H arm. After that passes, print `00_four_retainer_parts.3mf` once. It contains parts 15–18; the individual files are replacement alternatives. The coupon is not an installed retainer.

Use **OrcaSlicer** for preparation and toolpath review, as required by this project's `AGENTS.md`. The recorded process is OrcaSlicer 2.4.2, Bambu P1S, ASA, 0.4 mm nozzle, 0.20 mm layers, six walls, six top/bottom layers, 100% rectilinear infill, Arachne walls, 8 mm outer brim and supports off. The CAD already contains deliberate openings and hollow regions. These are reviewed starting settings, not qualification of other materials, printers or reduced wall/infill settings. Temperatures and drying must match the actual spool.

Keep supplied orientation and 100% scale. Arms print on their outer sides; other parts have their own baked orientations in the guides. **Rev H ducts 03 and 04 require both Bridge direction and Internal bridge direction at 180°, with Relative bridge angle and Align infill direction to model off.** Automatic bridge direction spans the long slots lengthwise. The corrected review crosses the slots, with a maximum unsupported span of 5.19 mm. Read `print_release_step/ORCA_BRIDGE_REVIEW.txt`. Do not apply that Rev H override indiscriminately to M1.

Use these slicer estimates, labeled as estimates and tied to the process and plate layouts above:

| Set | Filament | Estimated print time |
|---|---:|---:|
| M1.1 5560, with dam | 400.55 g | 15 h 42 m 30 s |
| M1.1 5560, without dam | 362.86 g | 12 h 49 m 10 s |
| M1.1 fit coupon | 35.09 g | 2 h 7 m 35 s |
| Rev H original fourteen parts | 1,183.88 g | 34 h 00 m 15 s |
| H-R1 four-part add-on | 59.21 g | 2 h 13 m 41 s |
| H-R1 right-arm coupon | 13.92 g | 39 min |

M1.1 uses 66.2% less estimated filament than the original complete Rev H set under that comparison. Rev H's comparison prints the four pins individually, whereas M1 combines hardware; a different plate layout changes startup overhead and time. Rev H's figure excludes H-R1. Coupon quantities are separate. Do not substitute solid CAD mass for slicer filament mass.

For H-R1, explain the service interaction prominently: all fourteen Rev H parts remain geometrically unchanged. The two external bars engage existing arm windows and retain the duct and upper rail without drilling the arms, extra metal fasteners, or adhesive at those two joints. The original keys and shoulders still carry the intended assembly loads. **Removing one bar releases both its duct and its rail. Remove the laptop and support both modules during service.** Release the keeper's split crown, pull the keeper down, then slide the bar outward. Retention force, bar stiffness, keeper life and warm ASA creep remain untested. H-R1 is a fixed-size add-on; editing the old Rev H parameter spreadsheet does not automatically adapt it.

Keep these evidence distinctions in the listing and any responses to adopters:

- Native checks, reopened models, STEP roundtrips, closed meshes and plate-clearance checks support the delivered geometry. Six M1 examples were checked at nine dam indices each. Sampled service motions are not a complete physical assembly test.
- The reviewed toolpaths contain no disconnected floating components. M1 still has unsupported overhang-wall runs up to 8.99 mm at the fan hanger and 6.12 mm at dam slots; its bridge-tagged maximum alone is only 3.02 mm. H-R1's maximum unsupported deposition span is 3.28 mm. These screens do not prove ASA sag or adhesion. The coupons target the relevant interfaces.
- M1 has no CFD or cooling benchmark. Rev F's historical simulations are not results for M1 or Rev H. Rev H has ongoing CFD commissioning with unresolved validation limits; link its current report if useful, but do not market it as proven suction, settled airflow or lower laptop temperatures. H-R1 preserves the original duct airways and adds no airflow result.

The CFD agent's latest coordination update identifies the new [four-hour exploratory sequence](https://thereprocase.github.io/dell-5560-wall-mount/simulation/revh-transient/sequence/). Its `simulation/revh-transient/sequence/run-status.json` is separate from the older four-frame pilot's `simulation/revh-transient/status.json`. Do not use the pilot file to report the new run's progress. Hourly videos are scheduled around 13:12, 14:12, 15:12 and 16:12 EDT on September 8, plus rendering time; those are publication targets, not evidence that a video or simulation milestone has completed. Recheck the sequence page when preparing listing links. The CFD agent will fetch and merge before each publication; reciprocate before any repository publication of your own. Keep this coordination detail in the handoff, not as a fixed schedule in the MakerWorld listing.

The ready-made ZIPs live under `docs/downloads/`: `Minimalist_M1_5560.zip`, the five other `Minimalist_M1_<preset>.zip` archives, `Minimalist_M1_Fit_Coupons.zip`, `Precision_5560_RevH_Prototype_STEP.zip`, `Precision_5560_RevH_Print_Set.zip`, and `Precision_5560_RevH_Removable_Retainers_R1.zip`. They are also available through the public guides. Use the manifests and `minimalist/reports/release.json` or `revh_retention/release-report.json` to verify identity. The M1 archives retain `M1` in their filenames; their release reports identify the contents as **M1.1**. Do not rename versions based only on the ZIP name.

Standard model 3MF files contain geometry and orientation, not printer settings. STEP and STL are alternative representations of the same parts. The assembled STEP is for inspection, not a printable plate. Separately labeled Orca review archives contain reviewed settings and embedded G-code; they are not automatically suitable MakerWorld print profiles or universal ready-to-print jobs.

Check MakerWorld's current model-image requirements, supported upload formats and print-profile attestations in its upload UI. Bambu's [published print-profile policy](https://blog.bambulab.com/makerworld-in-20-days/) requires real printed-result photographs as evidence. Do not mark a render as a real photograph or certify an unprinted profile as tested. Do not assume uploading raw models removes current model-photo requirements. If qualifying photos are missing, complete the files, description, gallery and draft, then identify the exact missing evidence. If the platform requires Bambu Studio for profile creation, explain that specific fallback, preserve the Orca-reviewed orientations and process, and inspect the resulting Bambu slice—especially the Rev H bridges. Saving a file through another slicer does not transfer the old validation to its new paths.

Use images from the matching current native model. Good M1 assets are `docs/assets/minimalist-native.png`, `minimalist-with-envelopes.png`, the wall-junction before/after images and `minimalist-key-diagram.svg`. Good H-R1 assets are `docs/assets/revh-retainers-installed.png`, `revh-retainers-lower.png`, `revh-retainers-upper.png` and `revh-retainers-removed.png`. Label CAD renders, transparent reference envelopes and added-material highlights accurately. Gold reinforcement is part of a single fused arm, not a separately printed insert. Supplement with genuine photographs of the exact printed revision when available. Avoid using the historical Rev F hero image as a current Rev H assembly photograph.

The repository's current license is **MIT**, copyright 2026 `thereprocase`. Include the license and preserve attribution; do not silently select a different license or enroll the existing public release in an exclusivity arrangement. If the platform cannot represent the intended license, resolve that specific choice with the owner. Use the owner's configured identity for any commits, with no AI author/co-author trailers or badges. Run a final privacy pass over upload files, image metadata, embedded paths and profile metadata, preserving intentional public attribution.

Ask early adopters to report the exact revision and preset, measured laptop and fan dimensions, printer/nozzle/material/settings, coupon results, difficult interfaces, bridge sag, cracking or keeper release problems, and photos showing the issue. Later cooling observations should record ambient temperature, workload, fan settings and dam position so comparisons are interpretable. Invite feedback through the listing and the linked repository without promising a load rating or a particular temperature reduction.

Your completion report should identify each listing or draft URL, the uploaded revision/files, included profiles and actual print evidence, chosen license, working guide links, and any specific unresolved publication requirement. Re-download a representative uploaded file and check its contents, units, orientation and completeness. Keep the public descriptions focused on choosing a variant, printing the coupon, assembling it and reporting useful results; the engineering history can remain in the linked documentation.

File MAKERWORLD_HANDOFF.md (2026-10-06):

# MakerWorld publication handoff

Publication is paused at the owner's request. The owner will finish physical prints and take lab photographs before returning. A new agent can resume from this document; the prior conversation is not required.

## Start here

- [Prepared package and downloads](makerworld/2026-09-08/README.md)
- [GitHub prerelease: MakerWorld preparation, 2026-09-08](https://github.com/thereprocase/dell-5560-wall-mount/releases/tag/makerworld-prep-2026-09-08)
- [Design-agent briefing](MAKERWORLD_BRIEFING.md), for engineering context and newer revisions
- [Native project inventory and individual 3MF hashes](makerworld/2026-09-08/verification.json)

The snapshot includes three listing drafts, fifteen labeled CAD gallery images, three raw model bundles, and sixty native Bambu Studio projects with cached toolpaths. Nothing has been uploaded or published on MakerWorld. There are no saved server drafts to recover.

## Three separate model families

| Listing title | Source and contents | Physical evidence at handoff |
|---|---|---|
| 15.6-inch Laptop Ducted Cooling Wall Mount | Rev H; all fourteen parts on nine explicitly assigned plates | Owner reports trying printed ducted hardware with a laptop. The preserved arms are specifically documented as printed. A complete Rev H assembly and these new profiles are not validated. |
| Modular Laptop Cooling Wall Mount | Minimalist M1.1; six measured raw size presets; sliced projects use the 5560 reference preset | Virtual review only; no physical print or assembly evidence supplied. |
| Minimal Laptop Wall Mount | Fanless curved/gusseted candidate from cloud-topo; pair of brackets and fit coupon | Virtual review only; no physical print or assembly evidence supplied. |

Do not collapse these into the two families described in the design briefing. The owner explicitly requested the fanless design as the third listing. H-R1 removable retention is an optional Rev H accessory linked in the ducted description; its four parts are not included in these fourteen-part profiles.

## Accepted printing choices

Use native Bambu Studio projects and Bambu PLA Basic, PETG HF, and ASA. The owner explicitly chose Bambu Studio for this package, overriding the repository's Orca default for this work. All projects use a 0.4 mm nozzle, textured PEI plate, 0.20 mm layers, four walls, six top/bottom layers, and **20% gyroid infill**. Do not restore the historical 100% infill comparison setup.

P1S, X1C, P2S, H2S, H2D, and H2C each have all three materials. A1 has PLA and PETG only. A1 mini is excluded. Each family has twenty projects. The six modular raw presets do not each have a full sliced printer matrix.

Keep one MakerWorld model listing per family. Group supported printers under a profile where the platform permits and the configuration is actually compatible. This grouping has not been configured or confirmed in MakerWorld. The archived files retain separate printer-specific cached G-code; do not relabel one printer's toolpaths for another printer.

The two duct objects use build-plate tree supports for long slot-roof edges identified in Bambu toolpaths. Settings include slim trees, a 30-degree threshold, 0.20 mm top contact gap, three top interface layers, and 0.35 mm XY gap. Other objects have support disabled. The user wanted supports placed with handling and visible surfaces in mind; physical removal quality and full-channel fit remain to be tested. Brims are 8 mm for ASA and 5 mm for PLA/PETG.

Shell counts are a prototype baseline, not proof of strength. PLA heat and sustained-load creep still matter. Do not claim a load, temperature, cooling, or universal laptop-fit rating.

## Evidence and source revisions

Main geometry was downloaded at `29c666e9c02812def1e6f23a56b6115a6c3e329d`. Fanless geometry was downloaded at cloud-topo `9fd0e98c43217678ce165d8f76c6a55abbf3c144`. The later design briefing at `8a3e1578beca56075d8f48235a3a1bac8fccd034` was incorporated; the compared main download archives and Rev H scene files were unchanged. This is a dated snapshot, not a promise that future main or cloud-topo geometry matches it.

All sixty projects passed archive integrity, saved-setting, embedded G-code/thumbnail, complete plate-object assignment, and slice-warning checks. Object counts are fourteen ducted, nine modular, and two fanless. Filament selections were checked. Public deliverables were scanned for the owner's local username, home paths, common personal email addresses, and image EXIF. These checks do not prove physical print quality or guarantee anonymity against every form of inference.

Fifty-four projects were generated by Bambu Studio 02.07.01.62. The six H2D/H2C ducted projects use 02.08.02.61. See each file's recorded application in the inventory. Renderings use actual CAD meshes with a simplified laptop envelope; they are labeled CAD renders and are not printed-object evidence.

## Resume after prints and photographs

1. Read this handoff, the dated listing drafts, and the current engineering briefing. Compare the photographed and printed revisions against the archived geometry before changing claims.
2. Record the actual printer, nozzle, filament, exact project filename/hash, changes made in the slicer, assembly results, and test conditions. Use the [test record template](makerworld/2026-09-08/TEST_RECORD.md).
3. Inspect full sliding fits, support removal, fan seating, fastener access, laptop insertion/removal, and pads. Keep structural, warm-creep, and cooling claims limited to recorded evidence.
4. Add clear real photographs of each complete printed design that will be listed. Preserve the accurate CAD renders as supplemental views. Obtain profile-specific print evidence before marking any new profile as tested.
5. Recheck MakerWorld's current [model upload guidelines](https://wiki.bambulab.com/en/makerworld/tutorials/model-upload-guidelines) and print-profile requirements. On 2026-09-08, the model guidelines require at least one clear actual printed-object photo per model gallery. Render-only galleries do not satisfy that requirement. This is a policy requirement; a hard form-level upload block was not established.
6. Review the signed-in MakerWorld account and public-facing metadata. The prior review found Repro / @Repro with no public real name, email, bio, or social links. Recheck the current state without copying private account details into public artifacts. Retain the project's MIT attribution and use the appropriate original-model upload type; no exclusivity enrollment was requested.
7. If Chrome file selection returns "Not allowed", enable "Allow access to file URLs" in the ChatGPT extension's Details page at chrome://extensions. See https://developers.openai.com/codex/app/chrome-extension#upload-files. This permission was unresolved at handoff. Do not assume old browser tab IDs or sessions still exist.
8. Publish the ready families when the owner resumes this task. Keep families without real photos or required profile evidence pending. Record each model URL, profile URL, revision, and actual testing state in the test record. Update testing notes as later prints and revisions are completed.

Use clear, broad titles and concise engineering prose. Describe the critical dimensions and measured fit limits. Avoid clickbait, unsupported cooling claims, emojis, and blanket compatibility language. The owner's preferred voice is precise, warm, direct, and readable.

## Known preparation traps

- Earlier scratch duct projects could export successfully while omitting parts from active plates. Only the final fourteen-part, nine-plate `RevH` projects in the release are approved snapshot artifacts. Do not recover old seeds or `_TreeDucts` variants from a working directory.
- H2D/H2C imported projects needed explicit selected-nozzle assignments (`extruder_nozzle_stats` and `nozzle_volume_type`). Those are present in the final files. A stock machine JSON alone did not initialize them correctly for the imported ducted project.
- The Windows Bambu CLI needed writable TEMP/TMP directories and a writable output working directory. Pass a filename, rather than an absolute path, to `--export-3mf`. Full flattened system profiles and correct printer compatibility were needed. Console diagnostics were visible through a terminal when redirected GUI-process logs were empty.
- Orca 2.5.0-dev's CLI invocation crashed in this session, although the owner launched its GUI successfully. This did not establish that the owner's Orca installation was unusable. Leave a working instance alone.
- The legacy duct coupon checks retained key and pin interfaces. It does not validate the revised full-length fan-tray fit. M1.1 needs at least 43 mm upward removal clearance; 25 mm fans need spacers for the 27 mm seat.

Large files are stored as GitHub release assets. Repository documents and gallery images provide the durable entry point. Preserve this dated snapshot and add a new dated package for later geometry or profile revisions.

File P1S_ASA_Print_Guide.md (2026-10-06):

> Current designs: [Minimalist M1 guide](https://thereprocase.github.io/dell-5560-wall-mount/minimalist-guide.html) and [preserved ducted Rev H](print_release/). For both Rev H ducts, use the [corrected Orca cross-slot bridge settings](print_release_step/ORCA_BRIDGE_REVIEW.txt). This older guide retains the original design and material context.

# P1S / ASA — Revision F

Print the supplied oriented 3MF files with your **P1S, 0.4 mm nozzle, ASA,
0.20 mm layers, 6 walls, 6 top/bottom layers, 100% infill, 8 mm outer brim and
supports off**. The explicit hollow CAD sections remain empty at 100% infill.
These are standard model files, not sliced G-code or a native Bambu project.

## Print the coupons first

00_FIT_COUPONS.3mf contains a male/female joint and a split-pin/socket pair.
Check the keyed fit with hand pressure. The mortise has 0.30 mm nominal side
clearance and an open-mouth 45° roof. Try the CA bond on a second coupon set.
The pin has a 4.0 mm shaft, a 4.2 mm split crown and a 4.1 mm socket. Its small
interference is intentional; printing variation can dominate that allowance.
Adjust the socket/clearance parameter if needed. Do not scale the complete mount.

## Part set and orientations

Print one each of 01–14. Parts 11–14 are four identical push-pins supplied in
their assembly positions in STEP and button-down in the print files. The 8 mm
and 16 mm outlet rails are alternatives to the default 12 mm pair.

- Cradles: **outer side down**, diagonal on the plate. Do not place them on the wall back.
- Ducts: inclined fan inlet becomes the horizontal bed face. The open duct
  grows toward its narrow end; the joint buttress supports the mounting saddle.
- Fan trays: grille down, fan pocket open upward.
- Fan caps: broad front face down. Pins: button down, split tip up.
- Outlet rails: lip down at Z=232. The contraction and key roofs stay within
  45° from vertical; the air skin has no broad suspended ceiling.

| Representative part | Oriented size, mm |
|---|---|
| 02_right_cradle | 196.3 × 180.6 × 44.0 |
| 04_right_fan_duct | 174.5 × 132.0 × 109.9 |
| 06_right_fan_retainer | 139.0 × 49.0 × 13.0 |
| 08_right_outlet_rail | 183.8 × 39.0 × 78.0 |
| 10_right_fan_tray | 139.0 × 132.0 × 38.0 |
| 12_right_push_pin | 8.0 × 8.0 × 14.0 |

All individual parts and their 8 mm brims fit the 256 mm bed and avoid its stock
front-left cutter exclusion. Keep the supplied bracket rotation. Inspect the
slice preview for machine-generated extras. Use ordinary/off timelapse for
these plates rather than adding a separate smooth-timelapse tower.

Intentional bridges: 18 mm inside the closed cradle spine, 10 mm lower cradle
pockets and 6.6 mm dovetail roofs. Have the slicer span their short widths.
The geometric 0.20 mm audit finds no detached starts; maximum sampled reach
beyond the prior layer's 45° envelope is 8.8 mm inside the 18 mm bridge.
This is a geometry audit, not validated Bambu extrusion paths or a print test.

## Starting process settings

Use the filament manufacturer's ASA profile. Start outer/inner walls around
80/120 mm/s, first layer and bridges around 25 mm/s, and volumetric flow around
12 mm³/s. Retain the filament profile's bridge cooling; keep auxiliary cooling
off to avoid a strong draft across large ASA parts. Start elephant-foot
compensation at 0.15 mm and brim separation at 0.10 mm, then judge the coupon.

The inspected Bambu ASA profile in Studio 2.8.2.61 uses 270 °C nozzle and
100 °C PEI bed for the P1S-compatible 0.4 mm setup. These are Bambu-brand
settings; another ASA spool may need its own values. Dry to the filament
maker's instructions. Keep the enclosure closed, avoid cold drafts, use the
plate maker's adhesive guidance, and let the plate cool before removal.

## Assemble with CA and printed pins

1. Dry-fit each duct's two keys into its cradle from the room side. Dry-fit
   its outlet rail the same way. Select the outlet gap before gluing.
2. Remove the laptop and fans from the work area. Clean the mating surfaces.
   Apply a suitable gap-filling CA to the key/mortise contact surfaces and
   saddle/arm seating faces. Press each part fully against its shoulder and
   keep it seated for the adhesive maker's complete cure schedule. The keys
   support vertical load; the CA bond locks withdrawal and must pass the coupon test.
3. Form two mirrored half assemblies. Each half uses one cradle, one duct and
   one outlet rail. Their center seams are nominal clearances; no center screw
   or glued butt seam is needed to carry the laptop.
4. Slide each fan tray into the duct's dovetails. Keep this joint dry so the
   tray remains removable. Fit a 120 × 120 × 25–27 mm fan and suitable thin
   pads. The airflow arrow points **upward and toward the wall at 45°**.
5. Route the fan wire through the cap notch, seat the cap and press in its two
   split pins by hand. Do not glue pins, caps, fan frames or sliding trays.
6. Install the two half assemblies with four wall bolts and broad washers.
   Wall-hole centers are X=±162 and Z=−36/+174 mm: 324 mm between the two
   vertical bolt lines and 210 mm between each line's holes. Keep the halves
   level and parallel. All four bolts face the room through clear tool paths.
7. Add approximately 2 mm rear contact pads. Fit front pads to the actual closed
   case so it rests securely without being squeezed. Keep pads off vents and
   ports. The reference underside sits 40 mm from the wall; the bare slot is
   26 mm. Verify the rear foot and noncontact cheek-lip clearance.
8. Leave about 110 mm above the hinge. Lift the laptop 105 mm, then pull it
   forward for keyboard access. Remove two pins and the cap to service a fan.

No M3/M4 screws, nuts or heat-set inserts remain. The four toggle bolts and
washers are the only metal mounting hardware. The wall/anchor capacity, CA bond
strength, pin pullout, warm creep and physical printing remain unqualified.

Sources: [Bambu ASA](https://bambulab.com/en-us/filament/asa),
[Bambu print-volume limitations](https://wiki.bambulab.com/en/knowledge-sharing/print-volume-limitations),
[Bambu official profiles](https://github.com/bambulab/BambuStudio/tree/v02.08.02.61/resources/profiles/BBL),
[Prusa's adhesive guidance](https://blog.prusa3d.com/the-great-guide-to-gluing-and-assembling-3d-prints_44908/).

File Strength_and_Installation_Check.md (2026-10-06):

# Revision F — limited structural screen

The printed sections meet the stated bending, bearing and shear screen.
Minimum ratio to an assumed stress limit: **1.19**.
The CA bonds and printed-pin pullout have not been qualified; this is not a
complete assembly load rating or FEA.

## Assumptions and method

2.5 kg laptop; 6 kg installed assembly; 1 kg per fan module; 3× gravity;
50 N outward hinge pull. Normal/bearing limit 5 MPa; shear limit 2 MPa;
effective modulus 1,000 MPa; local multiplier 1.5. These are chosen screening
values, not measured warm ASA strengths. Print on the supplied faces with
100% infill in the remaining solid sections. Designed cavities remain empty.

The exported cradle geometry supplies net section properties every 0.5 mm,
including hollow sections and unsymmetric bending. A 10% section allowance
remains. The rear-section extraction ignores added cheek stiffness. The check
does not resolve torsion, buckling, fatigue, impact or long-term creep.

The duct uses two 8 × 40 mm keys with 12.6 mm engagement, 21 mm apart. Their
lower shoulders carry vertical load and the moment from the sideways fan
offset. The saddle retains a 10 mm root with at least 40 mm net height. The
rail keys are 9 mm wide, 25 mm apart. Their sloped leading faces print without
unsupported ledges. The four split pins retain fan caps and carry no laptop load.

| Case | Stress MPa | Assumed limit MPa | Ratio |
|---|---:|---:|---:|
| shelf 3g | 3.12 | 5.0 | 1.60 |
| tines 50N hinge pull | 3.88 | 5.0 | 1.29 |
| rear rail combined | 4.19 | 5.0 | 1.19 |
| rear rail upper tail | 2.60 | 5.0 | 1.93 |
| duct key lower shoulder bearing | 1.41 | 5.0 | 3.54 |
| duct key root shear | 0.67 | 2.0 | 3.00 |
| duct saddle root bending | 1.51 | 5.0 | 3.32 |
| fan support ledge | 0.34 | 5.0 | 14.80 |
| rail key lower shoulder bearing | 0.47 | 5.0 | 10.70 |
| split pin shear | 1.17 | 2.0 | 1.71 |
| tray dovetail bearing | 0.25 | 5.0 | 20.39 |
| tray dovetail root shear | 0.12 | 2.0 | 16.31 |
| wall hole bearing | 1.27 | 5.0 | 3.92 |
| wall washer punching | 0.13 | 2.0 | 15.84 |

## Joint demands that still need physical qualification

- Each duct: 47.8 N outward couple demand for the stated 3g fan-module case.
  CA locks the keyed lap against withdrawal. The plastic shoulder calculation
  establishes neither adhesive peel resistance nor warm bond durability.
- Each printed pin: 7.4 N retention demand. The shear check passes;
  frictional pullout, repeated use and creep remain untested. Test the coupon.
- Each upper wall anchor: 63.5 N tension; conservative carrying-anchor shear
  89.2 N. Select toggle bolts for the actual wall and those loads.

Four Ø7 mm wall holes remain at X=±162, Z=−36/+174 mm. All four bolt axes remain
normal to the wall, with clear Ø16 mm room-side tool corridors. No other metal
fasteners or heat-set inserts are required.

Estimated installed mass, including conservative laptop/fan/hardware allowances:
4.41 kg. No service temperature or physical load rating is claimed.

Regenerate with build_mount.py, section_properties.py, then strength_check.py.

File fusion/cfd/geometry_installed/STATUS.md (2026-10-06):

# Installed ambient domain: geometry checkpoint

The exported CAD fluid is a valid, closed, single connected solid of 0.28534812883859545 m³. Its bounds are X ±400 mm, Y 0–450 mm, Z −300–500 mm. The laptop cavity probe (0,45,100) mm lies in this connected ambient component. Twelve disconnected closed pockets were excluded and are individually recorded in `geometry_manifest.json`.

The fluid subtracts the 14 printed assembly solids, vented laptop shell, and two simplified Noctua housing rings. It does not subtract actuator or grille markers. All four fan-zone volumes and the grille-marker volume are inside the selected fluid (each directional outside-fluid Boolean volume is zero).

The laptop internal layout is an explicitly unmeasured surrogate. Only its shell was included in the native helper STEP export. Hidden Dell actuator and grille markers were reconstructed from the exact native helper recipe and exported parameter metadata; provenance is recorded in the manifest. No fan pressure-flow curves or resistance values were invented.

## Failed surface gate

The five named ASCII STL patches use metres and partition every surface triangle exactly once. Their union has 24,428 triangles, 12,354 vertices, **672 open edges**, zero nonmanifold edges, and zero self-intersections detected by FreeCAD. It is **not watertight and is not ready for CFD meshing**. Removing the original BRep's triangulation cache did not resolve the open edges. Coordinate rounding from 1e-12 through 1e-6 metres did not merge these seams, so this is not merely a tiny duplicate-coordinate issue.

A diagnostic STEP export/reimport produced a mesh with zero open edges. However, equivalence is unproven: coincident Boolean comparison returned near-whole-domain residual volumes of 285,463,059.11833507 and 285,348,316.5141635 mm³, despite a raw volume difference of only 0.01776677370071411 mm³. That result was rejected. The delivered patches are from the original BRep, with their failed seam check preserved; no displacement, hole filling, or silent tolerance relaxation was applied.

Next geometry work should diagnose the original BRep's shared-edge tessellation or establish independent, sufficiently strong surface equivalence for the STEP roundtrip. An OpenFOAM surfaceCheck and subsequent volume-mesh quality check are still required. The earlier sealed baseline separately has two reported OpenFOAM self-intersection locations; it remains an initial baseline, not a substitute for this installed model.

No production solver case or flow/thermal result was produced. Dell blower pressure-flow curves/RPM, grille and fin resistance, and geometric dimensions remain unresolved physical inputs. `geometry_ready` and `solver_case_ready` are both false.

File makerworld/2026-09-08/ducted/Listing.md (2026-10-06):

# 15.6-inch Laptop Ducted Cooling Wall Mount

A wall mount for a closed laptop, with two 120 mm fans and ducts that direct air toward its underside. The laptop lifts out for access. The fan trays slide out for service.

This is the full ducted design, Revision H. It uses the Dell Precision 5560 as its dimensional reference. Other laptops can fit when their case dimensions, feet, ports, and vents match the available space. Screen size alone does not establish fit.

**Early-adopter prototype:** complete physical fit, retention, warm creep, and cooling remain unqualified. Start with a fit coupon and a supported trial assembly.

## Fit and geometry

| Feature | Dimension or function |
|---|---|
| Reference laptop | 344.4 × 230.3 × 20 mm, closed |
| Bare laptop slot | 26 mm; padding consumes this space |
| Reference rear gap | 40 mm from the wall |
| Fans | Two 120 × 120 × 25–27 mm fans |
| Fan direction | 45° upward and toward the wall |
| Wall fasteners | Four; 324 mm between bolt lines and 210 mm vertically |
| Service clearance | About 110 mm above the hinge |
| Sliding interfaces | 0.30 mm nominal clearance |
| Duct bends | Three R12 internal blends and two R14 external blends per duct |

The rounded duct transitions connect the fixed inlet and outlet shapes. The sampled bend wall is at least 1.60 mm thick. These are geometry checks; they do not establish a measured cooling improvement.

## Print and assemble

Print one of each numbered part, 01–14. Preserve the supplied orientations. The cradles lie on their outer sides; the ducts print inlet-down. The trays print grille-down, the rails lip-down, and the pins button-down.

The included legacy coupon checks the retained key and pin interfaces. It does not validate the revised full-length fan-tray fit. The new complete Bambu projects place all fourteen parts on nine named plates.

The Bambu Studio projects use 0.20 mm layers, four walls, six top and bottom layers, and 20% gyroid infill. PLA Basic, PETG HF, and ASA are separate material choices. Use the project for your printer and filament.

Tree supports apply only to the two duct parts. They address the slot-roof edges identified during Bambu toolpath review. Remove the supports before fitting the fan trays. Check the full sliding channels for remaining support material. The other parts have supports disabled.

Dry-fit the joints before assembly. The duct and outlet-rail joints use adhesive; the fan trays, caps, and pins remain removable. Fit compliant pads to the actual laptop without blocking vents or ports. Select wall anchors for the wall construction and applied load.

## Development status

The owner reports physically printing and trying ducted hardware with a laptop; the preserved arms are specifically documented as printed. These newly prepared material and printer profiles have only virtual review. That earlier physical use does not validate a complete Revision H assembly or the new profiles.

Load capacity, warm creep, anchor capacity, adhesive performance, and cooling results have no published rating. PLA needs particular care near heat and under sustained load. Additional shell layers do not remove those limits.

The gallery shows CAD renders. The laptop is a dimensional envelope; the download does not include a laptop or fans. Revisions and physical test results will be recorded here. Fit reports are welcome; include your laptop dimensions, material, printer, and the revision used.

Source revision: main 29c666e9c02812def1e6f23a56b6115a6c3e329d. Source license: MIT, copyright 2026 thereprocase.

## Optional removable retention

The separate H-R1 accessory uses two external bars and two keepers to retain the duct and upper rail. It fits Rev H, not the modular M1.1 mount. It uses the existing arm windows and replaces adhesive retention at those two joints.

Removing one bar releases both the duct and the rail on that side. Remove the laptop and support both modules before removing a bar. Retention force, keeper life, and warm creep remain untested. Print its right-arm fit coupon before the four accessory parts.

[H-R1 installation guide and files](https://thereprocase.github.io/dell-5560-wall-mount/revh-retainers.html) · [Interactive models and current revisions](https://thereprocase.github.io/dell-5560-wall-mount/) · [Source files and issue reports](https://github.com/thereprocase/dell-5560-wall-mount)

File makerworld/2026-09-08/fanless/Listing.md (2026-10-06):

# Minimal Laptop Wall Mount

Two open brackets hold a closed laptop against a wall. There are no fans, ducts, or backplate. Curved ribs and six tapered gussets per bracket put material around the contact tabs and wall connections.

This is the latest fanless design from the cloud-topo branch. It targets low material use while retaining an open grip area above the brackets.

**Early-adopter prototype:** physical fit and load testing remain open. Start with the fit coupon and a supported trial assembly.

## Fit and geometry

| Feature | Dimension |
|---|---|
| Reference laptop | 344.4 × 230.3 × 20 mm, closed |
| Slot width, normal to laptop faces | 22 mm |
| Nominal face clearance | 1 mm per face |
| Nominal side clearance | 0.5 mm per side |
| Outward lean | About 4.2° |
| Rear gap at bottom / top | 21.0 / 37.9 mm |
| Minimum gap in the upper grip region | 32 mm |
| Side web / contact reach / wall-pad reach | 4.8 / 16 / 24 mm |
| Fastener clearance | Four Ø7 mm holes |
| Washer / tool clearance | Ø15 / Ø16 mm envelopes |
| Vertical hole spacing | 114 mm |

The laptop slides down along the tilted slot. Lift it along that direction to remove it. Leave overhead space for this movement. Padding consumes the 1 mm face clearance; it has no separate allowance.

The mounting openings use peaked roofs around the round tool clearance. These roofs avoid broad, flat overhangs. Install the brackets with the laptop removed so the driver can approach each screw from the room.

## Print and fit

Print the fit coupon first. Check the laptop edge, bolt, washer, head, and driver with the actual hardware. Then print one left and one right bracket, broad outer cheek down. Preserve that orientation.

The new Bambu Studio projects use 0.20 mm layers, four walls, six top and bottom layers, and 20% gyroid infill. The P1S PETG HF slice estimates about 69.5 g for the pair, including the brim. This is a slicer estimate, not a measured print weight.

PLA Basic, PETG HF, and ASA have separate profiles. Material changes need their own fit and load checks. Extra walls cannot make PLA insensitive to heat or long-term loading.

## Development status

This is an unprinted fit and print prototype. CAD assembly, geometry checks, and virtual slicing do not establish a safe load rating. Physical fit, warm creep, fastening, and handling tests remain open. Port access, cable routing, and lid opening also need checks on the actual laptop.

The gallery shows CAD renders. The laptop is a simplified dimensional envelope. Revision and physical test results will be added as development continues. Reports should include the laptop dimensions, filament, printer, and revision.

Source revision: cloud-topo 9fd0e98c43217678ce165d8f76c6a55abbf3c144. Source license: MIT, copyright 2026 thereprocase.

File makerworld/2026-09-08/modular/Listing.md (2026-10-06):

# Modular Laptop Cooling Wall Mount

An open wall mount with separate laptop arms, removable 120 mm fan holders, and optional adjustable air guides. Choose a measured size preset, then set both air guides to the same height.

Minimalist M1.1 removes the full ducts and keeps the parts independent. The reinforced arms use wider wall pads and tapered webs at the wall junction. The fan holders, caps, keys, and retainers can be replaced separately.

**Early-adopter prototype:** complete physical fit, retention, warm creep, and cooling remain unqualified. Start with the fit coupon and a supported trial assembly.

## Choose by case dimensions

Measure the closed laptop, including its feet. Check the ports, vents, and cable bends. The size labels are examples, not universal fit claims.

| Preset | Width × depth × thickness, mm |
|---|---|
| 5560 reference | 344.4 × 230.3 × 20 |
| 13-inch example | 304 × 210 × 16 |
| 14-inch example | 320 × 220 × 18 |
| 15.6-inch example | 360 × 245 × 24 |
| 16-inch example | 360 × 250 × 24 |
| 17-inch example | 400 × 275 × 28 |

## Geometry that matters

The reference design leaves a 40 mm wall gap and uses separate 2 mm contact pads. Two 120 × 120 × 27 mm fan envelopes sit at 45° and direct air upward into that gap.

Each optional air guide has nine positions, numbered 0–8, at 12 mm pitch. Its key spans two rungs, or 24 mm. Use matching positions on both sides. The supplied installed render shows position 8.

Leave space for at least 43 mm of upward laptop movement when removing it. A 25 mm fan needs suitable spacing in the modeled 27 mm seat. Check the fan body, wire exit, and connector before assembly.

M1.1 widens the wall pads to 32 mm. Paired 6 mm webs taper 16 mm forward from the wall junction. Nominal sliding clearance is 0.30 mm. The split retainers have intentional interference; print the fit coupon before the full set.

## Parts and printing

For the complete set, print parts 01–08 and hardware plate 21. Plate 21 already contains hardware 09–20. Do not print that hardware twice. Without the optional air guides, use parts 01–06 and hardware plate 22.

The Bambu Studio projects currently cover the 5560 reference size. Other measured presets are supplied as separate model files. Do not scale a complete assembly to obtain another fit: scaling also changes joints, fan seats, and fastener holes.

The new profiles use 0.20 mm layers, four walls, six top and bottom layers, and 20% gyroid infill. Separate projects use Bambu PLA Basic, PETG HF, or ASA. Preserve the supplied build directions. Mount the arms level and parallel with anchors suited to the wall and load.

## Development status

This design has CAD assembly and virtual print review. It has not yet been physically printed or tested with a laptop. The new print profiles are also untested physically. There is no validated load, creep, retention, or cooling rating.

The gallery contains CAD renders and a simplified laptop envelope. Physical test results and revisions will be added as development continues. Fit reports are welcome; include the preset, laptop dimensions, filament, printer, and revision.

Source revision: main 29c666e9c02812def1e6f23a56b6115a6c3e329d. Source license: MIT, copyright 2026 thereprocase.

[Illustrated print and assembly guide](https://thereprocase.github.io/dell-5560-wall-mount/minimalist-guide.html) · [Interactive models and current revisions](https://thereprocase.github.io/dell-5560-wall-mount/) · [Source files and issue reports](https://github.com/thereprocase/dell-5560-wall-mount)

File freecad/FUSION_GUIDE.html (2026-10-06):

# Your FreeCAD workspace

The top tabs switch native workbenches; the command strip underneath follows the selected workspace.

Fusion habit | Here
Pan / orbit / zoom | Middle-drag / Shift+middle-drag / mouse wheel (Revit navigation)
Design solid | SOLID → CREATE: create a Body, then sketches and Pad/Pocket features.
Sketch workspace | SKETCH: sketch geometry and dimensional constraints. Finish sketch returns control to feature modeling.
Extrude / combine separate solids | SOLID: Extrude, Union and Cut. Most of this mount uses this native feature family.
Browser / feature history | Model tree at left. Expand a feature to find its sketch and dependencies. FreeCAD does not provide Fusion's bottom timeline.
Feature dialog | Tasks panel at right. Select a feature in the tree and use its Data properties or double-click to edit where supported.
Change parameters | MODIFY → Change parameters opens the model's organized spreadsheet. Blue cells are inputs; gray/reference cells explain derived or frozen values.
Assembly | SOLID → ASSEMBLE exposes native links and joints. The installed assembly is separate from source construction groups.
Inspect | SOLID → INSPECT provides Measure, Fit and standard views.
Visibility / multiselect | Space toggles selected objects. Ctrl adds to selection.

## Printing constraint

Both gray cradles/arms are frozen because printing has started. Do not change shared arm dimensions. Teal outlet-rail refinements must fit the frozen arm baseline in frozen_print_arms/.

## Appearance and recovery

Matte teal, graphite and gold with dark outlines; solid background #9EA6AD. The local workspace module reapplies the theme and ribbon at startup. Preferences and layout backups live beside the model. Keep app error reporting available through View → Panels → Report view; logs are captured by the model's local runner.

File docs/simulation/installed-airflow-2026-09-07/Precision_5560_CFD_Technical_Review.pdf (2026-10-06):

PRECISION 5560 / WALL-MOUNT COOLING

# Installed airflow / system overview

Parallel-projection flow views | Actual reconstructed solution | Four idealized fan actuators

SIMULATION TECHNICAL REVIEW

REV A | 07 SEP 2026 | A3 LANDSCAPE

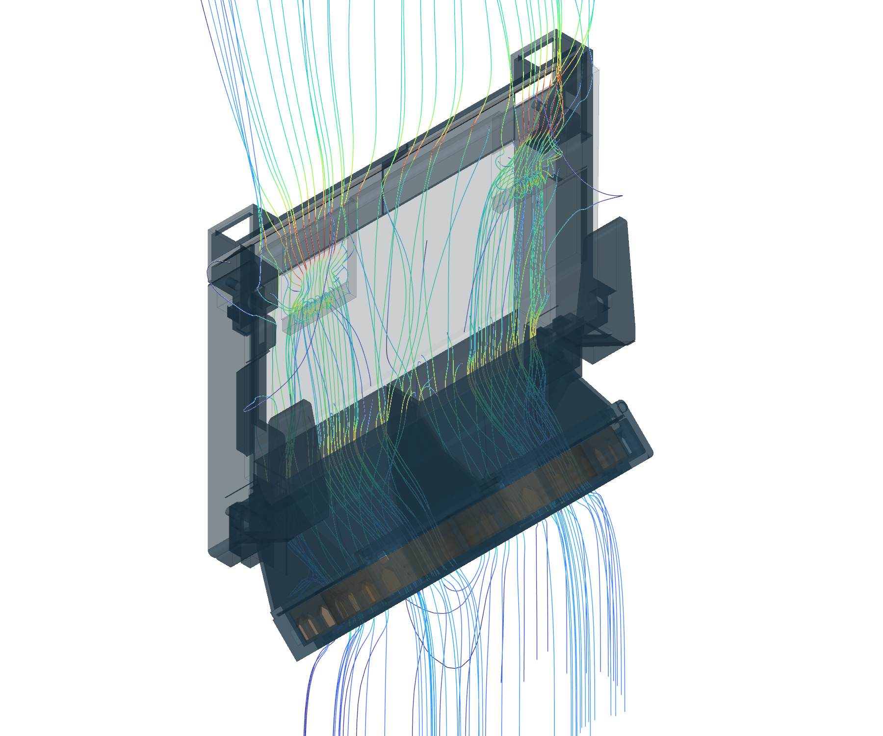
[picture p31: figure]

D5560-CFD-001

CASE: installed_pressure10_v3

EXPLORATORY / NOT CONVERGED

Airflow only. Assumed fan forcing. Not a manufacturing release.

UNITS: mm, m/s, Pa | VIEWS: NTS
Saved solution: iteration 1200 | 836,278 cells

01 / 07

0 | Speed [m/s] | 5

### 01 / MODEL SCOPE

### Native mount assembly, traced laptop envelope, twin intake windows, internal surrogate ducts and two

external fan housings.

### 02 / OPERATING ASSUMPTION

### Four constant-force actuators, each based on nominal 10 Pa pressure rise. No manufacturer fan

curve or measured grille / fin resistance.

3.52 / 3.55

Left / right sampled intake flow [CFM]
4.93

Maximum cell speed [m/s]

### 03 / REVIEW STATUS

### The run reached its 1200-iteration limit. Integral intake flows changed less than 0.7% from iteration

400; residual convergence was not achieved.

Streamlines show selected seeded paths, not total airflow allocation. Paths are clipped by the view frame.

# Geometry / orthographic reference

A | VIEW FROM +Y / LOOKING -Y | B | VIEW FROM +X / LOOKING -X

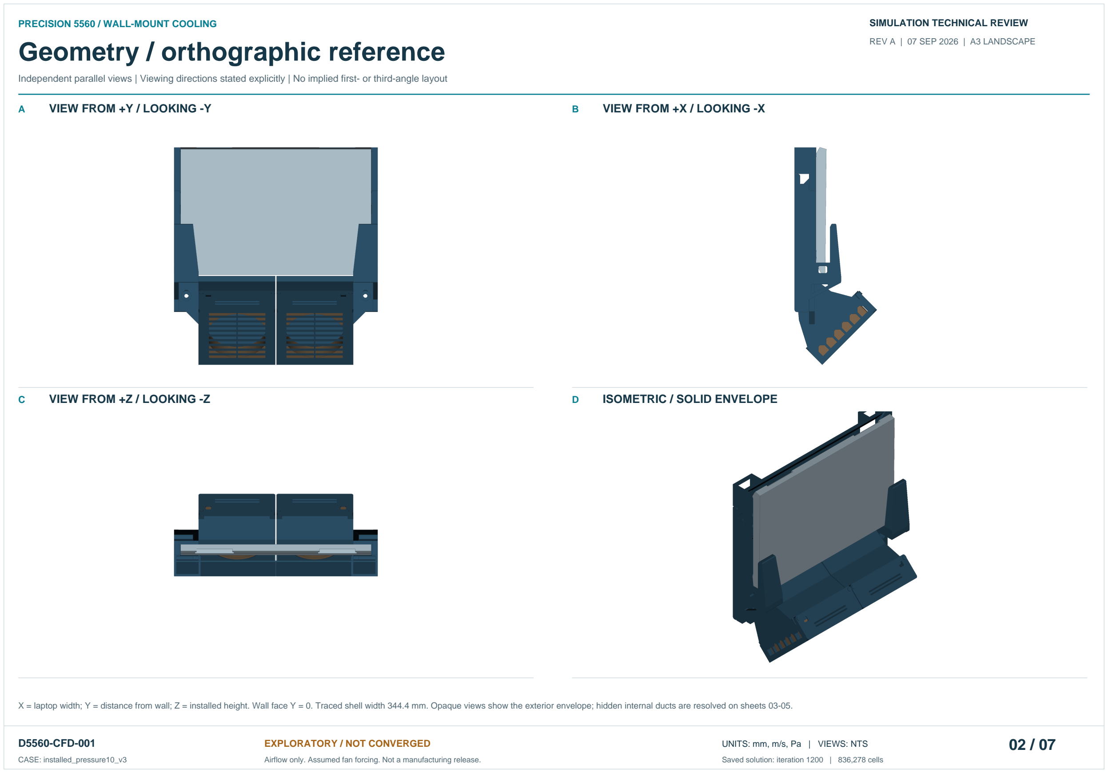
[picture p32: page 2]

Independent parallel views | Viewing directions stated explicitly | No implied first- or third-angle layout

02 / 07

C | VIEW FROM +Z / LOOKING -Z | D | ISOMETRIC / SOLID ENVELOPE

X = laptop width; Y = distance from wall; Z = installed height. Wall face Y = 0. Traced shell width 344.4 mm. Opaque views show the exterior envelope; hidden internal ducts are resolved on sheets 03-05.

# Longitudinal sections / fan-to-laptop path

A-A: X = -111.017 mm | B-B: X = +111.264 mm | Scalar: speed | Equal axis scaling

03 / 07

A-A LEFT FAN / DUCT CENTRE | B-B RIGHT FAN / DUCT CENTRE

### SECTION REGISTER

A

A

B

B

344.4 mm

X-Z locator / schematic, +X to right

### READING THE SECTIONS

The external fans sit below the laptop. The narrow cavity within the shell connects the active intake window to the hinge outlet. White areas indicate solid geometry or invalid samples.

### GEOMETRY CONFIDENCE

Envelope traced from the project reference: approximately +/-2 mm. Intake locations: approximately +/-4 mm. Internal ducts and fan placement are engineering surrogates.

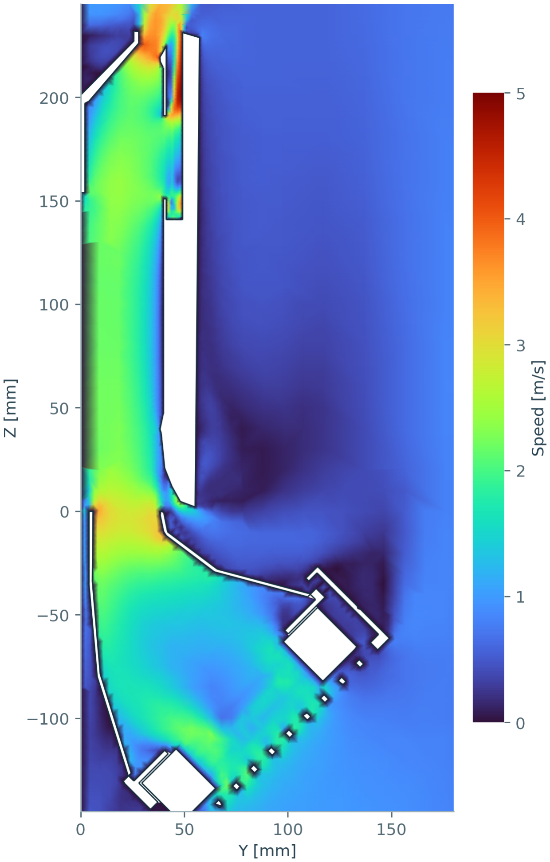
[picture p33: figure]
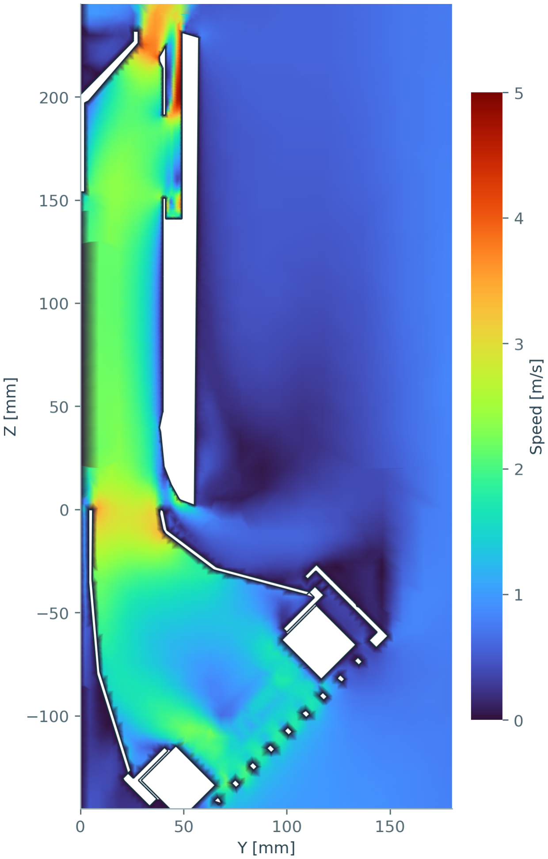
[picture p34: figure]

Dark lines: intersection of CAD-derived surfaces with the section plane. Color field: interpolated velocity on cut cells; 0-5 m/s on all speed sheets.

# Internal duct plane / velocity and pressure

C-C: Y = 45.000 mm | Plane passes through both simulated internal fan regions

04 / 07

### 01 SPEED MAGNITUDE

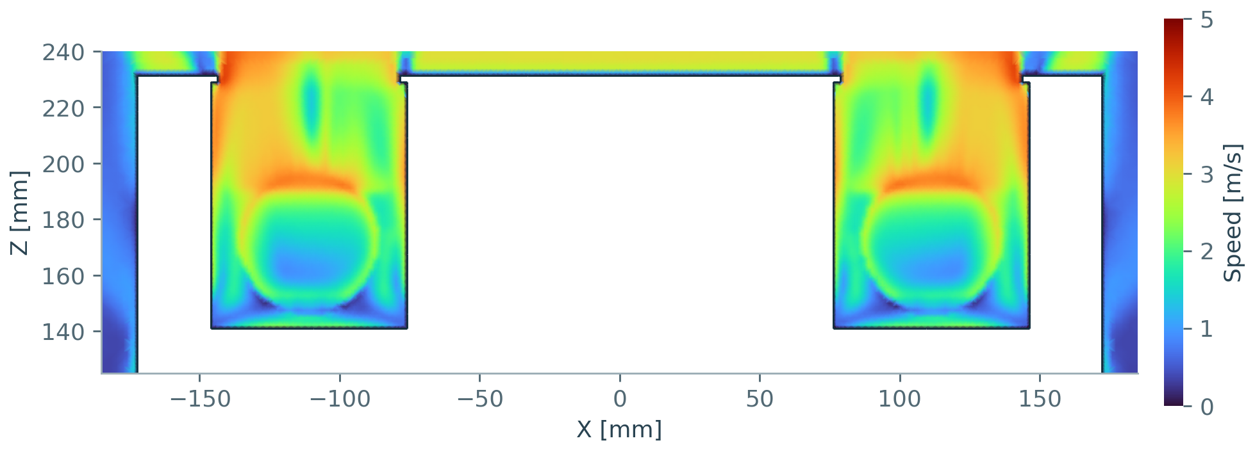
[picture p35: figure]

### 02 GAUGE PRESSURE

### PLANE LOCATION

### Y is measured outward from the wall. The assumed duct spans Y = 41.2 to 49.2 mm; this section lies inside its 8

mm depth.

### PRESSURE CONVENTION

### OpenFOAM stores kinematic pressure. The plotted

gauge pressure is p multiplied by rho = 1.2 kg/m3, referenced to the zero-pressure ambient boundary.

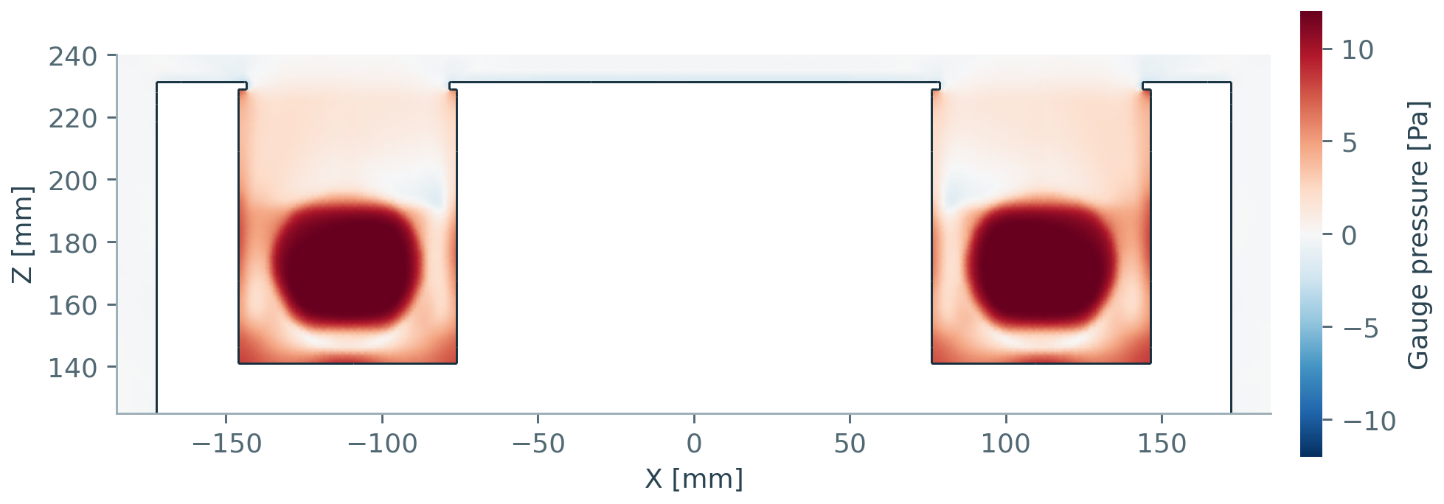
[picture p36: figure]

### INTERPRETATION

### The two isolated colored passages are the modeled internal ducts. The white central region is solid laptop

surrogate. The color maps are not temperature fields.

### DISPLAY LIMITS

Speed: 0 to 5 m/s. Pressure: -12 to +12 Pa, with saturation outside this range. Cells VTK cannot contour are omitted; gaps are not filled.

# Transverse intake section / reverse perspective

D-D: Z = 171.119 mm | Intake-centre section with rear-side streamline context

05 / 07

### D-D HORIZONTAL SECTION THROUGH ACTIVE INTAKES

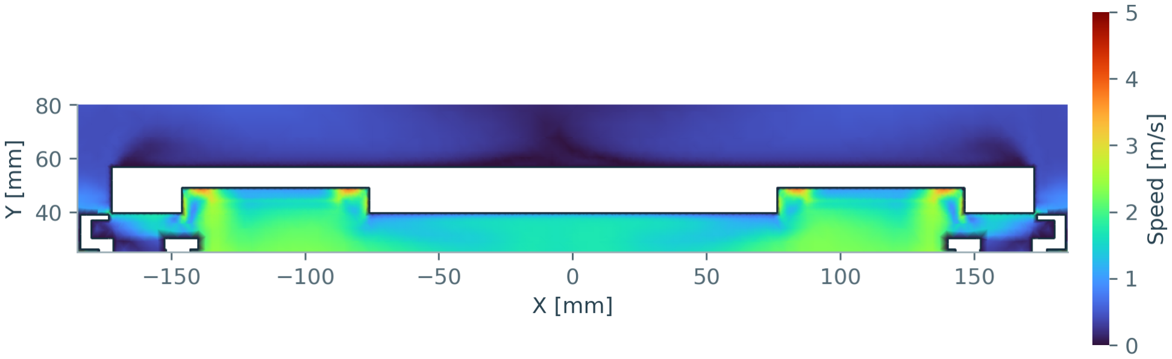
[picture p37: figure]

### 01 REVERSE OBLIQUE / FLOW CONTEXT FLOW SAMPLES AT THE INTAKES

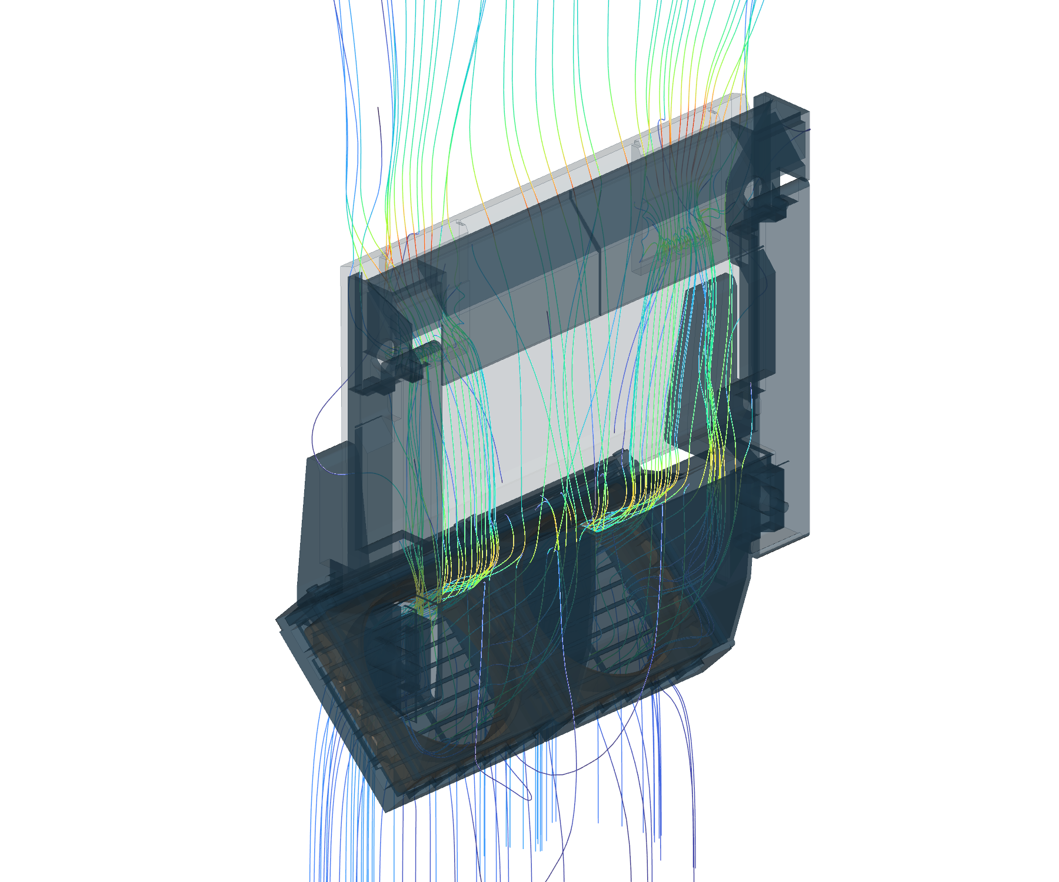
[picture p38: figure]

Rectangle quadrature at Y = 40.5 mm, with positive flow into the laptop. All quadrature points were valid at both intakes.

Location | Iteration 400 | Iteration 1200
Left intake | 3.498 CFM | 3.520 CFM
Right intake | 3.522 CFM | 3.546 CFM

Less than 0.7% change in these integral quantities. This is local stability evidence; it does not establish complete field convergence or real fan performance.

# Mesh resolution / local section details

Actual cut mesh over the speed field | Display triangulation includes diagonals added for rendering

06 / 07

01 | EXTERNAL FAN / DUCT REGION | 02 | INTERNAL DUCT / INTAKE DETAIL

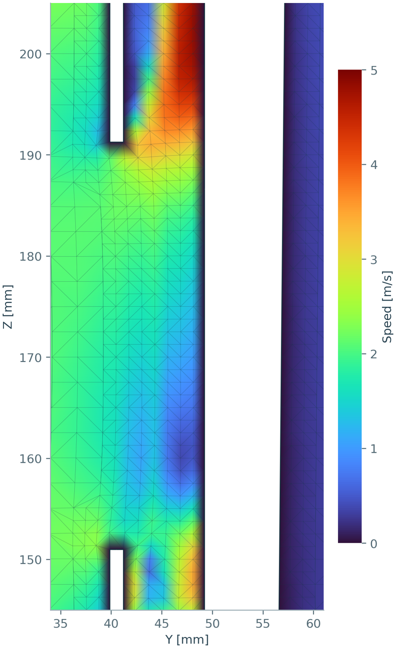
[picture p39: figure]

### MESH INVENTORY

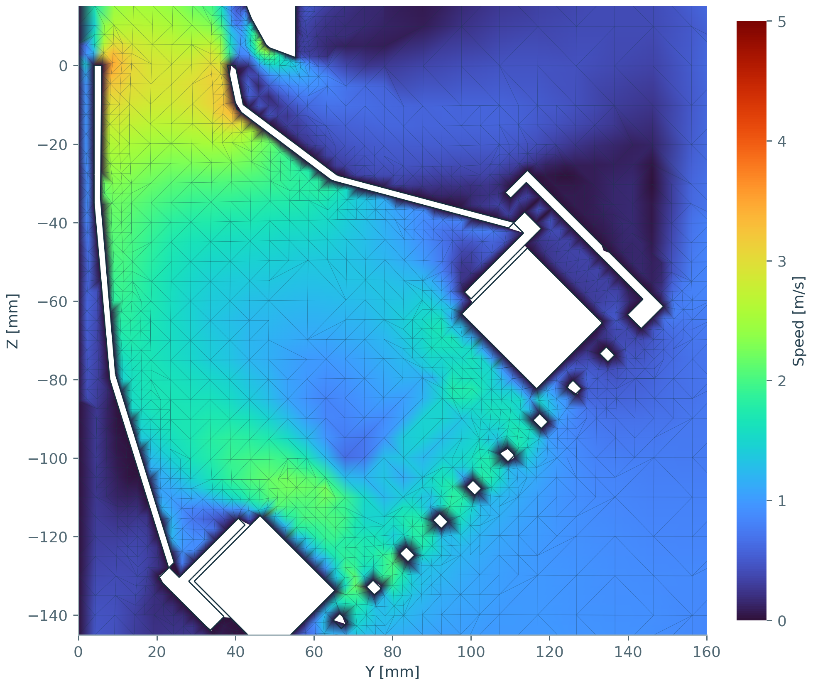
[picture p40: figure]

Cells
836,278

Fluid regions
1

Maximum skewness
2.496

Max non-orthogonality

## 64.69 deg

Minimum determinant
0.000683

### QUALITY DISPOSITION

Standard checkMesh: Mesh OK. Expanded diagnostics flag one low-determinant cell plus concave cells and warped faces. The surface is closed and passed the self-intersection check.

No prism layers; mesh independence and wall resolution are unverified. Cell faces in the fluid mesh are polyhedral; shown triangles are section-rendering subdivisions.

Numerical fan thickness: the external actuator zones were broadened from 2 to 10 mm while preserving total force, selecting 2033 / 2032 cells. Internal Dell zones contain 2438 / 2443 cells. Marker bodies are not obstacles. This is a coarse exploratory mesh, not a released validation mesh.

# Convergence / evidence and assumptions

First initial residual per field and SIMPLE iteration | Saved result: 1200 | Elapsed solver time: 1166 s

07 / 07

### FINAL INITIAL RESIDUALS

Ux | 4.797e-05
Uy | 6.977e-05
Uz | 6.449e-05
p | 2.955e-05
k | 1.974e-04
omega | 5.490e-06

Iteration limit reached.
The 1e-5 residual target was not met.

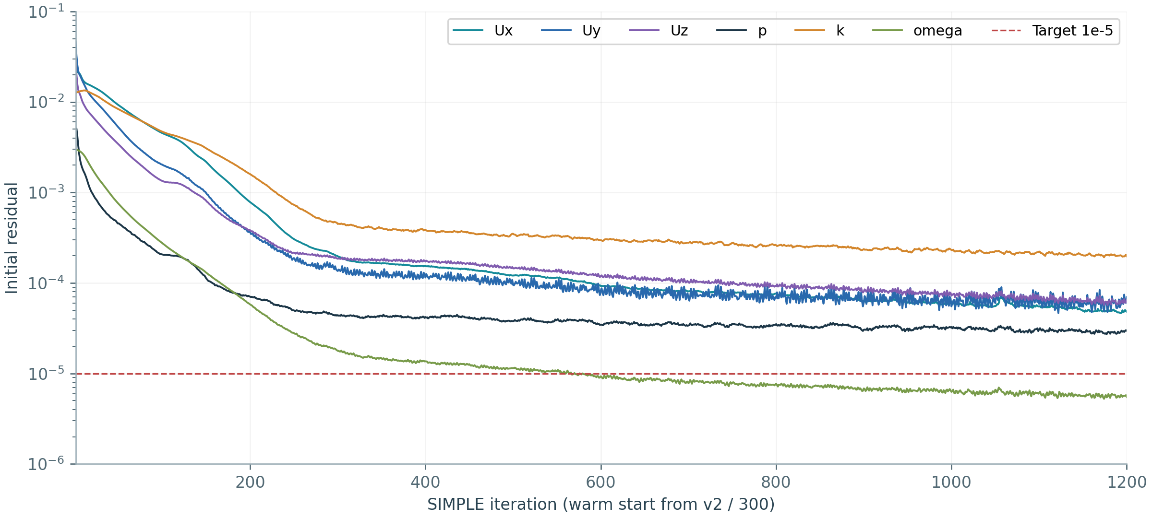
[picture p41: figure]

### METHOD / PHYSICS

Steady incompressible SIMPLE; k-omega SST; first-order bounded-upwind momentum. Density 1.2 kg/m3; kinematic viscosity 1.5e-5 m2/s. No-slip walls and zero-gauge-pressure ambient openings.

No thermal transport, CPU heat load, fan P/Q curves, grille porosity or fin-stack resistance. Intake values are uncalibrated model outputs.

### MODEL / PROVENANCE

BARAM bundled OpenFOAM v2412, build 6467f461-20260821; Microsoft MPI, eight workers. Warm start from v2 iteration 300.

Source geometry: native mount assembly and traced CFD helper. Profile and intake reconstruction: project profile_reconstruction.json. Final field reconstruction completed normally.

### SOURCE FILES / REPRODUCTION

Case: installed_pressure10_v3
Fields: 1200/ and constant/polyMesh/
Log: log.simpleFoam_windows
Samples: results/iteration_1200/flow_samples.json Views: drawing_assets.py
Layout: build_drawing_package.py

The companion manifest records source hashes, cut planes, units and the PDF digest.

Prepared for engineering review. Figures are rendered simulation views, not certified fabrication drawings.

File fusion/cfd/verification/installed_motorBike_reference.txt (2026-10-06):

FILE /usr/lib/openfoam/openfoam2412/tutorials/incompressible/simpleFoam/motorBike/constant/turbulenceProperties
/*--------------------------------*- C++ -*----------------------------------*\
| =========                 |                                                 |
| \\      /  F ield         | OpenFOAM: The Open Source CFD Toolbox           |
|  \\    /   O peration     | Version:  v2412                                 |
|   \\  /    A nd           | Website:  www.openfoam.com                      |
|    \\/     M anipulation  |                                                 |
\*---------------------------------------------------------------------------*/
FoamFile
{
    version     2.0;
    format      ascii;
    class       dictionary;
    object      turbulenceProperties;
}
// * * * * * * * * * * * * * * * * * * * * * * * * * * * * * * * * * * * * * //

simulationType      RAS;

RAS
{
    RASModel        kOmegaSST;

    turbulence      on;

    printCoeffs     on;
}

// ************************************************************************* //

FILE /usr/lib/openfoam/openfoam2412/tutorials/incompressible/simpleFoam/motorBike/constant/transportProperties
/*--------------------------------*- C++ -*----------------------------------*\
| =========                 |                                                 |
| \\      /  F ield         | OpenFOAM: The Open Source CFD Toolbox           |
|  \\    /   O peration     | Version:  v2412                                 |
|   \\  /    A nd           | Website:  www.openfoam.com                      |
|    \\/     M anipulation  |                                                 |
\*---------------------------------------------------------------------------*/
FoamFile
{
    version     2.0;
    format      ascii;
    class       dictionary;
    object      transportProperties;
}
// * * * * * * * * * * * * * * * * * * * * * * * * * * * * * * * * * * * * * //

transportModel  Newtonian;

nu              1.5e-05;

// ************************************************************************* //

FILE /usr/lib/openfoam/openfoam2412/tutorials/incompressible/simpleFoam/motorBike/system/fvSchemes
/*--------------------------------*- C++ -*----------------------------------*\
| =========                 |                                                 |
| \\      /  F ield         | OpenFOAM: The Open Source CFD Toolbox           |
|  \\    /   O peration     | Version:  v2412                                 |
|   \\  /    A nd           | Website:  www.openfoam.com                      |
|    \\/     M anipulation  |                                                 |
\*---------------------------------------------------------------------------*/
FoamFile
{
    version     2.0;
    format      ascii;
    class       dictionary;
    object      fvSchemes;
}
// * * * * * * * * * * * * * * * * * * * * * * * * * * * * * * * * * * * * * //

ddtSchemes
{
    default         steadyState;
}

gradSchemes
{
    default         Gauss linear;
    grad(U)         cellLimited Gauss linear 1;
}

divSchemes
{
    default         none;

    div(phi,U)      bounded Gauss linearUpwindV grad(U);

    turbulence      bounded Gauss upwind;
    div(phi,k)      $turbulence;
    div(phi,omega)  $turbulence;

    div((nuEff*dev2(T(grad(U))))) Gauss linear;
}

laplacianSchemes
{
    default         Gauss linear corrected;
}

interpolationSchemes
{
    default         linear;
}

snGradSchemes
{
    default         corrected;
}

wallDist
{
    method          meshWave;
}

// ************************************************************************* //

FILE /usr/lib/openfoam/openfoam2412/tutorials/incompressible/simpleFoam/motorBike/system/fvSolution
/*--------------------------------*- C++ -*----------------------------------*\
| =========                 |                                                 |
| \\      /  F ield         | OpenFOAM: The Open Source CFD Toolbox           |
|  \\    /   O peration     | Version:  v2412                                 |
|   \\  /    A nd           | Website:  www.openfoam.com                      |
|    \\/     M anipulation  |                                                 |
\*---------------------------------------------------------------------------*/
FoamFile
{
    version     2.0;
    format      ascii;
    class       dictionary;
    object      fvSolution;
}
// * * * * * * * * * * * * * * * * * * * * * * * * * * * * * * * * * * * * * //

solvers
{
    p
    {
        solver          GAMG;
        smoother        GaussSeidel;
        tolerance       1e-7;
        relTol          0.01;
    }

    Phi
    {
        $p;
    }

    U
    {
        solver          smoothSolver;
        smoother        GaussSeidel;
        tolerance       1e-8;
        relTol          0.1;
        nSweeps         1;
    }

    k
    {
        solver          smoothSolver;
        smoother        GaussSeidel;
        tolerance       1e-8;
        relTol          0.1;
        nSweeps         1;
    }

    omega
    {
        solver          smoothSolver;
        smoother        GaussSeidel;
        tolerance       1e-8;
        relTol          0.1;
        nSweeps         1;
    }
}

SIMPLE
{
    nNonOrthogonalCorrectors 0;
    consistent yes;
}

potentialFlow
{
    nNonOrthogonalCorrectors 10;
}

relaxationFactors
{
    equations
    {
        U               0.9;
        k               0.7;
        omega           0.7;
    }
}

cache
{
    grad(U);
}

// ************************************************************************* //

FILE /usr/lib/openfoam/openfoam2412/tutorials/incompressible/simpleFoam/motorBike/0.orig/U
/*--------------------------------*- C++ -*----------------------------------*\
| =========                 |                                                 |
| \\      /  F ield         | OpenFOAM: The Open Source CFD Toolbox           |
|  \\    /   O peration     | Version:  v2412                                 |
|   \\  /    A nd           | Website:  www.openfoam.com                      |
|    \\/     M anipulation  |                                                 |
\*---------------------------------------------------------------------------*/
FoamFile
{
    version     2.0;
    format      ascii;
    class       volVectorField;
    object      U;
}
// * * * * * * * * * * * * * * * * * * * * * * * * * * * * * * * * * * * * * //

#include        "include/initialConditions"

dimensions      [0 1 -1 0 0 0 0];

internalField   uniform $flowVelocity;

boundaryField
{
    #includeEtc "caseDicts/setConstraintTypes"

    #include "include/fixedInlet"

    outlet
    {
        type            inletOutlet;
        inletValue      uniform (0 0 0);
        value           $internalField;
    }

    lowerWall
    {
        type            fixedValue;
        value           $internalField;
    }

    motorBikeGroup
    {
        type            noSlip;
    }

    #include "include/frontBackUpperPatches"
}

// ************************************************************************* //

FILE /usr/lib/openfoam/openfoam2412/tutorials/incompressible/simpleFoam/motorBike/0.orig/k
/*--------------------------------*- C++ -*----------------------------------*\
| =========                 |                                                 |
| \\      /  F ield         | OpenFOAM: The Open Source CFD Toolbox           |
|  \\    /   O peration     | Version:  v2412                                 |
|   \\  /    A nd           | Website:  www.openfoam.com                      |
|    \\/     M anipulation  |                                                 |
\*---------------------------------------------------------------------------*/
FoamFile
{
    version     2.0;
    format      ascii;
    class       volScalarField;
    object      k;
}
// * * * * * * * * * * * * * * * * * * * * * * * * * * * * * * * * * * * * * //

#include        "include/initialConditions"

dimensions      [0 2 -2 0 0 0 0];

internalField   uniform $turbulentKE;

boundaryField
{
    #includeEtc "caseDicts/setConstraintTypes"

    //- Define inlet conditions
    #include "include/fixedInlet"

    outlet
    {
        type            inletOutlet;
        inletValue      $internalField;
        value           $internalField;
    }

    lowerWall
    {
        type            kqRWallFunction;
        value           $internalField;
    }

    motorBikeGroup
    {
        type            kqRWallFunction;
        value           $internalField;
    }

    #include "include/frontBackUpperPatches"
}

// ************************************************************************* //

FILE /usr/lib/openfoam/openfoam2412/tutorials/incompressible/simpleFoam/motorBike/0.orig/omega
/*--------------------------------*- C++ -*----------------------------------*\
| =========                 |                                                 |
| \\      /  F ield         | OpenFOAM: The Open Source CFD Toolbox           |
|  \\    /   O peration     | Version:  v2412                                 |
|   \\  /    A nd           | Website:  www.openfoam.com                      |
|    \\/     M anipulation  |                                                 |
\*---------------------------------------------------------------------------*/
FoamFile
{
    version     2.0;
    format      ascii;
    class       volScalarField;
    object      omega;
}
// * * * * * * * * * * * * * * * * * * * * * * * * * * * * * * * * * * * * * //

#include        "include/initialConditions"

dimensions      [0 0 -1 0 0 0 0];

internalField   uniform $turbulentOmega;

boundaryField
{
    #includeEtc "caseDicts/setConstraintTypes"

    #include "include/fixedInlet"

    outlet
    {
        type            inletOutlet;
        inletValue      $internalField;
        value           $internalField;
    }

    lowerWall
    {
        type            omegaWallFunction;
        value           $internalField;
    }

    motorBikeGroup
    {
        type            omegaWallFunction;
        value           $internalField;
    }

    #include "include/frontBackUpperPatches"
}

// ************************************************************************* //

FILE /usr/lib/openfoam/openfoam2412/tutorials/incompressible/simpleFoam/motorBike/0.orig/nut
/*--------------------------------*- C++ -*----------------------------------*\
| =========                 |                                                 |
| \\      /  F ield         | OpenFOAM: The Open Source CFD Toolbox           |
|  \\    /   O peration     | Version:  v2412                                 |
|   \\  /    A nd           | Website:  www.openfoam.com                      |
|    \\/     M anipulation  |                                                 |
\*---------------------------------------------------------------------------*/
FoamFile
{
    version     2.0;
    format      ascii;
    class       volScalarField;
    object      nut;
}
// * * * * * * * * * * * * * * * * * * * * * * * * * * * * * * * * * * * * * //

dimensions      [0 2 -1 0 0 0 0];

internalField   uniform 0;

boundaryField
{
    #includeEtc "caseDicts/setConstraintTypes"

    frontAndBack
    {
        type            calculated;
        value           uniform 0;
    }

    inlet
    {
        type            calculated;
        value           uniform 0;
    }

    outlet
    {
        type            calculated;
        value           uniform 0;
    }

    lowerWall
    {
        type            nutkWallFunction;
        value           uniform 0;
    }

    upperWall
    {
        type            calculated;
        value           uniform 0;
    }

    motorBikeGroup
    {
        type            nutkWallFunction;
        value           uniform 0;
    }
}

// ************************************************************************* //

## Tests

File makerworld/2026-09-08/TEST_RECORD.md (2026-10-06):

# Physical print and publication record

No completed physical test records were supplied for these sixty profiles at the 2026-09-08 handoff. Copy this block for each actual print. Fill entries from observation; leave unknown items explicit.

## Print record

- Date and design family:
- Geometry revision / source commit:
- Project filename and SHA-256:
- Printer, nozzle, plate, and slicer version:
- Filament brand, material, and spool condition:
- Changes from the archived profile:
- Printed parts and completeness of assembly:
- Fit coupon and full-length joint observations:
- Support removal and touched-surface observations:
- Laptop dimensions, pads, and insertion/removal clearance:
- Fasteners, anchors, fans, spacers, and retention arrangement:
- Test load, duration, ambient / part temperature, and observations:
- Cooling test method and measured results, if any:
- Failures, limitations, and required revisions:
- Photograph filenames (complete object, installed view, joint detail):
- MakerWorld model and profile URLs, after publication:
- Exact claims justified by this evidence:

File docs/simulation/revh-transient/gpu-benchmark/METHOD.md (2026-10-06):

# Revision H GPU assessment - 8 September 2026

Keep the CPU backend for the next CFD run. The tested CUDA pressure solver
took **219.86 seconds versus 178.31 seconds on CPU** for the same ten steps on
the 3,193,565-cell duct mesh: 23.3% longer. All five field RMS comparisons pass,
but maximum local pressure and velocity differences exceed the preset
comparison tolerance. The tested GPU backend is not accepted for production.

The four-frame startup movie remains an archived commissioning record. No
replacement long sequence, sustained shedding result or settled lip-suction
result has been completed. Hundreds of actual samples and a longer physical
window are still needed; repeated or interpolated frames do not supply them.

## Measured comparison

Both duct runs use WSL OpenFOAM 2412 patch 260127, four MPI ranks, identical
mesh/decomposition/initial fields, quiescent initial velocity, the same SST
model, four fan sources, 10 microsecond fixed steps and 120 pressure solves.
Only the pressure solver changes: CPU GAMG versus CUDA GKOCG with block Jacobi.
Full fields are written at the 0.1 ms endpoint.

| Measurement | CPU | GPU |
|---|---:|---:|
| Solver process wall time | 178.31 s | 219.86 s |
| Mean step after first three | 16.29 s | 19.86 s |
| Total pressure iterations | 474 | 18,907 |
| Maximum iterations in one pressure call | 16 | 730 |
| Maximum logged Courant number | 0.00213 | 0.00213 |
| Turbulence bounding events | 5 | 5 |
| Final relative mass imbalance | 1.89e-7 | 3.04e-7 |

This is one sequential trial per backend on a shared desktop, not a repeated
performance study. Timing includes solver startup, function objects and the
endpoint field write; it excludes meshing, decomposition and reconstruction.
A 1.4-second geometry render ran near GPU-case setup; other desktop work was
also active. Sampled total-device memory peaked at 3,643 MiB during the GPU
run, including other applications. This is not an isolated solver allocation.

`compare_cfd_fields.py` reads the original OpenFOAM scalar64 binary values,
avoiding VTK's possible float32 cell-field conversion. It hashes geometry,
cell zones, initial fields, properties, forcing and spatial schemes. The
criterion, set before the large comparison, is RMS and maximum field error
at most `1e-7 + 1e-4 * reference` using the corresponding reference magnitude.

Maximum U-component difference: 6.25e-5 m/s. Maximum kinematic-pressure
difference: 0.00838 m2/s2, or 0.0101 Pa at the assumed density of 1.2 kg/m3.
Both exceed the strict maximum-error rule. This does not quantify error
against hardware. The tolerance was not relaxed after seeing the result.
Compact logs, inputs, hashes and comparisons are in
`docs/simulation/revh-transient/gpu-benchmark/`; original fields stay local.
Published text uses LF line endings; the artifact checksums cover those bytes.
Original logs remain in their source cases.

## Functional trials

- RTX 3080 Ti, compute capability 8.6, 12,884,377,600 reported device bytes.
  A compiled CUDA 12.4 double-precision kernel checked 1,048,576 values with
  zero maximum error. This is a runtime check, not a CFD speedup.
- A 4,800-cell momentum-source fixture runs ten 0.2 ms steps. CUDA block
  Jacobi with default `scaling 1` passes all five field comparisons against
  the CPU, including maximum errors. The larger case still needs its own check.
- Block Jacobi with `scaling -1` exits zero but gives grossly wrong fields.
  Source inspection finds RHS scaling without corresponding use of the stored
  matrix-wrapper scaling member. No adapter-source patch was made.
- Experimental multigrid crashes with CUDA illegal memory access at both
  scaling signs; `ranksPerGPU 1` also fails. The crash cause remains unresolved.

## Isolated runtime

The [OpenFOAM Ginkgo Layer](https://github.com/hpsim/OGL) supplies CUDA linear
solvers while retaining OpenFOAM models and function objects. It does not
move mesh generation or the whole CFD solver to the GPU.

- OGL commit: `d3e80f4651ebe8b7383af4b746a6c3a43f87bc3e`.
- Ginkgo requested ref `ogl_0600_gko190`, resolved commit
  `ac44187f33ed1aa0c0fe9436dc86b25a860374ba`, reported version 1.10.0.
- Isolated root: `/home/user/code/dell5560-cfd-gpu-20260908`.
- Matching OpenFOAM source 2412.260127-1 and libopenmpi-dev 4.1.6-7ubuntu2
  packages were unpacked locally. No system packages or Windows BARAM solver
  were changed. Build and install completed beneath the isolated root.
- CUDA architecture 86; CUDA/OpenMP/reference enabled; HIP/SYCL, GPU-aware MPI
  and mixed precision disabled. Transfers use host staging.
- Configure recipe: `gpu/configure_ogl.sh`.
- MPI initially hung contacting X11 at localhost port 6001. The child-process
  environment `HWLOC_COMPONENTS=linux,stop`, with DISPLAY, WAYLAND_DISPLAY and
  XAUTHORITY unset, permits workers to start. No desktop setting was changed.

`benchmark_revh_backend.py` creates fresh cases and enforces timeouts that stop
only their own process groups. Source OpenFOAM's `etc/bashrc` before enabling
shell `set -e`; add the isolated `install/lib` and CUDA `lib64` to the child's
`LD_LIBRARY_PATH`. `export_revh_backend_evidence.py` creates compact evidence;
it does not push or deploy it.

## Mesh candidates remain provisional

`generate_revh_sequence.py` preserves Revision H geometry and the original
18.2M-cell case. It requests 0.25 mm targets in 16 mm-wide lip strips at
X=+/-111 mm, 0.5 mm selected full-span edges, 1 mm selected passages and 2 mm
general surfaces. These are changed meshes, not grid-convergence evidence.

- **05: 3,193,565 cells.** Standard checks pass. Four low-determinant cells
  (minimum 0.0002218), 71,820 concave cells; minimum face weight 0.05272.
  Poor wall-layer coverage. Used only for the bounded backend benchmark.
- **06: 3,405,599 cells.** Absolute 0.1 mm first layers plus refinement at
  05's four defects. Rejected: 765 low-determinant cells, 514 low-weight faces,
  eight low-volume-ratio faces, one bad decomposition tet and 88,041 concave
  cells. Improved layer coverage did not justify the quality regression.
- **07: 3,868,774 cells.** Smaller relative layers with less erosion give
  average layer counts 2.09/4 printed, 3.19/4 laptop and 0.995/2 fan housings.
  Rejected: 975 low-determinant cells (minimum 0.0001396), 11 low-weight faces
  (minimum 0.03290) and 130,554 concave cells. Expanded checks fail three.

No quality threshold was lowered to call these candidates validated. A long
production solve has not been launched on them.

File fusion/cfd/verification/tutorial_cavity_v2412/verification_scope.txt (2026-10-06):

Official cavity; modified only local endTime/writeInterval; 30 s per-command timeout.

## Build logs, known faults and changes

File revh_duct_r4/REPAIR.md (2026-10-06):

# Clear the four fan-cover pin sockets

The D4 CAD and Orca projects correct the plastic wall crossing these sockets.
For existing printed ducts, try controlled cleanup before deciding
whether replacements are needed. Physical success has not yet been reported.

1. Work on a cooled duct on the bench, with its cover and pin removed. Use the
   existing round opening to guide a **4.1 mm drill bit in a hand pin vise**.
2. Set a firm depth stop so the **tip can enter at most 6.0 mm from the flat
   duct socket face**. Measure from the duct face, not through an installed cover.
   Keep the bit aligned with the existing hole; turn slowly by hand and clear chips.
3. Repeat for all four sockets, two per duct. These are **blind holes**: do not
   drill through. The CAD bottom is 7.7 mm deep, and that is not a drilling target.
4. Refit each cover and matching split pin. Confirm seating, retention and
   removal by hand. Stop if it binds; do not hammer the pin or deepen the hole
   past the stop. Record which socket and pin were checked.

The 6.0 mm limit includes the pointed tip. A nominal model check of 4.1 mm bits
with 90°, 118° and 135° points clears the unwanted pin obstruction while leaving
at least 1.7 mm to the original blind bottom and preserving the intended crown
contact. Material may remain farther behind the pin tip; complete excavation of
the nominal bore is unnecessary for this repair. The check cannot account for
actual print shrinkage, drilling angle or the condition of the printed wall.

[Modelled repair check](printed-repair-validation.json) ·
[Original diagnosis and section](evidence/pin-hole-obstruction.json)

Replacement projects are `slices/03_left_fan_duct/03_left_fan_duct.gcode.3mf` and
`slices/04_right_fan_duct/04_right_fan_duct.gcode.3mf`. Open them as OrcaSlicer
projects; keep the supplied orientation and review settings for the actual printer.

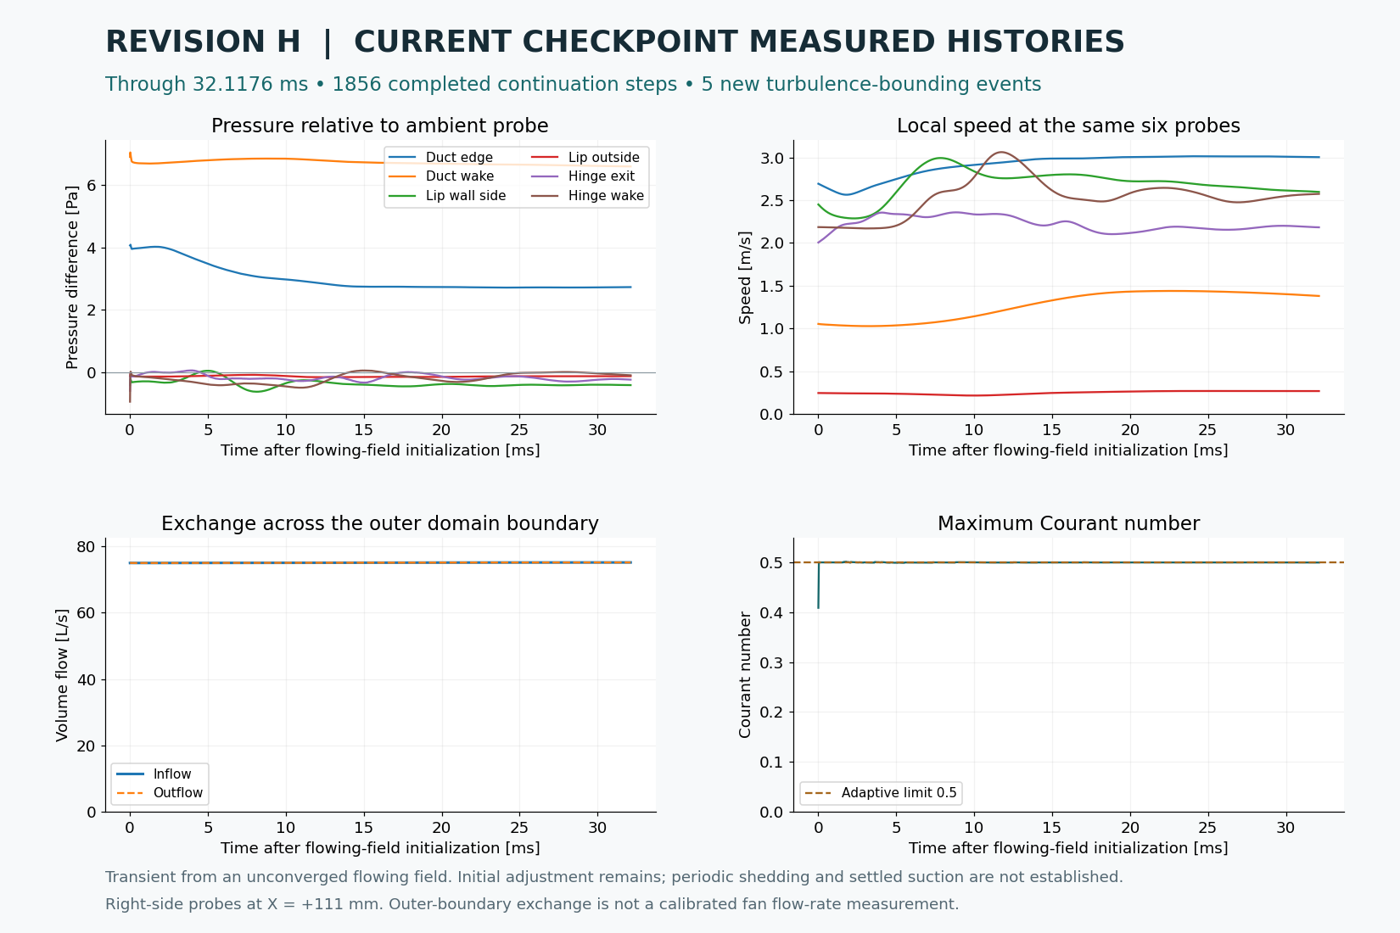
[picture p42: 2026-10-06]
docs/simulation/revh-transient/sequence/flowing/checkpoint-09/history.png

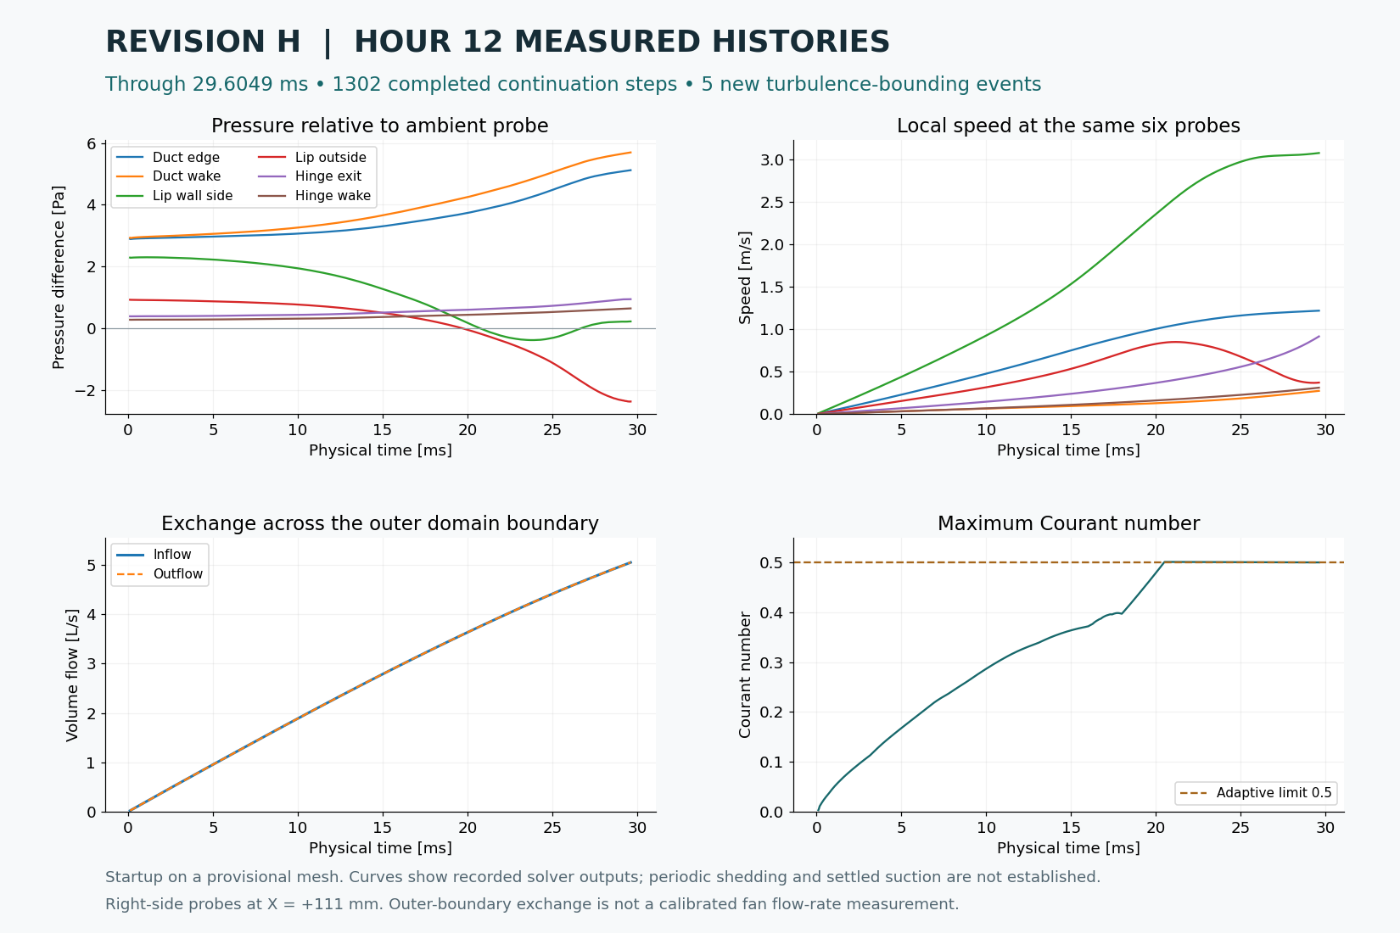
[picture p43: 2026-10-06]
docs/simulation/revh-transient/sequence/hour-12/history.png

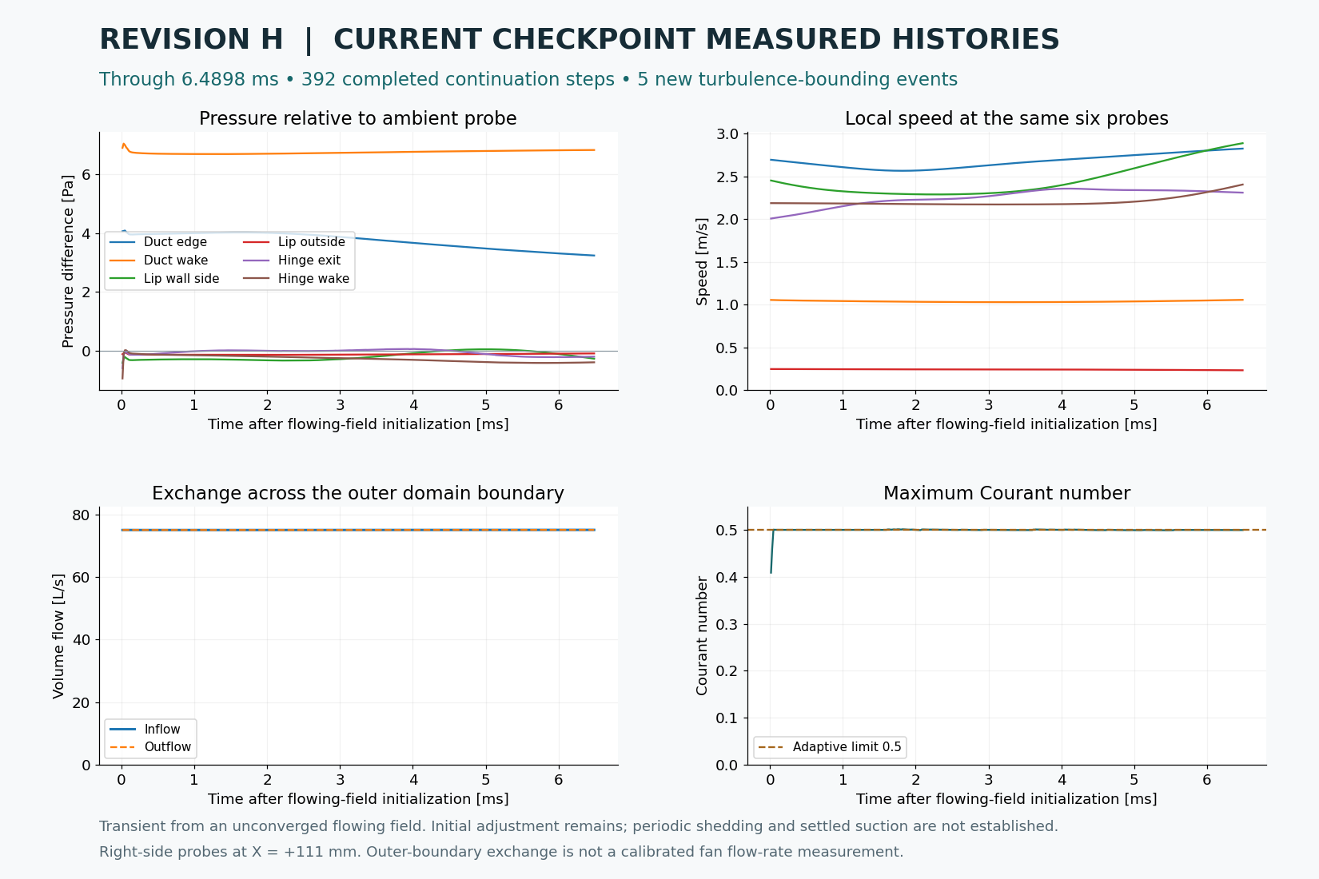
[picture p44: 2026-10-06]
docs/simulation/revh-transient/sequence/flowing/checkpoint-03/history.png

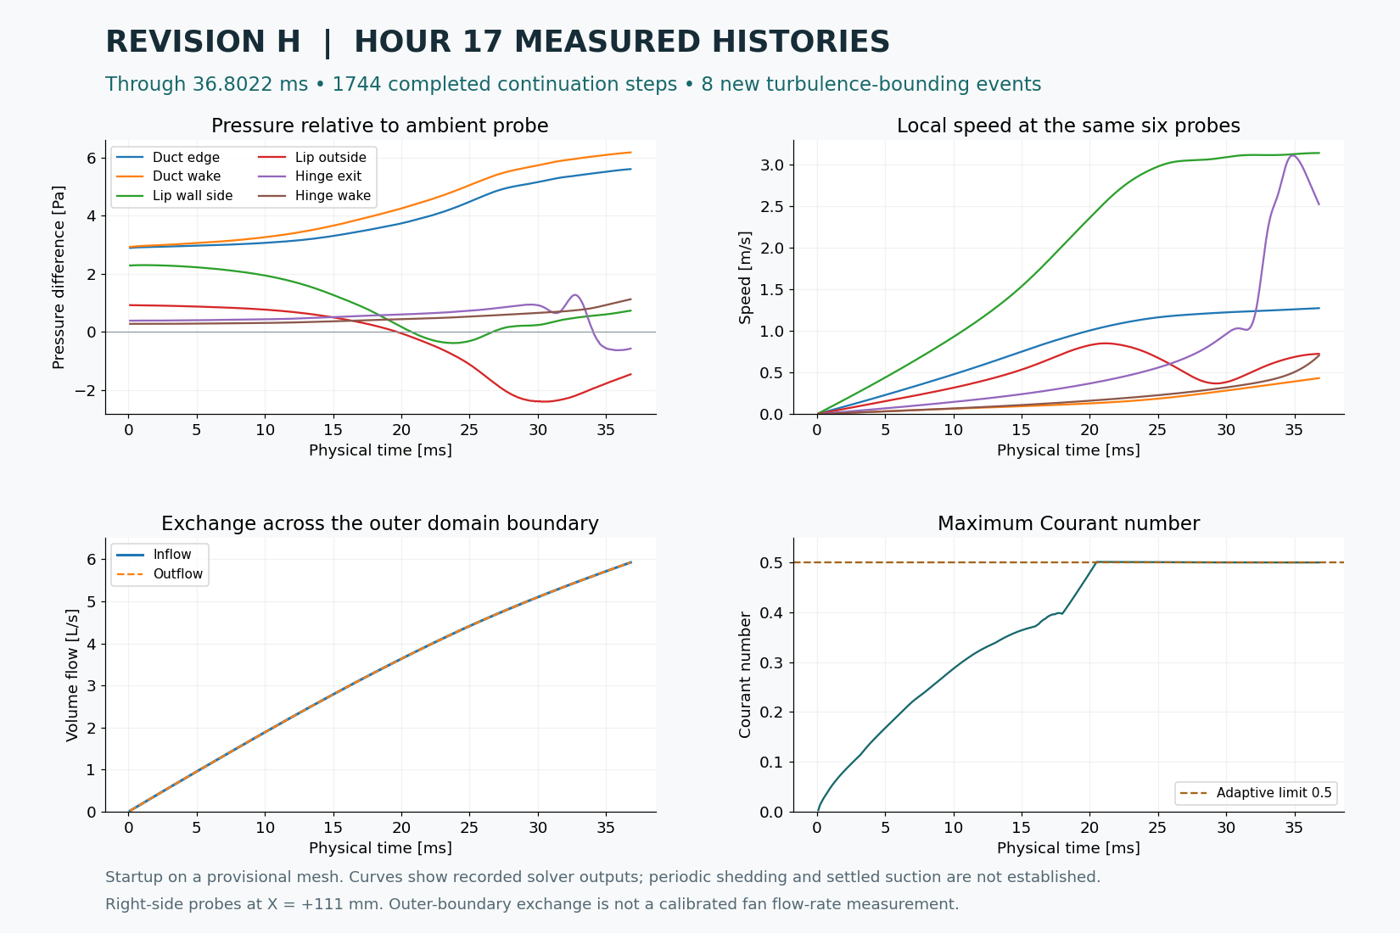
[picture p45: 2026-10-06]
docs/simulation/revh-transient/sequence/hour-17/history.png

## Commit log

2026-10-06 Publish privacy-reviewed laptop hardware snapshot
    [00_FIT_COUPONS.3mf, 00_FIT_COUPONS.stl, 00_cable_fit_coupon.3mf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]
2026-10-06 Let wrapped wall-mount navigation expand the header
